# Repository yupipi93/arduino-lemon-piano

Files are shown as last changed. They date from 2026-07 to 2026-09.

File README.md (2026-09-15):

<div align="center">

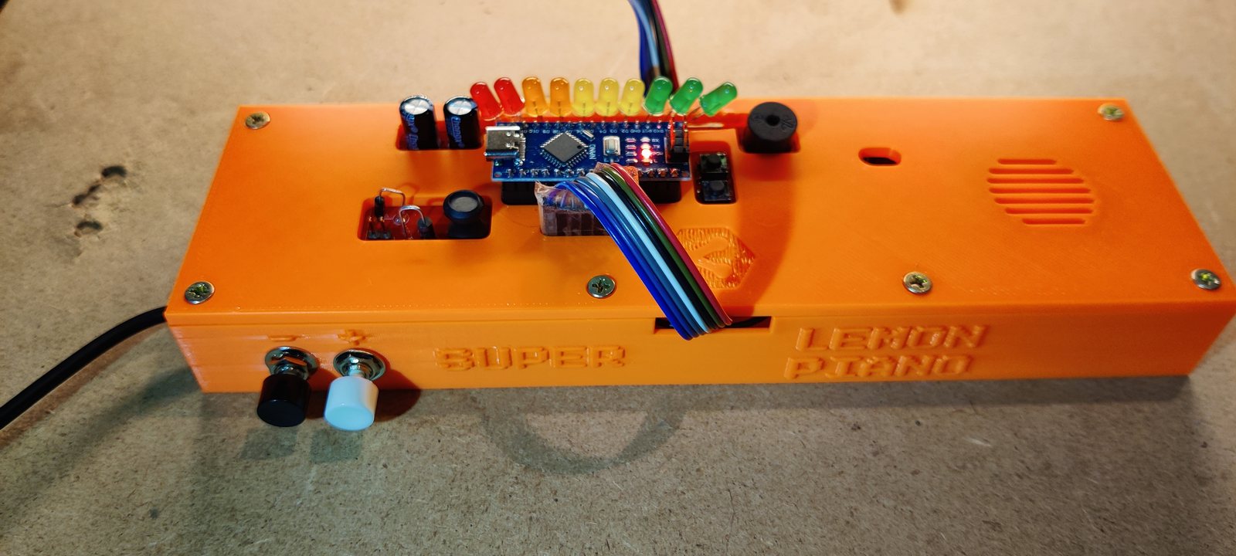
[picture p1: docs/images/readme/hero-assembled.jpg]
The assembled Super Lemon Piano: an orange 3D-printed case with a ten-LED bar, an Arduino Nano, the power-entry filter and a ribbon cable heading out to seven lemons


# 🍋 Super Lemon Piano

**Seven lemons, an Arduino Nano and a secret Mario melody.**
A 2019 university project, rescued in 2026 and still growing — nine boards, a
fabricable PCB, a printed case, and a firmware that is tested on a fake board
before it ever touches fruit.








</div>

---

## What it is

Hold a ground clip in one hand and touch a lemon with the other: your body closes
the circuit, the pin drops **three or four ADC counts**, and a note sounds. Seven
lemons make a keyboard. Each of the **four levels** hides a ten-note Mario melody
— the game plays you the hook, you find the notes, and ten green LEDs count how
close you are. Get it and the whole theme plays as a celebration; miss and the bar
blanks and you start that level again. There is also a fifth mode with no game in
it at all, where the lemons are simply *do re mi fa sol la si*.

The repo is organised as **one directory per hardware revision, all of them
active**. Nothing is archived: a bare-buzzer bring-up rig, the 2019 banana-piano
original, the water-pump build that was handed in at university, and today's
filtered ten-LED board each keep their own firmware, wiring diagram, emulation and
docs — and each is expected to build.

| Read | For |
|---|---|
| [**USER-GUIDE.md**](docs/USER-GUIDE.md) · [en español](docs/GUIA-DE-USO.es.md) | Playing it. The printable sheet — no electronics in it |
| [**versions/**](versions/) | The nine boards, what changed between them, and why |
| [**pcb/**](pcb/) | The fabricable KiCad 9 board, its renders and its gerbers |
| [**docs/HARDWARE.md**](docs/HARDWARE.md) | Touch physics, the polarity flip, the shared parts |
| [**docs/MARIO-SOUNDS.md**](docs/MARIO-SOUNDS.md) | Every melody and effect, with its provenance |
| [**docs/cartilla/**](docs/cartilla/) | The one-page folded booklet an organiser carries to an event |
| [**CHANGELOG.md**](CHANGELOG.md) · [TODO.md](TODO.md) | What changed, and what is still open |

---

## The thing itself

<div align="center">
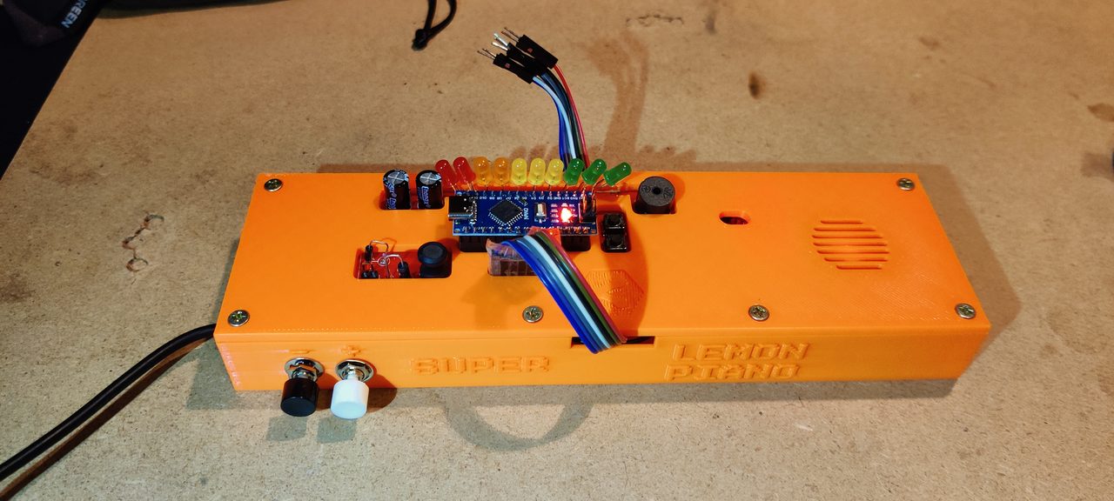
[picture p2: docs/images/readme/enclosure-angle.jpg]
The orange printed case from an angle, showing the SUPER LEMON PIANO lettering, the speaker grille and the two sensitivity buttons

<br/><em><b>SUPER LEMON PIANO</b> — printed case, ten-LED bar, passive buzzer behind the grille,<br/>two sensitivity buttons on the front, and a ribbon cable out to the fruit.</em>
</div>

<table>
<tr>
<td width="50%">
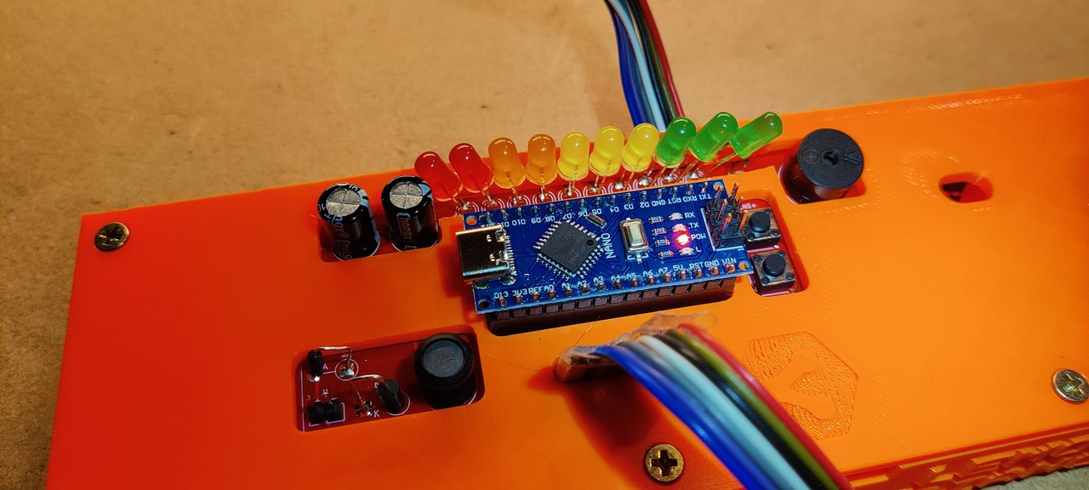
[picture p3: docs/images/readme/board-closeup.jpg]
Close-up of the Nano, the ten-LED bar and the two 470 µF filter capacitors

<br/><em>The ten LEDs run red → yellow → green, so how far you are is readable across a room. Left of the Nano: the 470 µF halves of the CLC pi filter.</em>
</td>
<td width="50%">
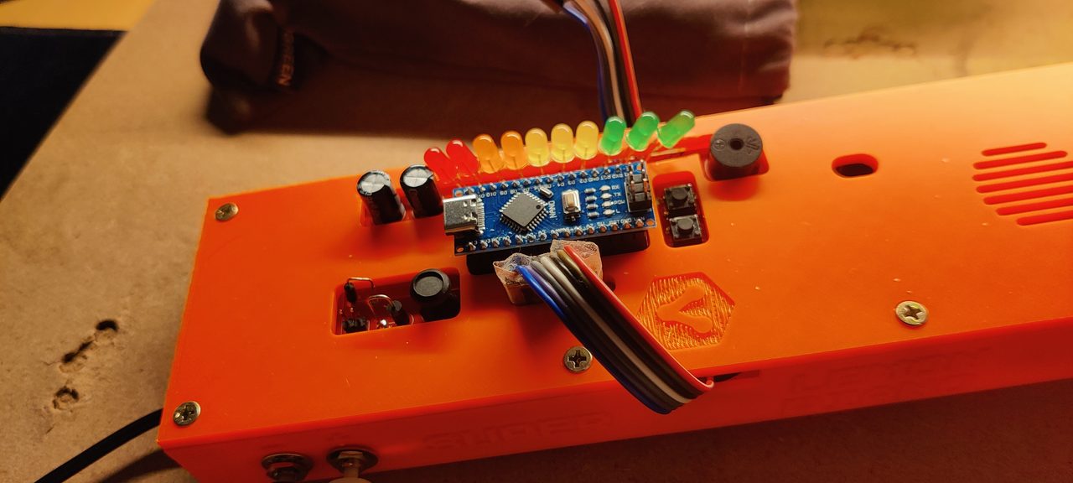
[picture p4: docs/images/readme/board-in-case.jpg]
The board seated in the printed case, with the Multitec logo embossed in the lid

<br/><em>Seated in the case, with the Multitec logo embossed in the print. The ribbon leaves through a slot so the lid closes on a working piano.</em>
</td>
</tr>
</table>

### The PCB

<div align="center">
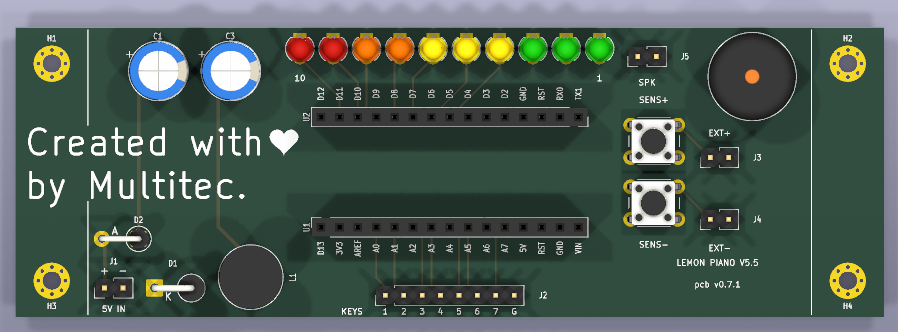
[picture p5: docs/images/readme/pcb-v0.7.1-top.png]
3D render of the v0.7.1 board, top: ten LEDs along the north edge, the socketed Nano, the two sensitivity buttons and the buzzer

<br/><em>v0.7.1, top — LEDs north, keys south, Nano socketed with the USB facing west.</em>
<br/><br/>
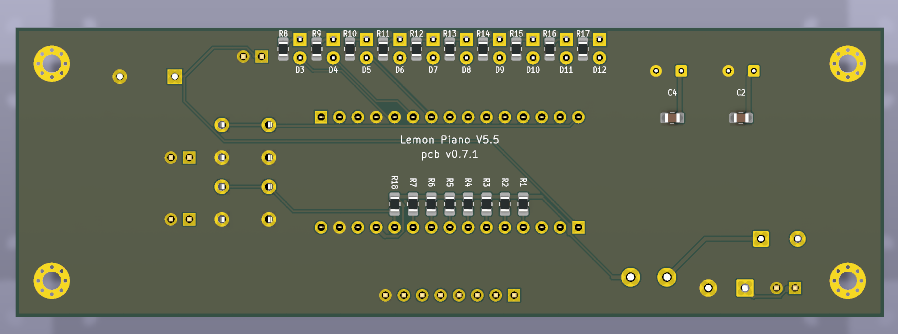
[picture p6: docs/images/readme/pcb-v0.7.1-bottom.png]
3D render of the v0.7.1 board, bottom: the ground pour and the 220 ohm resistors

<br/><em>Bottom — a full ground pour, and every 220 Ω pull-up on B.Cu.</em>
</div>

<div align="center">
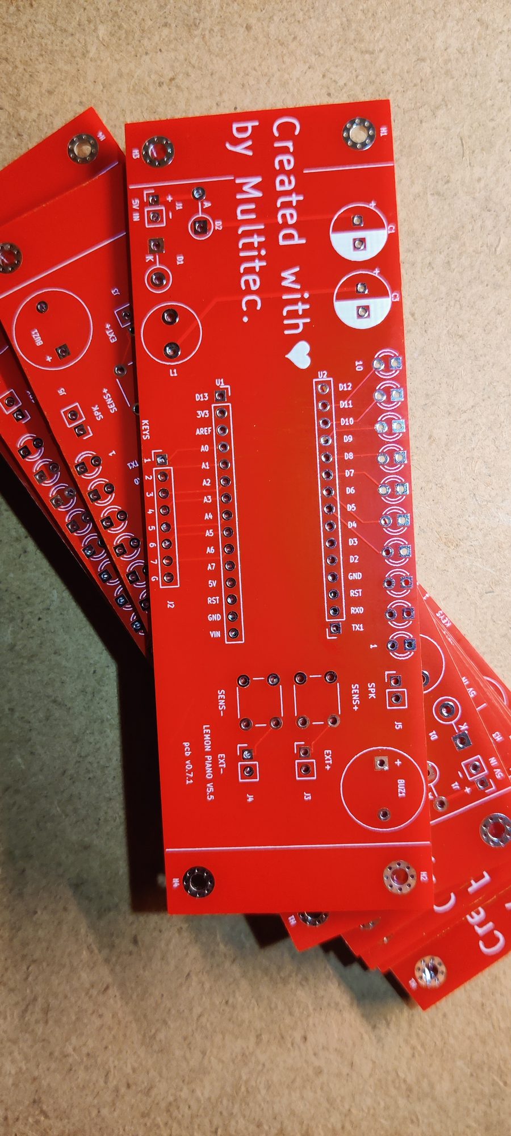
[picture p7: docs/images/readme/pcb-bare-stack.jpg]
A stack of bare red PCBs as they came back from the fab house, silkscreen reading Created with love by Multitec

<br/><em>Back from the fab house. <b>Created with ♥ by Multitec.</b></em>
</div>

---

## How it plays

1. **Power on.** The bar counts up while the firmware measures what *untouched*
   looks like on every lemon and derives the touch margin from the noise it finds.
   **Lights running = hands off the fruit.**
2. **It announces the level** with seven notes of that level's theme — and only
   notes your lemons can make (see *Three sizes of every song* below).
3. **Play.** Hold the GND clip, touch a lemon. The note sounds and holds for as
   long as you hold the fruit.
4. **Find the ten-note code.** Each correct note lights the next green LED. A
   wrong note blanks all ten and that level restarts. Nothing is punished until
   you have found the first note, so you can explore freely.
5. **Light all ten** and the level's **whole theme** plays as a celebration, then
   the flagpole fanfare, then the next level announces itself.
6. **Forgotten the tune?** **Tap the same lemon five times** and it plays again.

### The gestures

| Gesture | What it does |
|---|---|
| **tap +** / **tap −** | one step more / less sensitive — the bar shows where the knob sits |
| **hold + for 3 s** | switch between **free play** and the level you were on |
| **hold − for 3 s** | open the **mode wheel**: turn with + / −, accept with both buttons |
| **both buttons, 1 s**, while touching a lemon | **smart adjust** — learn the best margin from that real touch |
| **the same lemon ×5** | **play the level's tune again**. The note you just played counts as the first, so it is four more taps. It changes nothing: repeats never score |

### Free play

Hold **+** for three seconds and the game gets out of the way: the seven lemons
become `do re mi fa sol la si` (C5–B5), there is no code and no wrong note, and
**the same lemon may be played over and over** — which is exactly what the game
forbids, and exactly what an instrument is for.

The bar in free play **only ever moves**. Entering runs a sweep: two lights walk
in from the ends of the bar, meet in the middle, open back out until all ten are
lit, and go out. After that it is dark, and every note breaks a **wave** from that
lemon's own place on the bar — lemon 1 sends it left to right, lemon 7 right to
left, a lemon in the middle opens it both ways at once. Hold two lemons together
and both notes sound: one buzzer cannot hold two frequencies, so the voices swap
it every 10 ms, fast enough that the ear hears an interval instead of an
alternation.

### Three sizes of every song

Each theme exists at three lengths, because three different moments need three
different things:

| Size | Where | What it is |
|---|---|---|
| **Short** | the mode wheel | eight notes. Browsing four modes has to be fast |
| **Playable** | the level announcement, and the five-tap reminder | **seven notes, and only notes that level's lemons can make** |
| **Full** | the celebration when a level is cleared | the whole piece, 10–23 s |

The middle one is the clue, so it must not be full of notes the keyboard cannot
answer with — every theme reaches pitches that are on no lemon. The firmware
walks the theme, plays only what the level's row contains, and turns anything
else into silence of the same length so the rhythm of the hook survives. It lands
on each theme's actual hook, which is a pleasant accident of how Mario wrote them:

| Level | Theme | What it announces | The seven lemons, low → high |
|---|---|---|---|
| 1 | Overworld | `E7 E7 E7 C7 E7 G7 G6` — the riff, exactly | E6 G6 A6 B6 C7 E7 G7 |
| 2 | Underworld | `C4 C5 A3 A4 AS3 AS4 C4` | A3 AS3 C4 D4 A4 AS4 C5 |
| 3 | Starman | `C6 F5 F5 D5 F5 F5 D5` | C5 D5 E5 F5 G5 A5 C6 |
| 4 | Castle | `G3 D4 G3 D4 AS3 D4 AS3` — the pedal | G3 AS3 C4 D4 DS4 F4 G4 |

**Every lemon on every level is a note that level's own theme plays.** That is a
rule with a test behind it, not a convention — it was broken on levels 2, 3 and 4
until 2026-09-15, and level 4 answered a G-minor theme with a C major scale an
octave up.

<details>
<summary><b>The four secret codes (spoilers)</b></summary>

<br/>

Lemons numbered 1–7, left to right — lemon 1 is the one that sounds **lowest**.

| Level | Theme | Code |
|---|---|---|
| 1 | Super Mario Bros — Overworld | `6 · 5 · 6 · 7 · 2 · 5 · 2 · 1 · 3 · 4` |
| 2 | Super Mario Bros — Underworld | `3 · 6 · 1 · 4 · 2 · 5 · 3 · 6 · 1 · 4` |
| 3 | Super Mario Bros — Starman | `2 · 4 · 6 · 1 · 5 · 3 · 7 · 4 · 2 · 6` |
| 4 | Super Mario Bros — Castle | `5 · 1 · 3 · 7 · 2 · 6 · 4 · 1 · 5 · 3` |

Clear all four and the game-complete piece loops until you hold both buttons.

These numbers are **never typed by hand**. A level's code lives in the firmware as
note *frequencies*, and which lemon plays which note differs per level, so the
answer exists nowhere in the source. [`docs/cartilla/seqs.py`](docs/cartilla/seqs.py)
resolves one table against the other, cross-checks level 1 against a sequence the
host test declares independently, and exits non-zero rather than guess.

</details>

---

## The modes, as a machine

```mermaid
stateDiagram-v2
    direction LR
    state "FREE PLAY<br/>do re mi fa sol la si" as FreePlay
    state "MODE WHEEL<br/>four levels, previewed" as Wheel

    [*] --> Calibrate
    Calibrate --> Game : margin from measured noise

    state "GAME" as Game {
        [*] --> Level1
        Level1 --> Level2 : all ten LEDs
        Level2 --> Level3 : all ten LEDs
        Level3 --> Level4 : all ten LEDs
        Level4 --> Ending : all four cleared
        Ending --> Level1 : both buttons 1 s
    }

    Game --> FreePlay : hold + for 3 s
    FreePlay --> Game : hold + for 3 s
    Game --> Wheel : hold − for 3 s
    Wheel --> Game : both buttons = accept
    Wheel --> Game : long press = cancel
```

Free play is **chosen, never earned**: winning cycles 1 → 2 → 3 → 4 → 1 and never
lands on it.

---

## Hardware

<div align="center">
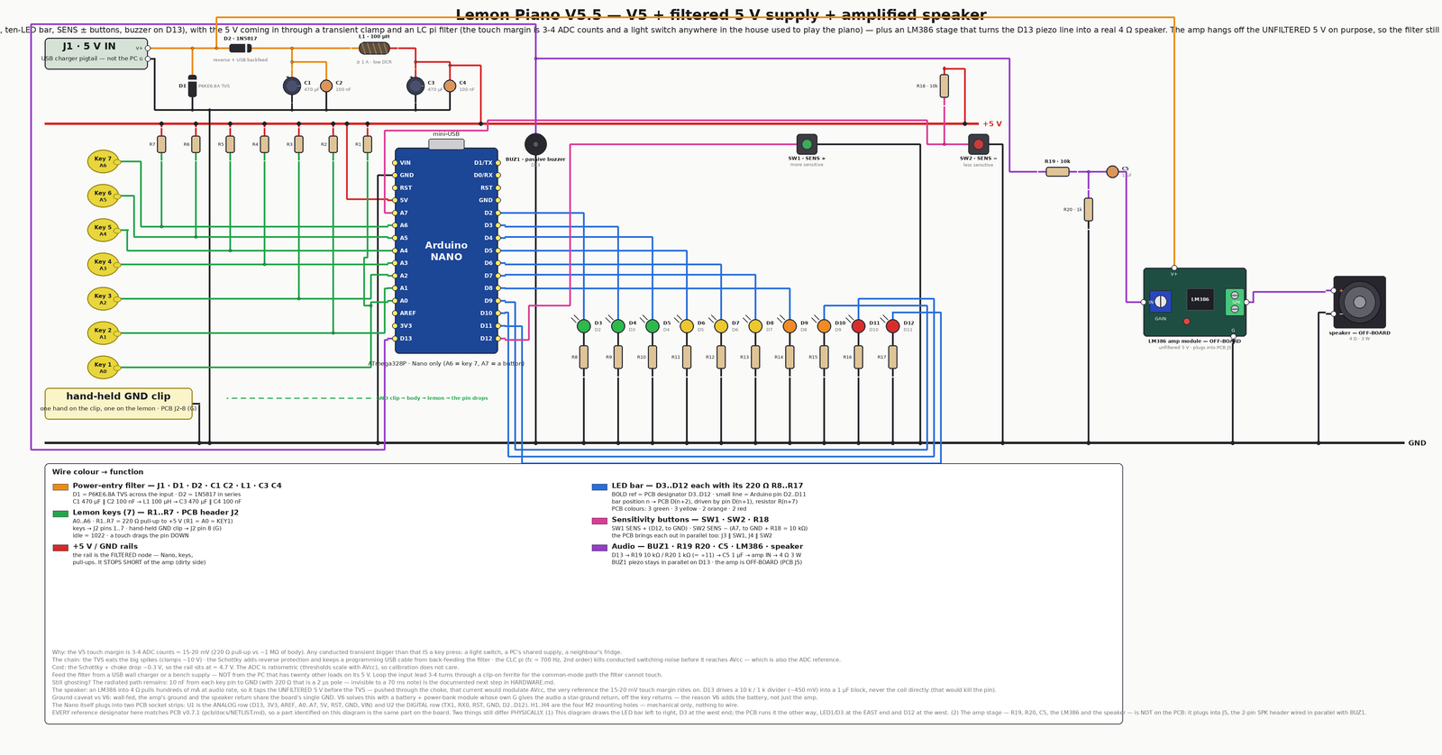
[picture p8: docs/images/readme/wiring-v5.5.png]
Generated wiring diagram of the V5.5 board: Nano, seven lemon keys with 220 ohm pull-ups, ten LEDs, two buttons, buzzer and the power-entry filter

<br/><em>Every wiring diagram in this repo is <b>generated</b>, never hand-placed — see below.</em>
</div>

### Pin map (V5.5)

| Pin | What | Notes |
|---|---|---|
| `A0`–`A6` | lemon keys 1–7 | 220 Ω pull-up each; the player holds the **GND** clip |
| `D2`–`D11` | the ten-LED bar | LED *n* on pin *n+1* — nothing to look up |
| `D12` | **SENS +** button | to GND, internal pull-up |
| `A7` | **SENS −** button | analog-in only, so an external 10 kΩ pull-up; read as `< 512` |
| `D13` | passive buzzer | the Nano's own LED blinks with the audio, for free |

Needs a **Nano or Mini**: A6 is a key and A7 is a button, and the classic Uno
exposes neither.

### The board

| | |
|---|---|
| **Outline** | 120 × 40 mm, 2-layer FR4, 4 × M2 mounting |
| **MCU** | Arduino Nano, socketed, centred, mini-USB facing west |
| **Display** | 10 × Ø3 mm LEDs, north edge — 3 green, 3 yellow, 2 orange, 2 red |
| **Keys** | 1×8 header on the south edge, silk reads `KEYS 1 2 3 4 5 6 7 G` |
| **Sound** | passive buzzer + an `SPK` aux header in parallel with it |
| **Power** | `5V IN` → P6KE6.8A TVS → 1N5817 → 470 µF‖100 nF → 100 µH → 470 µF‖100 nF |
| **Status** | v0.7.1 — DRC 0/0/0, ERC 0/0, placement 74/0, geometry gate 30/30 |
| **Fab** | [`pcb/releases/v0.7.1/`](pcb/releases/v0.7.1/) — gerbers, drill, BOM, positions |

<details>
<summary><b>Why there is a filter on a 5 V input at all</b></summary>

<br/>

A touch is **3–4 ADC counts, about 15–20 mV** — skin is roughly 1 MΩ against a
220 Ω pull-up, which is a very lopsided divider. The +5 V rail is simultaneously
the top of all seven pull-ups **and AVcc, the ADC's own reference**. A slow sag
cancels out, because the ADC is ratiometric and baseline and reading move
together. A **fast edge does not**: the pin node sits behind 220 Ω and wire
capacitance while the reference goes straight into AVcc, so the two move at
different speeds and the difference lands squarely inside a 15 mV margin.

Which is not theory. A light switch elsewhere in the house played phantom notes.
The filter (TVS + Schottky + CLC pi, fc ≈ 730 Hz) is V5.5's entire hardware
delta; the game and the firmware pinout are V5's, untouched.

Full derivation: [`versions/v5.5-power-filter/HARDWARE.md`](versions/v5.5-power-filter/HARDWARE.md).
Running it off a battery instead: [`docs/POWER-FROM-A-POWER-BANK.md`](docs/POWER-FROM-A-POWER-BANK.md).

</details>

---

## Quick start

```bash
# PlatformIO CLI, once
pipx install platformio                 # or: pip install --user platformio

cd versions/v5.5-power-filter/firmware  # ...or any other version's firmware/
pio run                                 # build  (default: nanoatmega328)
pio run -t upload                       # flash the Nano
pio device monitor                      # 9600 baud — the game logs what it is doing
```

No hardware is needed to build: `pio run` is the compile check every commit goes
through, and **every version in this repo still builds**, including the 2019
sketches.

```bash
bash versions/v5.5-power-filter/firmware/test/run.sh   # 281 checks, plain g++, exit 0
python3 tools/wiring_diagrams.py                       # re-render every wiring diagram
python3 docs/cartilla/seqs.py                          # re-derive the four codes
```

<details>
<summary><b>Upload fails, or something sounds wrong</b></summary>

<br/>

**"programmer is not responding"** — most 2019-era Nano clones carry the old
bootloader (57600 baud) and newer ones the new one (115200):

```bash
pio run -e nanoatmega328new -t upload
```

**The sound is suspect** — flash [**V0**](versions/v0-buzzer/), a board with
nothing on it but the buzzer, playing a scale forever on the same pin every
version uses. It removes the keyboard, the sensing and the game in one step:

```bash
cd versions/v0-buzzer/firmware && pio run -t upload && pio device monitor
```

**Touches register wrongly, or not at all** — flash
[**V2.5**](versions/v2.5-threshold-buttons/): V2's keyboard plus two buttons that
move the touch threshold live, with a serial readout of all seven channels
against it. Or build V5.5 with `-DDEBUG_TOUCH`, which prints every channel's dip
four times a second while a lemon is held.

</details>

---

## The nine boards

The numbers follow the **boards, not the calendar**: V4.5 is V4 minus the pump
plus two buttons, so it sits before V5 even though it was wired later.

| # | Version | Hardware delta | Firmware | Emulation |
|---|---|---|---|---|
| 0 | [**V0** — buzzer rig](versions/v0-buzzer/) | *bring-up (2026)*: one passive buzzer and nothing else | ✅ | ✅ |
| 1 | [**V1** — banana piano](versions/v1-banana-piano/) | *the 2019 origin*: 7 fruit keys, 220 Ω pull-ups, HC-SR04 | ✅ | — |
| 2 | [**V2** — keyboard test](versions/v2-keyboard-test/) | − HC-SR04: the keyboard and speaker alone | ✅ | — |
| 2.5 | [**V2.5** — live threshold](versions/v2.5-threshold-buttons/) | + 2 buttons that move the touch threshold **while it runs** | ✅ | ✅ |
| 3 | [**V3** — game prototype](versions/v3-game-prototype/) | + feedback LEDs, game-select button, one relay — the game is born | ✅ | — |
| 4 | [**V4** — water pump](versions/v4-water-pump/) | clip flips to +5 V, 2nd relay + **water pump**, RESTART | ✅ | ✅ |
| 5 | [**V4.5** — margin buttons](versions/v4.5-margin-buttons/) | − relays and pump · + MARGIN +/− buttons | ✅ | ✅ |
| 6 | [**V5** — LED bar](versions/v5-led-bar/) | keyboard back to pull-ups + GND clip · + **ten LEDs** | ✅ | ✅ |
| 7 | [**V5.5** — power filter](versions/v5.5-power-filter/) ⭐ | + **filtered 5 V input**. The board this repo is about | ✅ | ✅ + host tests |
| 8 | [**V6** — battery + amp](versions/v6-battery-amp/) 📐 | *proposal only*: LiPo + power-bank module, LM386 + speaker | — | — |

The rule for adding one, and the checklist: [`docs/VERSIONING.md`](docs/VERSIONING.md).

---

## How this repo keeps itself honest

**The firmware is tested on a fake board.** `test/piano_sim_test.cpp` compiles
`src/main.cpp` *verbatim* against a stand-in AVR runtime with virtual time, seven
analog touch channels with noise and **channel coupling**, two buttons and ten
LEDs — then plays the piano and asserts what came out. It models the ADC's
sample-and-hold settling on a 1 MΩ source, flaky finger contact, and one finger
shadowing its neighbours, because all three have caused real bugs. It records the
LED bar as a **film** rather than a snapshot, so animations are assertable, and it
counts buzzer pin edges, because themes are bit-banged and leave no other trace.

**281 checks, 0 failed.** It has caught, among others: a gesture that would have
fired on every note on a coupled rig, a chord that could never be released, and a
level whose lemons were in the wrong key.

**Every wiring diagram is generated.** [`tools/wiring_diagrams.py`](tools/wiring_diagrams.py)
is a declarative contract — components, positions, nets — consumed by the
**wirewright** auto-router and DRC engine. No wire crosses a component, overlaps
another net, or leaves a pin unconnected, because the renderer refuses.

**The PCB is generated and gated too.** Place, route, DRC, render and fab outputs
come from the sibling `eda-pcb-designer` toolkit, and a release only exists if
DRC, ERC, placement and a geometry gate all pass.

---

## Take it to an event

<table>
<tr>
<td width="42%" align="center">
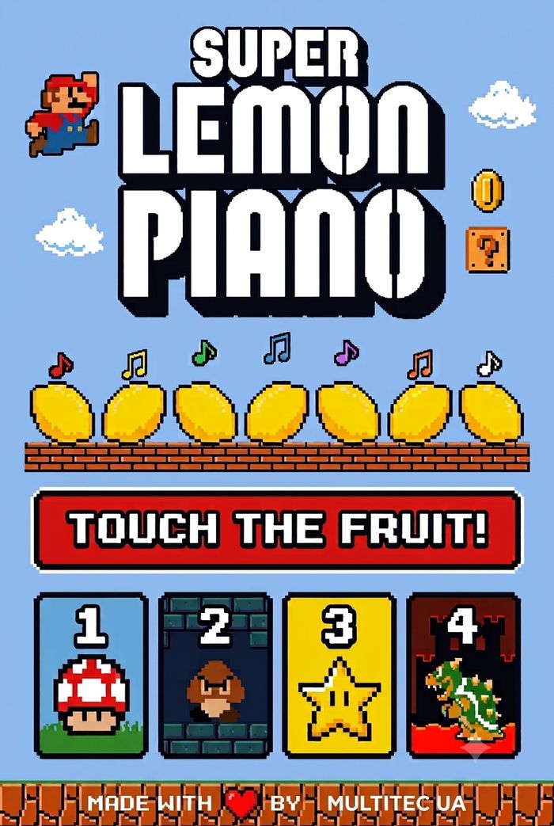
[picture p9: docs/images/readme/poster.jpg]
Event poster: SUPER LIMÓN PIANO in Mario lettering over a pile of lemons

<br/><em><a href="docs/poster/">The poster</a> — stored byte for byte,<br/>hash-pinned so a later re-encode is visible.</em>
</td>
<td width="58%">

**The booklet.** One A4 sheet, black and white, folded down the middle into an
A5: the cover, what the two buttons do, *si algo va mal*, how the game works, and
the four codes. Almost no prose — nearly every explanation is a drawing of the
**LED bar itself**, ten boxes filled or empty, because that is the only thing the
piano can say and the only thing a helper has to read.

It exists so someone who has never seen the lemon piano can switch it on, explain
it and rescue it with nobody technical in the room.

```bash
docs/cartilla/build.sh      # re-derives the codes from the firmware, then renders
```

→ [`docs/cartilla/`](docs/cartilla/)

</td>
</tr>
</table>

---

## Status

- **V5.5 is built, cased and playing.** Firmware 17 998 B (58.6 % flash),
  558 B RAM (27.2 %), flashed and verified.
- **Open, and honest about it:** the chord's gates and the free-play wave timing
  are tuned from the physics and from host tests, and still want a session with
  fingers on real fruit. The `-DDEBUG_TOUCH` build prints the numbers needed to
  settle both. See [TODO.md](TODO.md) items 21–23.
- **The Velxio browser emulation** covers V0, V2.5, V4, V4.5 and V5; V5.5's own
  spec is written but has never had a `--mode verify` pass, because the harness is
  not installed on the machine it was written on.
- **No LICENSE file yet.** Ask before reusing.

---

<div align="center">

**Author:** Yupipi93 (Sergio Conejero), 2019
**Rescued, reworked, documented and tested with Claude,** 2026
Built at [**Multitec**](https://multitecua.com) 🍋

</div>

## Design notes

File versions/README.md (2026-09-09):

# Versions — every board, all active

One directory per **hardware revision**. Nothing here is archived or frozen: each
version keeps its own firmware, emulation, wiring diagram and docs, and each is
expected to build and (where the browser emulator can host it) run.

The rule and the recipe for adding one: [../docs/VERSIONING.md](../docs/VERSIONING.md).

| # | Version | Board | Hardware delta vs previous | Firmware | Emulation | Diagram |
|---|---|---|---|---|---|---|
| 0 | [v0-buzzer](v0-buzzer/) | any Nano / Uno | *bring-up rig (2026)*: one passive buzzer on D8, nothing else | ✅ 5 envs | ✅ verify green | [wiring-v0](v0-buzzer/images/wiring-v0.png) |
| 1 | [v1-banana-piano](v1-banana-piano/) | Uno (2019) · Nano for key 7 | *the 2019 origin*: + 7 fruit keys + 220 Ω pull-ups, + HC-SR04 (buzzer already on D8) | ✅ builds | — [why](v1-banana-piano/emulation/README.md) | [wiring-v1](v1-banana-piano/images/wiring-v1.png) |
| 2 | [v2-keyboard-test](v2-keyboard-test/) | Uno · Nano for key 7 | − HC-SR04 (keyboard + speaker only) | ✅ builds | — [why](v2-keyboard-test/emulation/README.md) | [wiring-v2](v2-keyboard-test/images/wiring-v2.png) |
| 2.5 | [v2.5-threshold-buttons](v2.5-threshold-buttons/) | Uno · Nano for key 7 | + 2 buttons (D10/D11, to GND) that tune the touch threshold live; serial readout on | ✅ 4 envs | ✅ verify green | [wiring-v2.5](v2.5-threshold-buttons/images/wiring-v2.5.png) |
| 3 | [v3-game-prototype](v3-game-prototype/) | Uno · Nano for key 7 | + red LED D2, green LED D3, game button D4, 1 relay D5 | ✅ builds | — [why](v3-game-prototype/emulation/README.md) | [wiring-v3](v3-game-prototype/images/wiring-v3.png) |
| 4 | [v4-water-pump](v4-water-pump/) | **Nano** | clip flips to **+5 V** (sensing inverted) · + 2nd relay channel + water pump · + RESTART D7 · SPDT game select | ✅ 4 envs | ✅ verify green | [wiring-v4](v4-water-pump/images/wiring-v4.png) |
| 5 | [v4.5-margin-buttons](v4.5-margin-buttons/) | Nano | **− relay pair + water pump** (D5/D6 free) · + MARGIN + (D10) / MARGIN − (D11) buttons | ✅ 4 envs | ✅ verify green | [wiring-v4.5](v4.5-margin-buttons/images/wiring-v4.5.png) |
| 6 | [v5-led-bar](v5-led-bar/) | Nano only (A6+A7) | keyboard back to **220 Ω pull-ups + GND clip** · − red LED, − MARGIN buttons, − game-select, − restart · + **ten green LEDs** · + 2 sensitivity buttons (D7/A7) | ✅ 4 envs | ✅ 3 specs green | [wiring-v5](v5-led-bar/images/wiring-v5.png) |
| 7 | [v5.5-power-filter](v5.5-power-filter/) | Nano only (A6+A7) | + **power-entry filter** on the 5 V input (TVS + Schottky + CLC pi, fc ≈ 700 Hz) — board otherwise identical to V5. **Firmware-only since 2026-09-09: free play + the mode wheel** | ✅ 5 envs | V5's ([why](v5.5-power-filter/emulation/README.md)) + **host tests** (`firmware/test/run.sh`) | [wiring-v5.5](v5.5-power-filter/images/wiring-v5.5.png) |

**Newest board: [V5.5](v5.5-power-filter/).** Change the hardware and the next directory is
`v6-<what-changed>/`.

## Three things worth knowing

- **V0 and V2.5 are instruments, not history.** V1–V5 are the real lineage; V0
  (bare buzzer) and V2.5 (keyboard + live threshold) were built in 2026 to measure
  the thing that was misbehaving. Both are numbered where their *board* sits.
- **V0 is a diagnostic, not history.** V1–V5 are the real lineage; V0 was built in
  2026 to isolate the buzzer from everything else. It is numbered 0 because its
  board is a subset of every other one. Flash it whenever you doubt the sound.

- **The numbers follow the boards, not the calendar.** V1–V4 are 2019; V5 was
  built on 2026-07-14 and V4.5 on 2026-07-25/26 — V4.5 is "between" V4 and V5
  because its *board* is (V4 minus the pump, plus two buttons), even though it was
  wired last.
- **The 2019 boards have no emulation on purpose.** Hosting them in the browser
  AVR would mean editing 2019 sketches (buzzer onto a PWM pin, key 7 off A6);
  each version's `emulation/README.md` spells out exactly what it would take, and
  the decision is open in [../TODO.md](../TODO.md).

## Quick tour of one version

```
versions/v5-led-bar/
├── README.md      ← what this board is, its hardware delta, how to play/build
├── HARDWARE.md    ← pin map, BOM, wiring detail, ⚠️ deductions
├── firmware/      ← PlatformIO project (builds in place: cd firmware && pio run)
├── emulation/     ← Velxio spec + generated .vlx + how to verify it
└── images/        ← wiring-v5.png, rendered by the wirewright engine
```

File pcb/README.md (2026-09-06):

# Lemon Piano V5.5 Board

A fabricable 2-layer KiCad-9 PCB that replaces the
[V5.5](../versions/v5.5-power-filter) breadboard build of this repo — same circuit, same firmware pinout, nothing invented. Seven lemon
touch keys, a ten-LED progress bar, two sensitivity buttons, a passive
buzzer, and the V5.5 **power-entry filter** (TVS + Schottky + CLC pi) that
keeps mains transients from playing phantom notes on a 15–20 mV touch
margin.

| | |
|---|---|
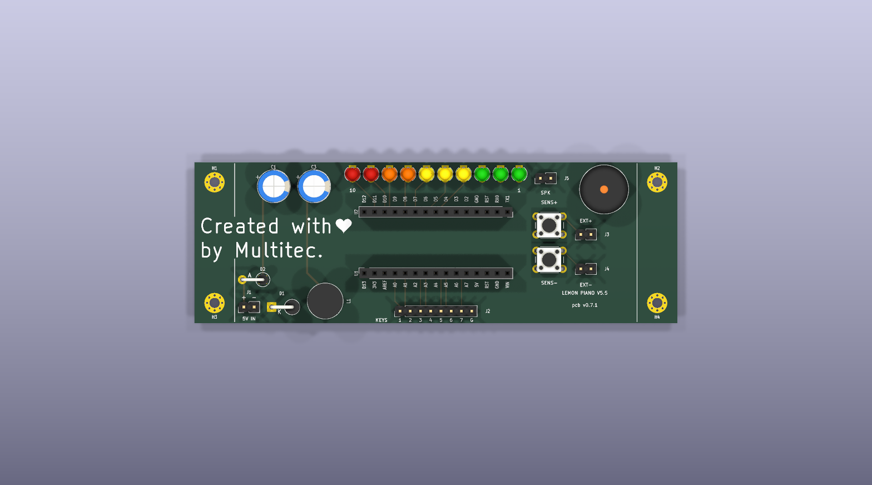
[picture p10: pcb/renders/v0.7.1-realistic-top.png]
realistic top
| Realistic (3D bodies) |  |
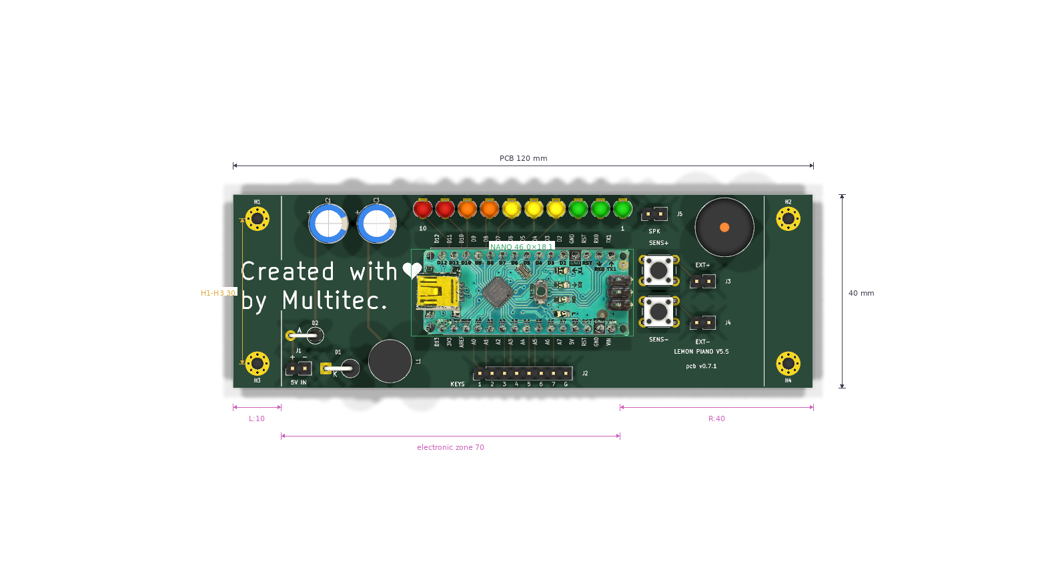
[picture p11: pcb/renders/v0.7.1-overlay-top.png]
overlay top
| Photo overlay (real Nano photo, dimensioned) |  |
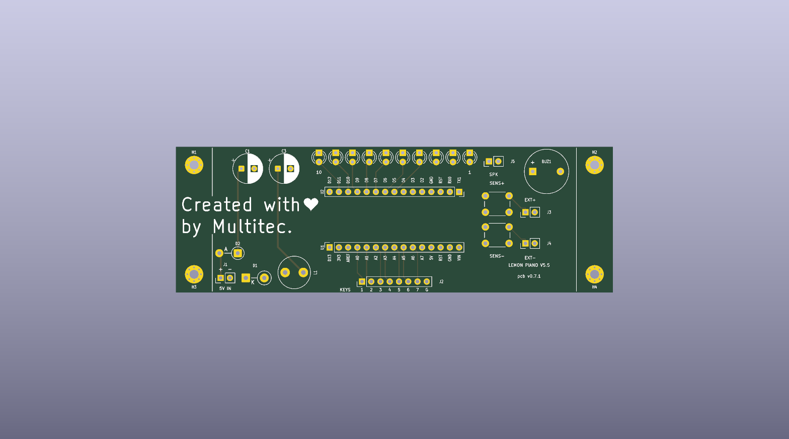
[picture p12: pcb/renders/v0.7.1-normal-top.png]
normal top
| Normal (bare copper/silk) |  |
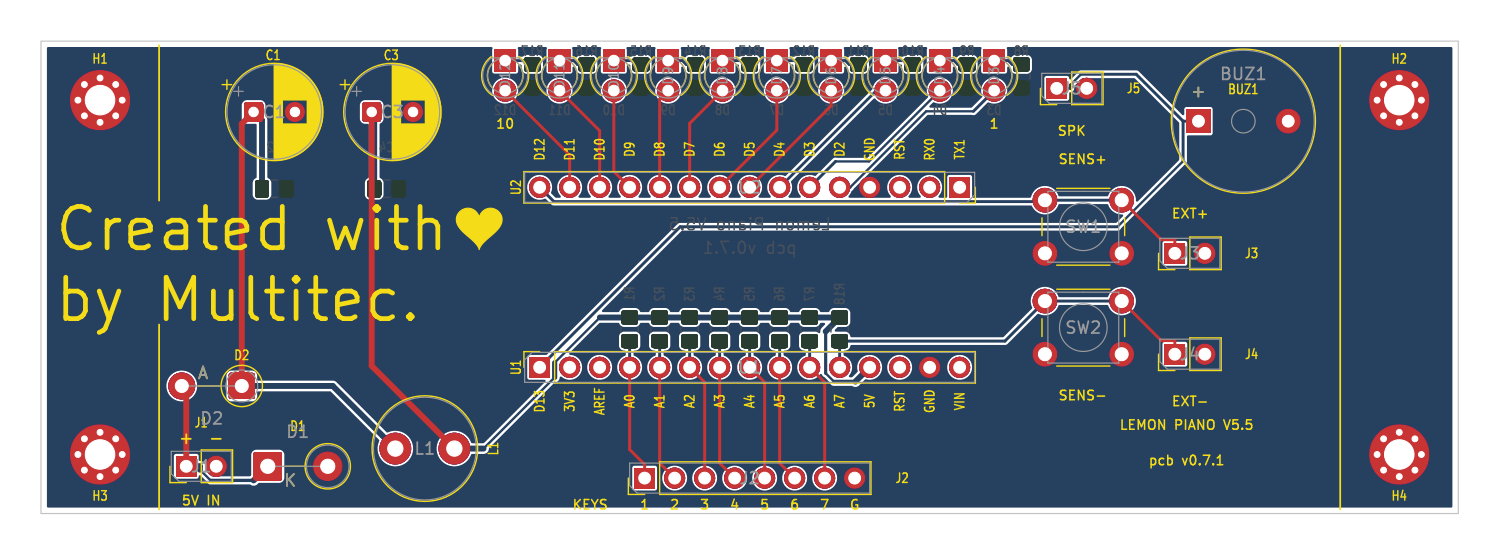
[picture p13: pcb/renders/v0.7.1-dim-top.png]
dim top
| DIM plot (front) |  |
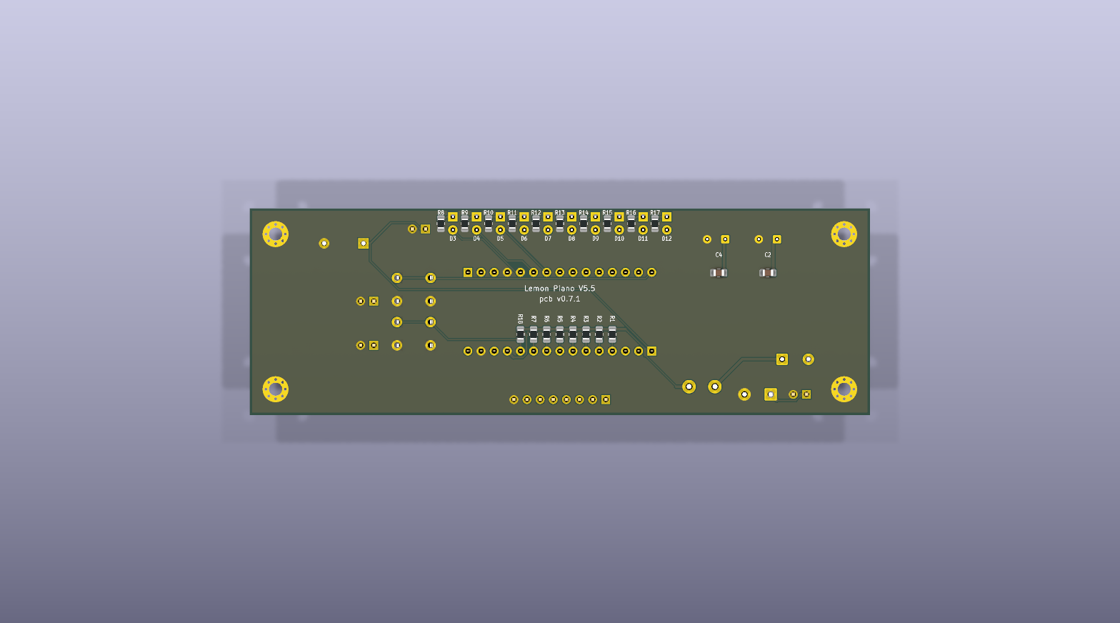
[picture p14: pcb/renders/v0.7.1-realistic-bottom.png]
realistic bottom
| Bottom (realistic) |  |

Per version the pipeline archives four styles per side under `renders/`
(`<ver>-{normal,dim,realistic,overlay}-{top,bottom}.png`), all produced
by the hosted pcb-designer API; the overlay composites the real Arduino
Nano photo (Wikimedia Commons, CC BY 2.0) that the pipeline uploads from
`overlays/component-images/` + `overlays/modules.yaml`. Every socket pin
carries its function on silk (MT1-style legends) and every component its
reference, both layers.

## At a glance

| Item | Value |
|---|---|
| Outline | **120 × 40 mm**, 2-layer FR4, MT1 coordinate frame (x 90–210, y 100–140, centre 150/120) |
| MCU | Arduino Nano (ATmega328P), **socketed, centred, mini-USB facing WEST** — 2×15-pin 2.54 mm rows (pin field x 132.22–167.78, rows y 112.38/127.62). USB-west puts the digital column on the north row and the analog column on the south row (LEDs north / keys south, ADR-035), and a **part-free cable corridor** (x < 130.4, y 113–127) lets the cable plug in with the module seated — for the enclosure. USB 5 V still stays behind the 1N5817 |
| Keys | 7 lemon lines (A0–A6, 220 Ω pull-ups on B.Cu) + GND clip → labelled 1×8 header **centred** on the **SOUTH** edge, pin 1 = KEY1 at the west so silk reads `KEYS 1 2 3 4 5 6 7 G` west→east (pin centre exactly x=150; the fan under A0..A6 does not cross, ADR-036) |
| Display | 10 × 3 mm LEDs (D2–D11): 3 green → 3 yellow → 2 orange → 2 red, **NORTH** edge, **centred on x=150**, **LED1 at the EAST** (the bar fills right→left with the USB on the left — it follows D2..D11, which descend west→east, ADR-036/021), 220 Ω each on B.Cu |
| Controls | SENS+ (D12) / SENS− (A7 + 10 k pull-up) buttons in the EAST block, the **pair centred on the y=120 mid-line**, each with a **parallel 2-pin header** (J3/J4) for an external panel button (ADR-026) |
| Sound | passive buzzer on D13, NE corner — ~60 mm from its pin (D13 is at the west end again; accepted in ADR-027). **`SPK`** (J5) is a 2-pin aux output wired in parallel with it (ADR-034) |
| Power | `5V IN` **2-pin header** → P6KE6.8A TVS → 1N5817 → 470 µF‖100 nF → 100 µH → 470 µF‖100 nF → +5 V rail (≈4.7 V, fc ≈ 730 Hz). Whole filter in the WEST block folded around the USB corridor: **C1 ‖ C3 adjacent** on the north row, D2 / J1 → D1 / L1 in the south strip (ADR-025/031/037) |
| GND | full B.Cu zone, solid connect on every GND pad, auto island-healing |
| Mounting | 4 × M2 (Ø2.5 drill / Ø5.0 pad+vias): two per short edge at x=95/205, y=105/135 — mirror-symmetric about x=150 and y=120 |
| Silk (v0.7.1) | **"Created with ♥ by Multitec."** maker's mark filling the top-left free rectangle (heart drawn as a filled silk polygon — the stroke font has no ♥ glyph); ADR-038 |
| Status (v0.7.1) | DRC **0/0/0** · ERC 0/0 · verify_placement 74/0 · verify_holes (+vision) · geometry_gate 30/30 ALL PASS |
| Release | [`releases/v0.7.1/lemon-piano-v0.7.1-fab.zip`](releases/v0.7.1/) — gerbers, drill, BOM, positions |

**Implementing a change?** Paste [docs/AGENT_PROMPT.md](docs/AGENT_PROMPT.md)
into a fresh agent session together with the change request — it encodes
the full workflow, gates and pitfalls learned across v0.0.1→v0.7.1.

Netlist ground truth: [docs/NETLIST.md](docs/NETLIST.md) ·
decisions: [docs/DECISIONS.md](docs/DECISIONS.md) ·
state + iteration log: [docs/DESIGN_STATE.md](docs/DESIGN_STATE.md) ·
render history: [renders/INDEX.md](renders/INDEX.md)

## How to regenerate

Everything is generated from [`lemon-piano.yaml`](lemon-piano.yaml) +
[`docs/NETLIST.md`](docs/NETLIST.md). The pcb-designer toolkit lives in the
sibling repo `../eda-pcb-designer` (its Docker image + hosted API); the
cloud service does every
pipeline operation that has an endpoint, the Docker image handles the two
generative steps (board/schematic instantiation) and the width/zone
post-pass:

```bash
# one full iteration: build → /place → /route → post → /drc → /render → gates
./pcb/tools/cloud_pipeline.sh v0.7.1

# release (adds cloud /fab, writes releases/<ver>/):
./pcb/tools/cloud_pipeline.sh v0.7.1 --fab

# render variants (any style, hosted API):
URL=https://pcb-designer.scv.multitecua.com
curl -F pcb=@pcb/kicad/lemon-piano.kicad_pcb "$URL/render?side=both&style=realistic" -o r.zip
curl -F pcb=@pcb/kicad/lemon-piano.kicad_pcb -F modules=@pcb/overlays/modules.yaml \
     -F images=@pcb/overlays/component-images/arduino-nano.png \
     "$URL/render?side=top&style=overlay&calibration=green_bbox" -o overlay.png

# individual gates:
python3 pcb/tools/verify_placement.py   # anti-mirror/pin-swap
python3 pcb/tools/verify_holes.py       # anchor holes vs GT
python3 pcb/tools/geometry_gate.py      # outline/symmetry/copper
```

All builders are idempotent — re-running produces byte-identical files
(LESSONS_LEARNED §7). The KiCad artefacts live in `kicad/`; every
iteration's DRC report and renders are archived under `validation/` and
`renders/` with their version tag.

## Look at the board in 3D

Every pipeline run writes a rotatable model to `pcb/3d/`, **committed to the
repo** so you can clone and look at the board with no KiCad toolchain at all:

| File | For |
|---|---|
| `lemon-piano-<ver>.glb` | looking at it: browsers, `f3d`, Windows/macOS 3D viewers |
| `lemon-piano-<ver>.step` | CAD — FreeCAD / Fusion, enclosure fit checks |

**In VS Code — one click.** This repo ships a
[`.vscode/extensions.json`](../.vscode/extensions.json) recommending
[`thingraph.cad-viewer`](https://marketplace.visualstudio.com/items?itemName=thingraph.cad-viewer),
so VS Code offers to install it the first time you open the project
(Extensions view → *Recommended*). Or explicitly:

```bash
code --install-extension thingraph.cad-viewer
```

Then **double-click `pcb/3d/lemon-piano-v0.7.1.glb`** — or the `.step` — and it
opens in a tab you can drag to rotate. It is the only extension that handles
both formats the pipeline emits, and it bundles `occt-import-js.wasm`
(OpenCascade), so STEP is a real geometry kernel. Free, read-only, ~24 MB.

> Don't reach for **glTF Tools** (`cesium.gltf-vscode`) instead just because it
> has 100× the installs: it validates and converts glTF/GLB but registers no
> viewer for `.glb`, so you'd have to import to `.gltf` first to see anything.

**Web, nothing to install** — open <https://3dviewer.net> and drag the `.glb`
in. Drag rotates, scroll zooms. It renders in your browser, so the file is not
uploaded to a server.

**Local, lightweight** — [f3d](https://f3d.app):

```bash
sudo apt install f3d
f3d pcb/3d/lemon-piano-v0.7.1.glb
```

Note these are binaries in git (~16 MB per version, and git history keeps
every past one forever — deleting them later does not shrink the repo). That
is a deliberate trade: the files are the whole point of having them, and a
handful of releases is well inside GitHub's limits. If it ever gets heavy, the
standard fix is Git LFS, not deletion. Only `pcb/3d/models/` stays untracked —
that is the fetched cache of verbatim third-party KiCad body files, which the
script re-downloads in seconds.

They will **not** preview on github.com: GitHub renders only `.stl` inline and
only up to 10 MB, and this board's STL is 34 MB. Download the `.glb` and open
it with one of the viewers above.

Generated by the cloud `/export3d` endpoint during
`cloud_pipeline.sh`, because the service image ships the `kicad-packages3d`
body library that the slim local Docker image deliberately omits. To make them
without the pipeline (fetches just the ~15 bodies this board needs, ~1.4 MB,
cached in `pcb/3d/models/`):

```bash
./pcb/tools/export_3d.sh
```

Note the two orange LEDs (D9/D10) show **red** in locally generated files —
no orange body exists in the upstream library, so the exporter falls back to
the base one and says so. The cloud-generated files have the real orange.

**KiCad's own viewer** is the richest option (layer toggles, cross-sections,
raytracing) but needs KiCad 9 installed. Ubuntu's repos only carry KiCad 7,
which cannot open this v9 board — use the PPA, and stay on the 9.x series so
the file format keeps matching the pipeline:

```bash
sudo add-apt-repository ppa:kicad/kicad-9.0-releases
sudo apt update && sudo apt install --install-recommends kicad kicad-packages3d
```

Then open `pcb/kicad/lemon-piano.kicad_pcb` and press **Alt+3**.

## Assembly notes

- Small passives are 0805 HandSolder; R1–R7/R18 and R8–R17 + C2/C4 mount
  on the **bottom** (refs on F.Fab, values in the BOM/pos files).
- Feed `5V IN` (J1, `+` west / `−` east) from a USB wall charger or bench
  supply — never the PC that flashes the Nano (see the V5.5 powering
  rules); loop the input lead 3–4 turns through a clip-on ferrite for the
  common-mode path. J1 is a bare header, so strain-relieve the input lead
  (zip-tie through a mounting hole) if the piano gets carried around.
- The GND terminal position (`G`, **east** end of the keys header, next to
  key 7) is the player's hand-held clip line.
- `EXT+` (J3) and `EXT−` (J4) are wired in parallel with the SENS+/SENS−
  buttons. Leave them empty for on-board-only use, or wire a panel button
  across each pair — no jumper to move, and both buttons keep working.
- **`SPK` (J5) is the aux sound output**, in parallel with the buzzer: pin 1
  is the raw D13 drive, pin 2 is GND. The on-board buzzer keeps sounding
  either way. **Mind the load** — D13 drives a *passive piezo* directly, so
  J5 suits another piezo element or an **amplified** speaker module
  (PAM8403 / LM386 board / powered PC speakers, all high-impedance inputs).
  A bare 4–8 Ω speaker would draw ~600 mA against the ATmega328P's 40 mA
  absolute maximum per pin and **would damage D13** — drive one only through
  an amplifier (ADR-034).
- **Flashing with the Nano seated.** The mini-USB faces WEST into a part-free
  corridor (x < 130.4, y 113–127 — ADR-035), so the cable plugs in past the
  C1/C3 row above and the D2/L1 parts below and leaves the board on the left,
  nowhere near the SENS buttons. Plan the enclosure's cut-out on that side.
  Tracks do run through the corridor (that is fine); never place a part there.
- **The VU meter fills right→left** when the USB is on your left: LED 1
  (green) is at the east end, LED 10 (red) at the west (ADR-036 — the bar
  follows the D2..D11 pins so no traces cross). Flip the board's orientation
  in the enclosure if you want green on the left, or ask for the reversed
  bar (a YAML change + re-route).

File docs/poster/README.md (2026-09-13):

# Poster — the sign that goes behind the piano

`super-limon-piano-cartel.png` is the poster Sergio put behind the lemon piano so
that people at the event walk over and play it. **He made it with Gemini on
2026-09-13** and asked for it to be kept here with no loss of quality.

It is stored **byte for byte as it came**, never re-encoded:

```
sha256  b8db4412b7b9a77b31b51f8a2a371763dbf7a310eab1b599980af863dad18f26
bytes   1 010 859
```

Anything that opens and re-saves this file — an editor, a "compress PNG" tool, a
chat app — will produce different bytes. If that hash stops matching, the file
was touched and the original is gone.

## What is on it

Pixel-art Super Mario Bros. styling: the **SUPER LEMON PIANO** wordmark, Mario,
seven lemons on a brick ledge with a note over each one, **TOUCH THE FRUIT!**,
and the four levels as numbered cards — 1 mushroom, 2 Goomba, 3 star, 4 Bowser,
which is the order the firmware plays them in (Overworld, Underworld, Starman,
Castle). Footer: `MADE WITH ❤ BY MULTITEC UA`.

## Printing it — the honest numbers

```
848 x 1264 px, 8-bit RGB, no alpha
```

That resolution is fixed, and there is no clean way to enlarge it. It is pixel
art in *style* only — **102 156 distinct colours**, with soft, anti-aliased
edges — so a nearest-neighbour upscale (which is lossless on real pixel art)
would only magnify the softness. What comes out of the printer depends entirely
on how big it is printed:

| printed at | effective | how it looks |
|---|---|---|
| 72 × 107 mm | 300 dpi | crisp at arm's length |
| 108 × 161 mm | 200 dpi | crisp |
| 144 × 214 mm | 150 dpi | fine for a poster |
| **210 × 297 mm (full A4)** | **≈ 102 dpi** | **soft up close, fine from 1 m away** |

100 dpi is normal for large-format printing — nobody reads a poster with their
nose against it. Full A4 is a reasonable choice for this one.

**One thing to expect:** the image is **1 : 1.49** and A4 is **1 : 1.41**, so it
is slightly taller than the page. "Fit to page" leaves about **10 mm of white
down each side**; "fill page" crops about **16 mm off the top and bottom**, which
would eat into the wordmark. The white margins are the safer choice.

## The other poster

There is a second, unrelated poster: a vector-quality A4 built here from HTML and
rendered at a true 2480 × 3508 px (300 dpi), with the same four levels but a
Spanish `¡TOCA LA FRUTA!` and real photographed lemons. Sergio went with the
Gemini one instead. It lives outside git at `~/Pictures/piano-limones/` on
quantumpc — say the word and it can be brought in here too.

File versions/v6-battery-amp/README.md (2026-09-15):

# V6 — battery power + amplified speaker

> **STATUS: DIAGRAM-ONLY PROPOSAL. Not a complete version directory, not built,
> not measured.** This folder holds the wiring contract's render and nothing
> else. It deliberately does **not** yet have `firmware/`, `emulation/` or
> `HARDWARE.md` — see [What is missing](#what-is-missing).
> The newest *real* board is still [V5.5](../v5.5-power-filter/).

<div align="center">
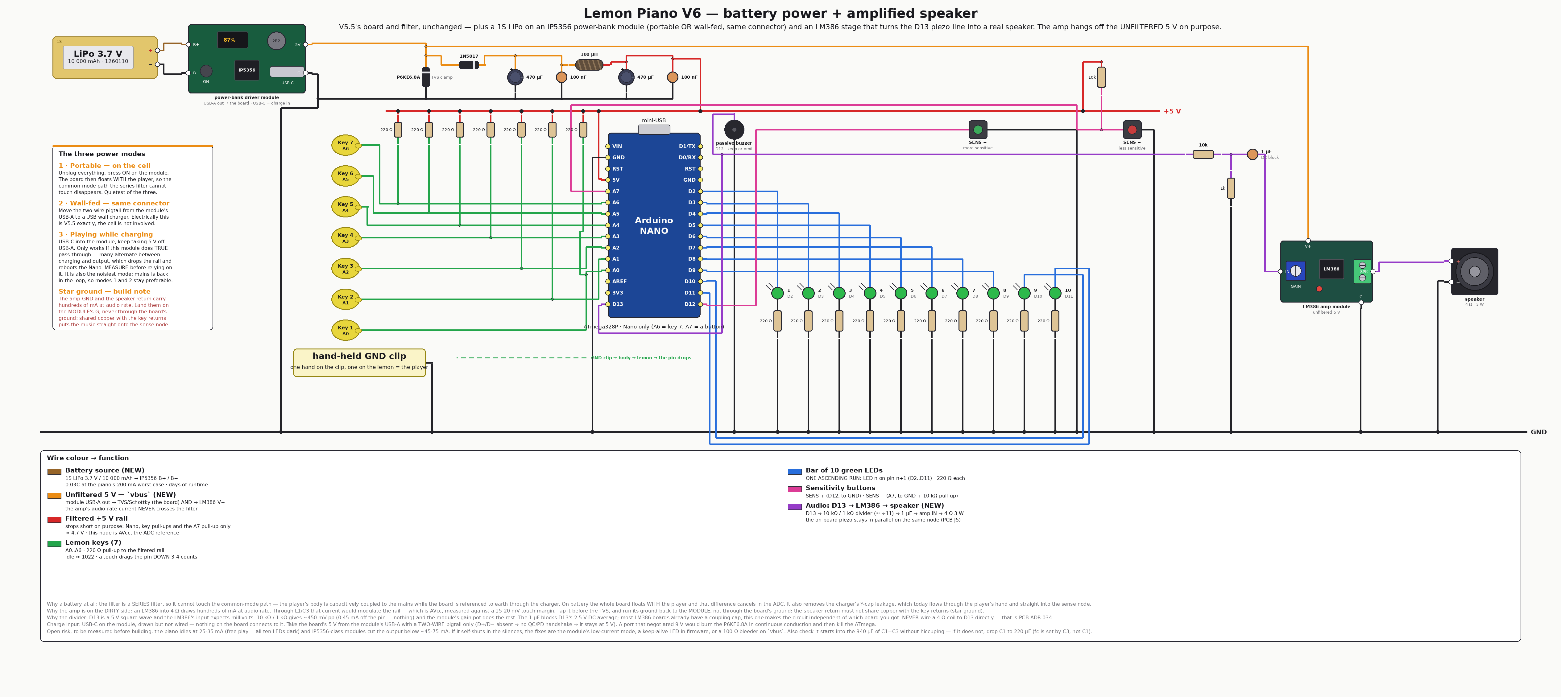
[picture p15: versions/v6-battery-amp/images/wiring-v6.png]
V6 wiring — LiPo + IP5356 power-bank module, V5.5's filter, and an LM386 speaker stage

</div>

## The hardware delta vs V5.5

Two additions; the V5.5 board, filter and pinout are untouched.

| Added | Part | Where it lands |
|---|---|---|
| Power source | 1S LiPo 3.7 V / 10 000 mAh (`1260110`) + IP5356 power-bank driver module | the module's USB-A output replaces the wall charger on the same 2-pin `5V IN` header (PCB J1) |
| Audio stage | LM386 mono amp module + 4 Ω 3 W speaker, behind a 10 kΩ / 1 kΩ divider and a 1 µF coupling cap | in parallel with the buzzer on `/BUZZER` (PCB J5) |

Nothing on the PCB changes: [ADR-025](../../pcb/docs/DECISIONS.md) already made
`5V IN` a 2-pin header sized for "a chopped USB-A pigtail", and
[ADR-034](../../pcb/docs/DECISIONS.md) already put `SPK` (J5) in parallel with
the buzzer. **Swapping which port the pigtail plugs into is the whole mode
switch** — power bank for portable, wall charger for mains.

## The two design decisions worth reading

**1. The amplifier hangs off the UNFILTERED 5 V (`vbus`), not the rail.**
An LM386 into 4 Ω pulls hundreds of mA at audio rate. The V5.5 CLC pi has
fc ≈ 730 Hz, so at 1 kHz it attenuates by only ~5 dB — audio-band current drawn
*through* the filter would land almost unattenuated on the filtered rail, which
**is** AVcc, the reference the 3-4-count (15-20 mV) touch margin is measured
against. So the amp taps the module's output *before* the TVS, sharing no series
element with the keyboard. This is why the `+5 V` rail in the diagram stops
short of the audio block instead of spanning the canvas: it is not there.

Corollary for the build: the amp's ground and the speaker return go back to the
**module's** G, never through the board's ground. Shared copper with the key
returns puts the music straight onto the sense node.

**2. D13 drives a divider, not the coil.** A bare 4-8 Ω speaker on D13 would
destroy the pin (ADR-034). 10 kΩ / 1 kΩ turns the 5 V square wave into ~450 mV
(0.45 mA off the pin), the 1 µF blocks its 2.5 V DC average, and the module's
gain pot does the rest. The on-board piezo stays wired in parallel on the same
node, exactly as J5 defines it — keep it or omit it.

## Why a battery is more than portability

The V5.5 filter is a **series** filter, so by construction it cannot touch the
common-mode path: the player's body is capacitively coupled to the mains while
the board is referenced to earth through the charger, and that difference falls
across the body → lemon → pin loop. On battery the whole board floats *with* the
player and the difference cancels in the ADC. It also removes the charger's
Y-cap leakage (0.1-0.35 mA at 50 Hz) which today flows through the player's hand
and into the sense node. **Expect battery mode to be quieter than mains, not
merely as quiet.**

## Open risks — measure before building

| Risk | Why | If it bites |
|---|---|---|
| **Low-load auto-shutdown** | the piano idles at 25-35 mA (free play = all ten LEDs dark); IP5356-class modules cut the output below ~45-75 mA | module's low-current mode · a keep-alive LED in firmware · 100 Ω bleeder on `vbus` — worked through, with the measurement protocol, in [docs/POWER-FROM-A-POWER-BANK.md](../../docs/POWER-FROM-A-POWER-BANK.md) |
| **QC/PD overvoltage** | a port that negotiated 9 V would put the P6KE6.8A into continuous conduction (it is a transient part, 600 W for 1 ms) — it burns, then the ATmega does | USB-A only, two-wire pigtail only (no D+/D− → no handshake) |
| **Inrush into 940 µF** | C1 + C3 look like a short to a boost whose short-circuit protection reacts in < 50 µs | drop C1 to 220 µF — `fc` is set by C3, not C1 |
| **No battery telemetry** | A0-A7 and D2-D13 are *all* used; there is no free pin | the module's own 2-digit display is the gauge |
| **Pouch vs THT leads** | the solder side is a field of cut leads; a LiPo pouch pressed against it is a puncture risk | rigid spacer or a separate compartment (the 4 × M2 holes are there) |

## Regenerating the diagram

The contract is `build_v6()` in
[`tools/wiring_diagrams.py`](../../tools/wiring_diagrams.py), routed and
DRC-validated by the [wirewright](https://github.com/yupipi93/eda-wirewright)
engine — never hand-drawn:

```bash
python3 tools/wiring_diagrams.py v6     # → 66 nets, DRC 0 violations
```

It uses four component factories added to the engine for this board:
`battery`, `power_bank_module`, `amp_module`, `speaker` (plus `deco.panel`).

## What is missing

To become a real version per [docs/VERSIONING.md](../../docs/VERSIONING.md) this
directory still needs:

- [ ] `firmware/` — a copy of V5.5's, plus whatever the low-load fix turns out
      to need (a keep-alive LED is a firmware change, and it costs one LED of
      the progress bar's semantics — that is a design call, not a mechanical one)
- [ ] `emulation/` — or a README saying why this board has no emulation
- [ ] `HARDWARE.md` — pin map + full BOM + the bench-validation recipe
- [ ] a row in [`versions/README.md`](../README.md) and the root README table
- [ ] **measurements**: the module's cut-off current, its inrush behaviour, and
      the 20-light-switch-flip noise comparison (mains vs battery vs charging)
      from [V5.5's bench recipe](../v5.5-power-filter/HARDWARE.md)

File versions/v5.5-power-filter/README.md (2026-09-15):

# V5.5 — filtered 5 V supply + amplified speaker (2026) — newest board

The V5 board plays exactly as before — this version exists because of how it was
**powered**. Fed raw USB from a PC or a wall wart, flipping a light switch
anywhere in the house made the piano play by itself, and on a socket shared with
many other devices it went haywire. That is not a software bug: the V5 keyboard's
touch margin is **3–4 ADC counts ≈ 15–20 mV** ([why](../v5-led-bar/HARDWARE.md)),
so any conducted transient bigger than that *is indistinguishable from a key
press*. V5.5 puts a **transient clamp + LC pi filter** between the 5 V source and
the board, so what reaches the rail — which is also the ADC's reference — is
clean.

**Hardware delta vs [V5](../v5-led-bar/):**

- **on** the board: a **power-entry filter** feeding the +5 V rail —
  **P6KE6.8A** TVS across the input, **1N5817** Schottky in series, then a
  **CLC pi filter**: 470 µF ‖ 100 nF → **100 µH** power choke → 470 µF ‖ 100 nF
  (fc ≈ 700 Hz, 2nd order);
- also on the board: an **amplified speaker** on the D13 sound line — a
  10 kΩ / 1 kΩ divider (≈ ÷11) → 1 µF DC block → **LM386** module → **4 Ω 3 W**
  speaker, with the on-board piezo left in parallel on D13. The amp is fed from
  the **unfiltered** 5 V (tapped before the TVS): its audio-rate current must not
  cross the filter, which is also AVcc, the ADC reference the 3–4-count touch
  margin rides on. That is why the `+5 V` rail in the diagram stops short of the
  amp block;
- the keyboard, LED bar and SENS ± buttons are byte-for-byte V5. **The firmware
  was too, until 2026-09-09**, when V5.5 gained FREE PLAY and the MODE WHEEL
  (below). V5 itself is unchanged and still builds — the two have simply
  diverged, which is what separate version directories are for;
- powering rule that comes with it: feed the filter from a **USB wall charger or
  bench supply**, not from a PC loaded with other devices, and don't power the
  board over its mini-USB in normal play (that connector bypasses the filter —
  it stays for flashing only; the Schottky keeps it from back-feeding the filter).

<div align="center">
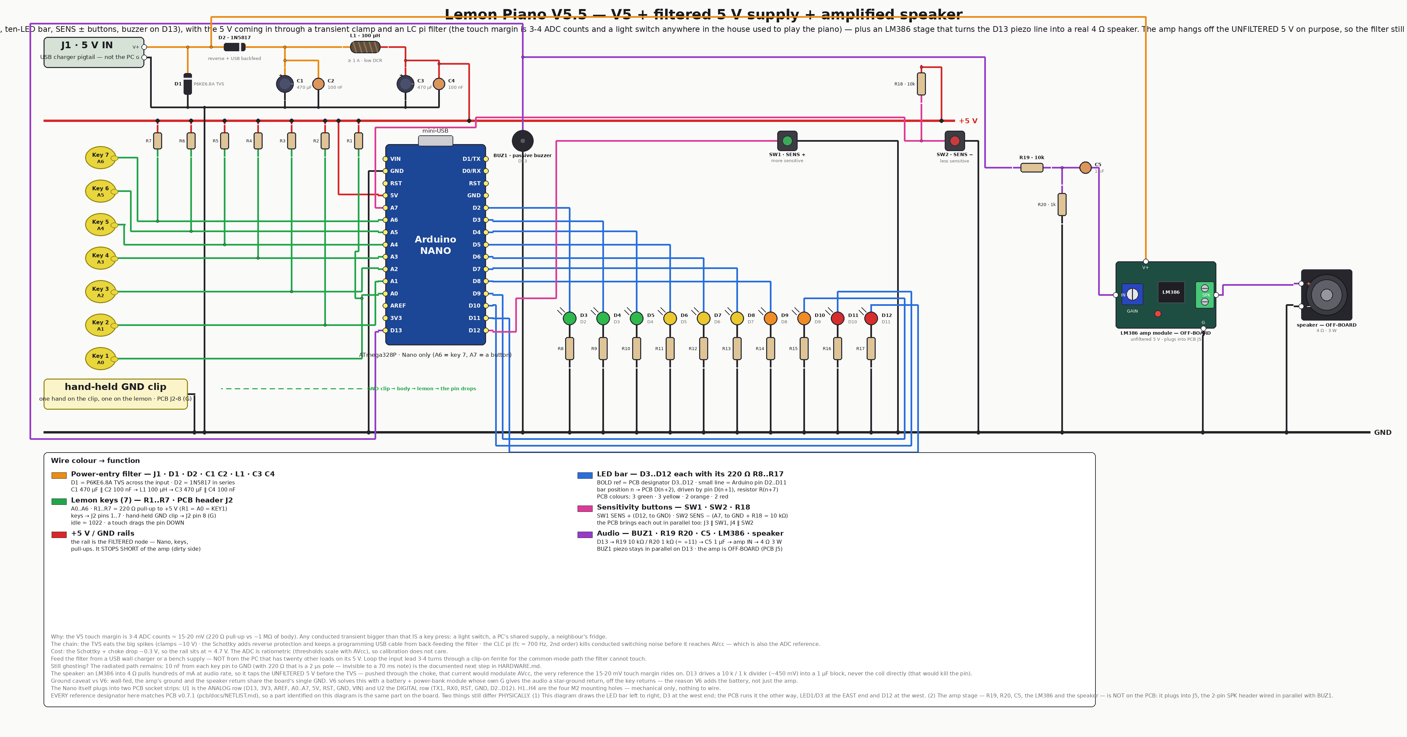
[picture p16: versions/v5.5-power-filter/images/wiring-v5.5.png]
V5.5 wiring diagram

</div>

## Why a light switch played the piano

Three coupling paths deliver a mains transient to the keyboard, in order of
strength when powered from a shared/noisy source:

1. **Conducted** — the spike rides the 5 V supply straight onto the rail. The
   rail tops the seven 220 Ω pull-ups *and* is AVcc, the ADC reference. The DC
   levels are ratiometric (a slow sag cancels out of the comparison), but a fast
   edge is not: the pin node and the reference don't move together, and a
   >20 mV difference for a few milliseconds is a phantom note. **This is the
   path V5.5 kills.**
2. **Common-mode** — house wiring ↔ supply ↔ board ground bounce. A series
   filter can't touch this one alone; the note on the diagram says it: loop the
   input lead **3–4 turns through a clip-on ferrite**.
3. **Radiated** — into the lemon wires and the player's body itself. Much
   weaker, but if ghosting persists, [HARDWARE.md](HARDWARE.md#still-ghosting)
   documents the next step (10 nF per key pin).

## How it plays

The game is [V5's](../v5-led-bar/README.md#how-it-plays), unchanged —
auto-calibration on boot with the bar as progress meter, noodling until the
first scored note, ten LEDs to a win, auto-advance through the four levels,
ending loop after level 4, SENS ± buttons and the smart-adjust gesture. The
filter is invisible to it; what changes is that calibration's measured noise
stays honest on a noisy mains, so the auto-margin stays tight instead of
widening to swallow the hum.

**Playing it, rather than reading about it: [the printed instruction sheet](../../docs/USER-GUIDE.md)**
([en español](../../docs/GUIA-DE-USO.es.md)).

### FREE PLAY, and the MODE WHEEL (2026-09-09, reshaped 2026-09-13)

Two additions, on the two buttons that were already there. No hardware changed.

> **What changed on 2026-09-13, after the first real session on the v0.7.1
> board.** Free play came off the wheel and onto its own button; neither button
> ramps the sensitivity any more; the LED bar counts sensitivity instead of
> margin; a lemon held down sounds once instead of machine-gunning; and the
> locked-key rattle is gone — a repeated lemon sounds its note and is marked by
> a backwards LED sweep instead. Each is Sergio's own report from playing it,
> and each has a named test.

### A repeated lemon, in the GAME (2026-09-13)

Pressing the same lemon twice in a row is **not a mistake**. It is just not a
move: the game is already waiting for a *different* lemon. Until 2026-09-13 the
piano said that by going silent and then playing `sfxKeyStuck`, a low rattle —
and a rattle reads as "you got it wrong". Sergio asked for both halves to go.

Now the repeat **sounds its note at full voice** (a piano before it is a game),
scores nothing, costs nothing, and is marked in **light**.

**That light changed on 2026-09-15.** From 09-13 until then it was one LED
running right to left — a flick of motion. Motion is now what free play's wave
uses, on the same ten LEDs, and two moving cues on one bar is one too many. So
Sergio asked for this one to stand still: *"se encienden todos los LEDs a la vez
y cuando la suelta se apagan"*. **The whole bar lights, for exactly as long as
the lemon is held, and goes back to the score when you let go.** Which is a
better shape anyway:

- ten lit LEDs is the one thing this bar does that is **not a count** — a score
  of ten is a win, and a win never leaves you still holding the lemon;
- it lasts **as long as the finger does**, so it reads as "this is about what
  you are doing right now", not as an event that happened;
- it **ends on the identical bar it started from**, which is the actual message.
  A wrong note, by contrast, blanks the bar and *leaves* it blank.

The animation is pinned by a test, not just its end state: the fake board records
a frame per change to the bar (`ledFrames`), so `piano_sim_test` asserts the
shape of the motion in between — a cue that starts and ends on the same picture
is invisible to anything that only reads the final pin states.

**FREE PLAY** is the piano with the game taken out. The seven lemons become
**do re mi fa sol la si** — C5 D5 E5 F5 G5 A5 B5, one octave of plain white
keys — and that is all they are: no secret code, no wrong note, no penalty, and
crucially **the same lemon may be played over and over**. That last point is the
whole feature. The game does not SCORE a repeated key, and that rule is exactly
backwards for an instrument, so free play does not have it at all — here a
repeat is simply another note, with no bar animation and nothing to ignore.

**Over and over means one note per touch, not one per flicker** (2026-09-13).
Resting a finger on a lemon is a single note that lasts as long as the finger
does. The contact underneath is not a switch — through the 1 MΩ pull-ups it
breaks for a few milliseconds at a time without the finger moving — so a release
is only believed after `RELEASE_CONFIRM_MS` (90 ms) of silence. Let go properly
and touch again and it sounds again; four deliberate taps are still four notes.

**Every note breaks a wave** (2026-09-15). Touching a lemon sends a wavefront
out from that lemon's own place on the bar: key 1 runs 1 → 7, key 7 runs 7 → 1,
and key 4 opens in **both directions at once** — *"como un efecto ola hacia
ambos lados"*. One shape, seven readings of it: the end keys only have one side
to travel down, which is why they read as a run across the whole bar, and no key
is special-cased. It is the motion that used to mark a repeated lemon in the
game, moved to where an instrument can use it.

**And the wave is the whole display.** For an hour it was followed by a pitch
meter — key 1 holding one LED lit, key 7 holding all ten — and the two read as
one confused thing: a wave that runs, then a block of light that stays.
*"Están solapados."* The static half is gone, so in free play the bar **only
ever moves**: dark, a wave, dark again. It also means the chord's two lone LEDs
are the one standing shape left in the mode, which is exactly the shape worth
keeping still (2026-09-15). It used to show its two ends lit, as a badge for the mode
— but that badge never went away: it sat inside every pitch reading, looking
like part of it. Now every LED that is lit was lit by a finger, and the mode
announces itself **once, as an animation**: on the way in, two lights walk in
from the ends of the bar, meet in the middle, open back out until all ten are
lit, and then empty to nothing — after which do-re-mi-fa-sol-la-si plays and the
bar is left dark for the player.

**TWO LEMONS AT ONCE SOUND AS TWO NOTES** (2026-09-15) — free play only. Hold a
second lemon with the first and both notes sound. There is one buzzer and
`tone()` makes exactly one square wave, so the two voices take turns every
`CHORD_SWAP_MS` (10 ms): fast enough that the ear stops hearing an alternation
and starts hearing an interval — the same arpeggio trick every mono sound chip
has used for chords since 1983. The **bar shows two lone LEDs**, one at each
note's place, which is a shape one finger cannot draw. Let either lemon go and
what is left is simply the note that is left.

The hard part is not the sound, it is **deciding that there really are two
fingers**: the channels are coupled, so one finger already drags its neighbours
part of the way down, and a single note that warbles like two would ruin every
note anyone plays. So the second lemon has to pass three gates — it must be a
touch at all, its dip must be at least 70 % of the one the first finger is
making, and it must be the *only* key that does both (three lemons' worth of
signal is a hand laid across the fruit, not a chord) — and then hold still for
24 ms.

**Gate 1 was stricter for half a day and that was wrong.** It asked the second
finger to dip *deeper* than a lone touch has to, and Sergio played it and
reported the chord barely came — *"puede ser que sea una limitación de
hardware"*. It is a fact about the return path rather than a limitation: every
lemon's current goes home through **one shared element**, the player's body and
the GND clip in their other hand. Two fingers are pulling that same node up
together, so each of them sits **shallower** than a single touch would. Asking
the second one to dip deeper was asking for the one thing two fingers cannot do.
The ratio gate is untouched by any of that — both dips shrink together, so their
ratio does not move — which is exactly why it is the gate that does the work.
The free-play log prints both dips every time a chord opens, so the real ratio
on real fruit can be read off a serial monitor rather than guessed at twice.
The game is deliberately untouched: it recognises a guess by comparing one
frequency against the secret sequence, so a chord there is not a richer guess,
it is an unanswerable question.

Free play is **not a level**. Winning never advances into it.

**The way in and out is to hold + for 3 s** (2026-09-13). It is a switch, not a
menu entry: the first hold swaps the game for the instrument, the next one puts
the game back — **restarting the level it interrupted**, which for anyone who
never touched the wheel is level 1. The arming meter and the rising chirp are
the same as −'s, so the two holds feel like one gesture with two destinations.

**The MODE WHEEL** is how you choose — the game-select switch that V5 removed,
brought back as a gesture:

| | |
|---|---|
| **Open** | hold **−** for 3 s (from free play it opens on the level free play interrupted). From 1 s the bar becomes a charge meter and a chirp climbs with it, so the gesture is never a mystery; let go early and a bump says "cancelled" |
| **Turn** | tap **+** / **−**. Four items — level 1, 2, 3, 4 — and it **wraps** both ways. Free play is **not** on it: it is a hold on **+** |
| **Preview** | each stop plays the opening of its own theme and shows itself on the bar: **level n = n LEDs, blinking**. Blinking is a question, steady is a score |
| **Accept** | **both buttons at once**, in any order, any overlap |
| **Leave** | hold either button 3 s, or wait 20 s. Nothing changes — the game keeps its level and its progress bar |

A preview is cut off the instant the wheel turns again, so browsing runs at the
speed of the hand, not of the tunes.

### "Play me that tune again" — ONE lemon, five times (2026-09-15)

The theme **is** the clue: the ten-note code is hidden in the tune the level
opens with, so a player who half-remembers it had to reset the board or win the
level to hear it again.

**This gesture moved once, and why is the interesting part.** It shipped as
*hold the two END lemons together for two seconds* — a good gesture built on the
one thing this keyboard cannot do. Sergio, after playing it: *"creo que es
físicamente imposible detectar correctamente la pulsación de varias teclas a la
vez. Por lo cual vamos a cambiar el paradigma."* He is right, and the reason is
the same shared return path that makes the chord hard: two fingers are in each
other's way, so each dips shallower than one.

So it is built out of the one input this piano has read perfectly since 2019:
**one lemon, pressed and released.** Press the same lemon **five times in a row**
and the level plays its theme again. **The note you just played is press one** —
so in practice it is four more taps on the lemon under your finger.

- **Nothing simultaneous, nothing to disambiguate.** No thresholds beyond the
  ones that already work.
- **It changes nothing about the game.** Presses two to five are repeats, which
  already score nothing and cost nothing; the first is an ordinary press,
  because the player chose to touch a lemon. Afterwards the progress bar comes
  back exactly as it was — *"el juego continúa por donde estaba"*.
- **There is an obvious free move**: drum the lemon the game has *just
  accepted*. Then every one of the five is a repeat and the hint costs nothing
  at all.
- **The keys are dead while it plays**, because `playLevelIntro()` is blocking,
  and the lemon still under the finger has to be let go before it counts as
  anything again.
- **A pause resets it.** More than `THEME_REPEAT_GAP_MS` (1.5 s) between two
  presses and the count starts over, so drumming is a decision rather than an
  accident, and a lemon poked twice a minute apart never adds up to a request.

**Game only, and that is not an omission.** Free play exists precisely so the
same lemon can be played over and over — it is the mode's whole point and the
one rule the game has that an instrument must not — so counting repeats there
would take the mode away to give it a hint it has no use for.

**And the widest chord is back.** With the gesture off the two end lemons,
lemon 1 + lemon 7 is once again available as a chord in free play.

### The overlaps, and why they do not collide

Four gestures now share two buttons, which is where this sort of thing normally
goes wrong. The four collisions and their resolutions are documented at the top
of [`firmware/include/ui_gestures.h`](firmware/include/ui_gestures.h) and each
one is a named test case. The whole map, at the keyboard:

| gesture | while playing | in the wheel |
|---|---|---|
| **tap +** | one step **more** sensitive — one LED **on** | next level, wraps |
| **tap −** | one step **less** sensitive — one LED **off** | previous level, wraps |
| **hold + 3 s** | **free play ⇄ the level** | (3 s leaves the wheel) |
| **hold − 3 s** | **the level wheel** | (3 s leaves the wheel) |
| **both, 1 s** | smart adjust: learn the margin from a real touch | accept, at any overlap |

…and one gesture that is not on the buttons at all: **the same lemon five times
in a row replays the level's theme** (game only). It shares nothing with the
list above — different limb of the instrument entirely — which is exactly why it
was moved onto the keyboard after the two-lemon version proved undetectable.

The two worth knowing:

- **A tap is a step. A hold is a mode.** Holding a button no longer ramps the
  knob — it used to fire a step every 120 ms, which meant every mode change also
  re-tuned the keyboard by thirty counts. The nudge still fires on press, because
  a knob that waits for the release feels broken, so the gesture that fires
  **puts that one step back**: reaching for a mode must not leave the keyboard
  somewhere else.
- **Both buttons for 1 s is smart adjust; one button alone for 3 s is a mode.**
  They live in different states and cannot be reached from each other by
  accident: press the other button while one is charging and the charge cancels
  and hands over to smart adjust, out loud.

**The bar counts sensitivity, not margin.** More LEDs lit = more sensitive = a
smaller margin, so **+ adds light and − takes it away**. It was the other way
round until 2026-09-13, and it read as a lie: a button labelled "more" that puts
lights out is a button that says "less" from across the room.

## Build, test & flash

```bash
cd firmware
pio run -e nanoatmega328        # old-bootloader Nano clones
pio run -e nanoatmega328new     # 2018+ bootloader
pio run -e nanoatmega328-debug  # + raw ADC logging per accepted press
pio run -e emulation            # Velxio build
pio run -e emulation-freeplay   # Velxio build that boots into free play
test/run.sh                     # the host tests — run these before committing
```

`test/run.sh` is the deterministic check for everything above, and it needs
neither hardware nor the emulator: plain `g++`, two binaries, exit 0.
`ui_gestures_test` drives the button state machine through every overlapping
timeline; `piano_sim_test` compiles **the real `src/main.cpp`** against a fake
board (`test/arduino/Arduino.h`) and plays the piano — note mapping, free-play
repeats, the wheel, winning, cancelling. It is the only regression test that
reaches the wheel at all: the browser emulation has no pins left for the two
buttons.

Flash over the mini-USB as always. While *playing*, though, don't leave the PC
attached: its ground noise re-enters through the USB common ground and sidesteps
the whole filter.

## Verification status

| Check | Status |
|---|---|
| Diagram renders, 0 DRC violations | ✅ `python3 tools/wiring_diagrams.py v5.5` — 64 nets, 0 hard violations (2026-09-06) |
| Firmware builds (all five envs) | ✅ `pio run` per env, 2026-09-15 — 562 B RAM (27.4 %), 17 806 B flash (58.0 %) |
| Host tests: gestures + whole firmware | ✅ `firmware/test/run.sh`, 2026-09-15 — **107 + 162 checks, 0 failed**. Mutation-checked: breaking the free-play scale, dropping the margin restore, or moving the arming line each turns it red |
| Flashed to the board | ✅ 2026-09-15, `/dev/ttyUSB0` env `nanoatmega328` — 17 806 bytes written **and verified** by avrdude; boots, calibrates seven baselines, announces `Level 1` |
| Every level's lemons are in its own key | ✅ `test_every_level_plays_in_its_own_key` — every one of the 28 key notes must be a note that level's own theme plays, and the four codes must still resolve to the numbers the booklet prints |
| Emulation, the game | ✅ V5's circuit and specs, verified there ([emulation/README.md](emulation/README.md)); the filter itself is analog supply hardware and **not emulatable** |
| Emulation, free play (`emulation/piano-mode.yaml`) | ⬜ **written, not yet run** — the Velxio harness is not installed on the machine this was written on. Compile-checked (`pio run -e emulation-freeplay`) and the spec parses, but no `--mode verify` has passed on it |
| The mode wheel in the browser | ⛔ **impossible on purpose** — ten LEDs + buzzer + key 7 use every digital line, so the two buttons have no pins. Covered by the host tests instead |
| Free play / the wheel on real hardware | 🔄 **in progress** — played on 2026-09-15 and four rounds of his reports acted on (the idle badge, the repeat cue, the wave, the level tunings, and the theme-reminder gesture moving off two simultaneous lemons). Still open: whether the chord comes reliably now that gate 1 is fixed, and whether 14 ms/frame makes the wave feel syrupy |
| Filter measured on the real board | ⬜ pending — build it and re-run the [V5 bench sampler](../v5-led-bar/HARDWARE.md#why-the-keyboard-is-pulled-up-again-measured-2026-07-27--28) during a switch-flipping session |

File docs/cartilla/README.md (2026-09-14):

# The organiser's booklet

One A4 sheet, black and white, printed on both sides and **folded down the
middle into an A5**. It exists so that someone who has never seen the lemon
piano can switch it on, explain it, and rescue it — without Sergio in the room.

```
./build.sh            # -> cartilla.pdf
./build.sh --print    # ...and send it to the laser
```

## The four panels

| | |
|---|---|
| **Front** (right half of side 1) | the title, the seven lemons, *Guía del organizador* |
| **Back** (left half of side 1) | what the two buttons do · **si algo va mal** |
| **Inside left** | how the game works · the two questions everyone asks about the finger · what the sounds mean |
| **Inside right** | **the four codes**, and how to tell which lemon is number 1 |

Almost no prose. Everything that can be a picture is one, and the picture is the
**LED bar itself** — ten boxes, filled or empty — because that is the only thing
the piano can say and the only thing a helper has to read.

## The codes are derived, never typed

`seqs.py` is the point of this directory. A level's code lives in the firmware as
note **frequencies**, and which lemon plays a given note is different on every
level — each one has its own seven-note keyboard row. So the answer a player
needs ("touch 6, then 5, then 6…") exists nowhere in the source: it has to be
resolved, one table against the other.

Typing the result into the template by hand would be a second source of truth
that nothing checks, and it would go stale the first time a melody changed.
Instead `seqs.py` reads both tables out of `main.cpp`, resolves them, and
**cross-checks level 1 against the sequence hard-coded in the host test**, which
was written independently. It exits non-zero rather than guess: a level whose
code asks for a note that is not on its own keyboard is unplayable, and that is
a failure, not a warning.

**So: change a melody in `main.cpp`, re-run `./build.sh`, and the booklet is
right again.** The committed `cartilla.pdf` is a convenience for reprinting —
if the firmware's melodies have moved since, rebuild before printing.

## Printing it

The content is **A4 landscape**, so the side that reads like a book is the one
flipped about the paper's **short** edge:

```bash
lp -d laser -n 1 -o media=A4 -o ColorModel=Gray -o sides=two-sided-short-edge cartilla.pdf
```

Long-edge duplex puts the inside spread upside down relative to the cover. If a
copy comes out that way, that is the setting to change, not the file.

## Two notes on the type

- **Press Start 2P has no accented capitals** — it draws `Í` as `í`. So the
  pixel face is used only where Spanish needs no accent (the cover title,
  `NIVEL n`, the code digits) and everything else is DejaVu in caps. The first
  draft ignored this and printed `CóMO SE JUEGA`.
- Everything is **pure black on white**, no greys except the fold line. A laser
  printer renders a 50 % grey as a dot screen, which at 8 pt turns body text to
  mush.

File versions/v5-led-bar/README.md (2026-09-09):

# V5 — ten-LED progress bar (2026)

> **The newest board is [V5.5](../v5.5-power-filter/)**, which is this board plus
> a filtered 5 V supply. Its firmware started as a byte-for-byte copy of this one
> and **diverged on 2026-09-09**, when it gained FREE PLAY and the MODE WHEEL.
> This version is unchanged and still builds: it is the four-level game exactly
> as it stood on 2026-07-29. Want the piano mode? Flash V5.5 — the game hardware
> is identical, so it runs on this board too.

No relays, no pump, no red LED, no fail counter: a row of **ten green LEDs** is
the entire feedback surface. Each correct note lights the next LED, a wrong note
blanks all ten, and lighting the tenth wins — the theme plays with the bar
flashing to the beat, then the game **auto-advances** to the other tune.

> **Rebuilt on 2026-07-28.** This board replaces the original V5 board *in place*,
> at the owner's request, rather than becoming a new version. The previous V5
> (floating +5 V-clip keyboard, A7 game-select switch, D7 restart button) is
> recoverable from git history and described in [../../CHANGELOG.md](../../CHANGELOG.md).

**Hardware delta vs [V4.5](../v4.5-margin-buttons/):**

- **the keyboard returns to the 2019 arrangement**: each key is pulled **up** to
  +5 V through 220 Ω and the player holds a **GND** clip, so a touch drags the
  reading **down**. This is what made the keyboard readable at all — the
  measurements are in [HARDWARE.md](HARDWARE.md);
- **off** the board: the red LED, the two MARGIN buttons, the **game-select
  switch** and the **restart button** (relays and pump left with V4.5);
- **on** the board: **ten green LEDs in one ascending run, D2 → D11** (LED n on
  pin n+1, so the bar wires left to right with nothing to look up) and **two
  sensitivity buttons** — **SENS + on D12**, **SENS − on A7**. The buzzer moves to
  **D13**;
- board: **Arduino Nano only** — A6 is key 7 and A7 is a button, and a classic Uno
  exposes neither.

<div align="center">
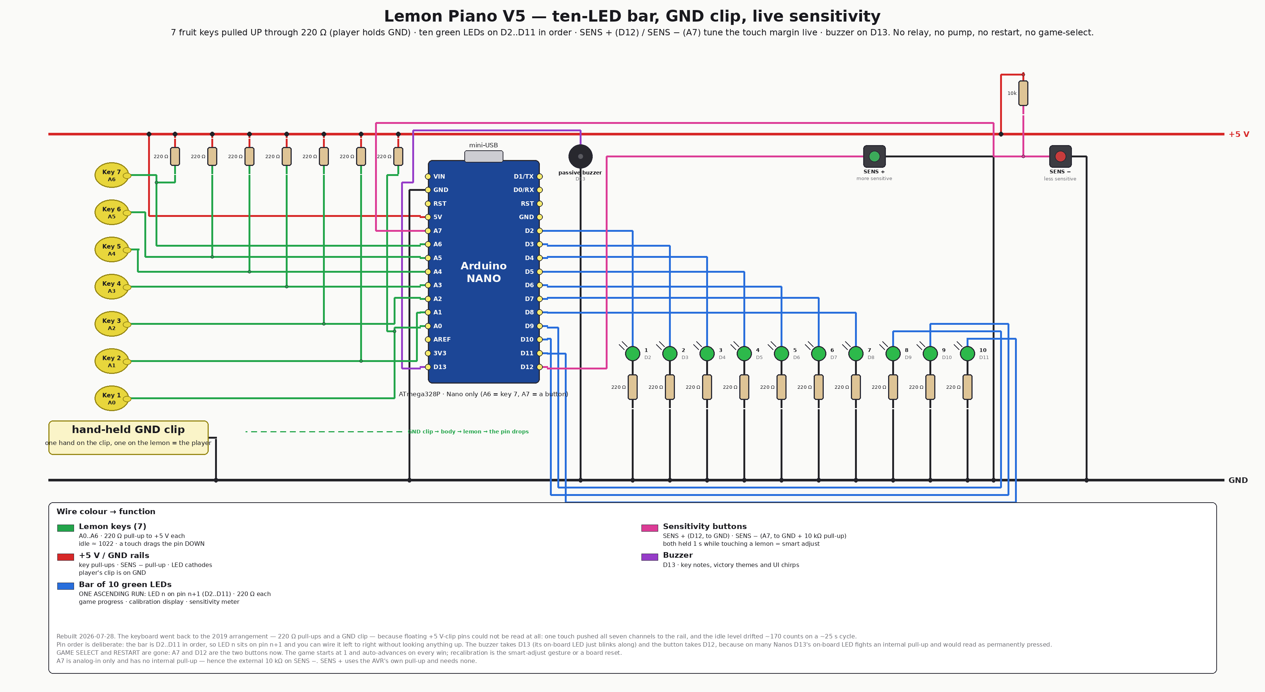
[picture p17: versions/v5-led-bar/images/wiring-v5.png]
V5 wiring diagram

</div>

## How it plays

1. **Power on → auto-calibration.** It measures every key's resting level *and*
   its idle noise, **counting up all ten LEDs progressively** as it goes
   (**LEDs filling = hands off the fruit**) — one coin per key measured, seven
   keys spread proportionally across all ten so the bar always finishes full
   regardless of there being only seven keys — then derives the touch margin
   from the measured noise, chirps when done, and shows the chosen sensitivity
   on the bar. The game starts at **game 1** and auto-advances on each win, so
   all four themes are reachable with no switch. Then it **announces the
   level**: the opening notes of that level's own theme play once, so you know
   which of the four you landed on before touching a lemon.
2. **Touch lemons.** Hold the **GND** clip in one hand and touch a lemon with the
   other — your body drags that pin down and the note plays on the buzzer.
3. **Play freely.** While the bar is empty, every key just sounds its note —
   no wrong tone, no penalty. It is a piano; noodle as long as you like.
   **Hold a lemon and its note keeps sounding** for as long as you touch it (a
   quick tap still gets a full 70 ms note), and **pressing the same lemon again
   never counts twice** — only the first press of a key reaches the game, until
   you play a different one. Flaky fruit contact can no longer machine-gun
   guesses. It stays silent for the first 500 ms after you let go (a quick
   accidental double-tap gets no cue), but press the SAME locked key again
   after that and it plays a low **"stuck key" rattle** — a clear "try another
   one" instead of nothing at all.
4. **The puzzle starts when you hit the code's first note** (LED 1 lights). From
   there each correct note lights the next green LED (the bar climbs 1 → 10),
   and a wrong note **blanks all ten** and drops you back to free play. The low
   "wrong" tone plays **after** the note you pressed has finished — you always
   hear which key was wrong, then the buzz.
5. **Victory + auto-advance.** Light all ten → that level's own theme plays in
   full first, **the bar counting back up from empty to all ten** across the
   whole theme (a progressive fill, not a flash — the same "count up" feel as
   calibration), then the **flagpole fanfare**, then the **next level's own
   intro announces it**, before the game moves to the **next level**
   (1 → 2 → 3 → 4 → 1 …). Clearing level 4 plays the **game-complete piece on
   a loop**, after the flagpole fanfare — it keeps celebrating until you hold
   both sensitivity buttons for 1 s, which resets straight back to level 1
   **without recalibrating** (also announced).
6. **Tune sensitivity while you play**: **D12** = more sensitive, **A7** = less
   sensitive, 1-count steps (5 above margin 20), auto-repeat while held. The bar
   shows the level for a moment after each press, and the tick's pitch tracks the
   setting — so you can see *and* hear where it is.
7. **Smart adjust**: hold **both buttons for 1 s while touching a lemon**. It
   works out which lemon your finger is on, measures how far the other channels
   wander meanwhile, and sets the margin midway between the two — the cleanest
   separation your fruit can currently give. The bar fills as it samples; a rising
   triad means it learned, a falling pair means the touch could not be told from
   noise and **nothing changed**.
8. **No restart button.** Recalibrate with the smart-adjust gesture or a reset.
   The SAME both-buttons-1s gesture means something different while the
   game-complete piece is looping: it stops the music and resets to level 1
   without recalibrating (see step 5) rather than learning a new margin.

Every state has its own sound, all of them **above** the game notes (3.3–4.7 kHz,
where a piezo is loudest) so a chirp is never mistaken for a note: calibration
start/finish, button ticks, end-stop, smart-adjust progress/success/failure, and a
warble if a key gets stuck reading touched and is re-baselined.

### Four levels, four themes (spoilers)

Each level has its own seven key notes, its own 10-note code, and its own theme —
played in full (opening announce + win jingle draw from the SAME table) rather
than a short excerpt. Clear level 4 and the **game-complete fanfare** plays
before it wraps back to level 1.

| Level | Theme | Code |
|---|---|---|
| 1 | Overworld / Main Theme | `6, 5, 6, 7, 2, 5, 2, 1, 3, 4` |
| 2 | Underworld | `3, 6, 1, 4, 2, 5, 3, 6, 1, 4` |
| 3 | Starman *(moved here from level 4)* | `2, 4, 6, 1, 5, 3, 7, 4, 2, 6` |
| 4 | Castle *(was Underwater, then moved here from level 3 — makes more sense as the finale)* | `5, 1, 3, 7, 2, 6, 4, 1, 5, 3` |

| Key | 1 | 2 | 3 | 4 | 5 | 6 | 7 |
|---|---|---|---|---|---|---|---|
| Level 1 | E6 | G6 | A6 | B6 | C7 | E7 | G7 |
| Level 2 | A3 | A#3 | C4 | A4 | A#4 | C5 | D5 |
| Level 3 | C5 | C#5 | D5 | E5 | F5 | G5 | A5 |
| Level 4 | C5 | D5 | E5 | F5 | G5 | A5 | C6 |

A level's seven notes are always distinct (the game recognises a guess by
frequency), and no code repeats a note back-to-back (a repeated press of the same
key is filtered as flaky contact). Each level's key notes and code have stayed
put through both theme changes — only which theme plays for which level moved.

### The sounds are Mario's

Every non-key sound is a Super Mario Bros effect — see
[../../docs/MARIO-SOUNDS.md](../../docs/MARIO-SOUNDS.md) for the note data and
where each one came from:

| Moment | Sound |
|---|---|
| Calibration starts | fireball whoosh |
| Each key measured | **a coin** (seven coins = seven keys) |
| Calibration finished | **mushroom power-up** |
| Sensitivity button | coin grace-note tick, pitch tracks the margin |
| Knob at its end stop | bump (head on a block) |
| Smart adjust listening | a coin per sampling burst |
| Smart adjust learned | **1-up** |
| Smart adjust failed | **death rattle** |
| Wrong note | **short death rattle** (2 notes) |
| Locked key, pressed again after 500 ms | **"stuck key" rattle** (low, distinct from Bump) |
| A level (re)starts | opening notes of **that level's own theme** |
| Level complete | that level's theme (full), then the **flagpole fanfare** |
| All four levels clear | fanfare, then the **game-complete piece, looping** until reset |

Touch sensing is the V2.5 front end: `threshold = baseline − margin`, with the
baseline measured at boot and tracked while each key is untouched, and the margin
auto-derived as `max(4, 2 × worst measured noise)`. On this rig that lands on
**margin 4 → threshold 1018**, which is the working point measured by hand.

## Firmware

```bash
cd firmware
pio run                          # nanoatmega328 (default, old bootloader)
pio run -e nanoatmega328new      # Nano with the new bootloader
pio run -e emulation             # compile-check the VELXIO_EMULATION shim
pio run -t upload
pio device monitor               # 9600 baud — logs Game/OK n/10/WIN
```

There is no `uno` env: V5 needs A6 (key 7) + A7 (SENS −).

### Pin map at a glance

```
A0..A6   keys 1..7      220 Ω pull-up each; player holds the GND clip
D2..D11  LEDs 1..10     LED n on pin n+1 — one run, in order
D12      SENS +         button to GND (internal pull-up)
D13      buzzer         on-board LED blinks along with the audio
A7       SENS −         button to GND + external 10 kΩ pull-up
```

## Emulation — ✅ verify green

```bash
PIPE=../../../velxio-multi-board-emulator/harness/.venv/bin/velxio-pipeline
$PIPE stack up                    # then import emulation/lemon-piano.vlx at http://localhost:3080/editor
$PIPE run --mode verify --spec emulation/lemon-piano.yaml --out emulation/runs
```

Clickable lemons (or press `1`–`7` on your keyboard), audible buzzer, the ten-LED
bar — **coloured like a VU meter in the browser** (LEDs 1-3 green, 4-6 yellow,
7-8 orange, 9-10 red, 2026-07-29) so the progressive fill reads at a glance;
the real board's ten LEDs are all green (see the BOM), this is an emulation-only
touch. Because ten LEDs use every free browser pin there is **no game-select
switch and no restart button**: it starts at game 1 and auto-advances on each win.
There are **four** headless specs, all green (2026-07-27, +1 on 2026-07-29,
re-timed three times the same day — for the level-intro feature below, for
Underwater→Castle at level 3, then again when Castle moved to level 4 and was
redesigned for recognisability):

| Spec | What it proves |
|---|---|
| `emulation/lemon-piano.yaml` | free play → first note → a miss (`WRONG`) → the full code (with the first note pressed twice, to show the repeat filter doesn't eat real guesses) → `WIN` → auto-advance to `Level 2`, plus the victory light show |
| `emulation/free-play.yaml` | five keys that are *not* the code's first note: the buzzer sings, but `WRONG` and `OK` never appear and LED 1 never lights |
| `emulation/hold-and-repeat.yaml` | one key held 600 ms then tapped three more times: the note sustains with the touch, and four touches produce exactly one `OK 1/10` — no `OK 2/10`, no `WRONG` |
| `emulation/all-levels-win.yaml` | a scripted "virtual button" that plays all **four** levels' secret codes back to back — the only test that exercises levels 3 and 4. Asserts `WIN` -> `Level 2` -> `WIN` -> `Level 3` -> `WIN` -> `Level 4` -> `WIN` -> `ALL LEVELS CLEAR` -> wraps to `Level 1`, zero `WRONG`s |

Every input in every spec above is timed around a blocking call: since
2026-07-29 each level opens with its own **intro announce** (`playLevelIntro()`
— the level's own theme, first few notes, played once) in addition to the
existing victory theme + fanfare, so a key pressed too early is simply never
polled, not queued. See the comments above each spec's `inputs:` for the
measured timings this depends on.

There's also a **live, on-demand** version for manual testing —
`emulation/autoplayer.yaml`: a second Arduino (Uno) sharing the canvas. Type a
level number (1-4) into *that board's own Serial Monitor tab* to arm it (its
4 LEDs show which), then `p`, and it fires that level's code onto the lemons'
own key nodes — as many times as you like, matching whichever level piano is
actually on. Your own lemon clicks still work at the same time, in the same
session — verified live (autoplay a win, then click a lemon by hand right
after: both register correctly, 9/9 repeated runs). (An earlier pass tried
physical PLAY/LEVEL SELECT buttons instead of serial commands; verified live
with a headless-Playwright probe that this Velxio version binds every
pushbutton's click handler to a single global simulator rather than one per
board, so a button on the second board can't reliably drive its own pins —
serial I/O doesn't have that limitation, hence typing instead of clicking.
A later pass fixed manual clicks going dead once the finger wiring correctly
reached piano's pins — a bare wire was a hard short that always beat a real
click, fixed with a 220Ω series resistor on each finger wire. Details in
`emulation/README.md`.) Multi-board specs only run in `--mode interactive` in
this harness (no headless verify/document for them), so open it in the
browser:

```bash
$PIPE run --mode interactive --spec emulation/autoplayer.yaml --out emulation/runs --open
```

Details, pin map and the two boards' full sketches:
[emulation/README.md](emulation/README.md#files).

```bash
$PIPE run --mode verify --spec emulation/free-play.yaml --out emulation/runs
$PIPE run --mode verify --spec emulation/hold-and-repeat.yaml --out emulation/runs
$PIPE run --mode verify --spec emulation/all-levels-win.yaml --out emulation/runs
```

> **A code can never repeat a note back-to-back** now that same-key repeats are
> filtered. Neither of the two codes does (`6,5,6,7,2,5,2,1,3,4` and
> `3,6,1,4,2,5,3,6,1,4`) — check it if you ever add a third.

Full details, key mapping and the pin-map diff:
[emulation/README.md](emulation/README.md).

## Files

| Path | What |
|---|---|
| [firmware/src/main.cpp](firmware/src/main.cpp) | the V5 game (10-LED bar, auto-advance) + Velxio shim |
| [firmware/include/notes.h](firmware/include/notes.h) | note frequency table |
| [emulation/lemon-piano.yaml](emulation/lemon-piano.yaml) | circuit spec (source of truth) |
| [emulation/lemon-piano.vlx](emulation/lemon-piano.vlx) | generated project — import into Velxio and Run |
| [HARDWARE.md](HARDWARE.md) | pin map, BOM, wiring detail |
| [images/wiring-v5.png](images/wiring-v5.png) | wirewright-rendered wiring |

**Next revision:** none yet — this is the newest board. Modify the hardware and
you start V6: the recipe is in
[../../docs/VERSIONING.md](../../docs/VERSIONING.md).

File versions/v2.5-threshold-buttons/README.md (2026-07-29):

# V2.5 — keyboard test with a live touch threshold (2026)

[V2](../v2-keyboard-test/) is the 2019 keyboard test rig, and its touch detection
hangs on one hardcoded number: the famous `<= 1019`. Finding a working value meant
edit → compile → reflash, over and over, for a number that depends on the fruit,
the power supply, the mains outlet and where your feet are.

V2.5 makes that number **a variable you can dial while you play**, and turns on the
serial monitor V2 never had.

**Hardware delta vs [V2](../v2-keyboard-test/):** two buttons, nothing else —
**THRESHOLD + on D10** and **THRESHOLD − on D11**. Both wired **straight to GND**
using the AVR's internal pull-ups, so they need **no external resistors** (a
deliberate difference from V3/V4/V4.5, whose active-HIGH buttons each need a
10 kΩ pulldown — this is a bench instrument, so fewer parts wins).

<div align="center">
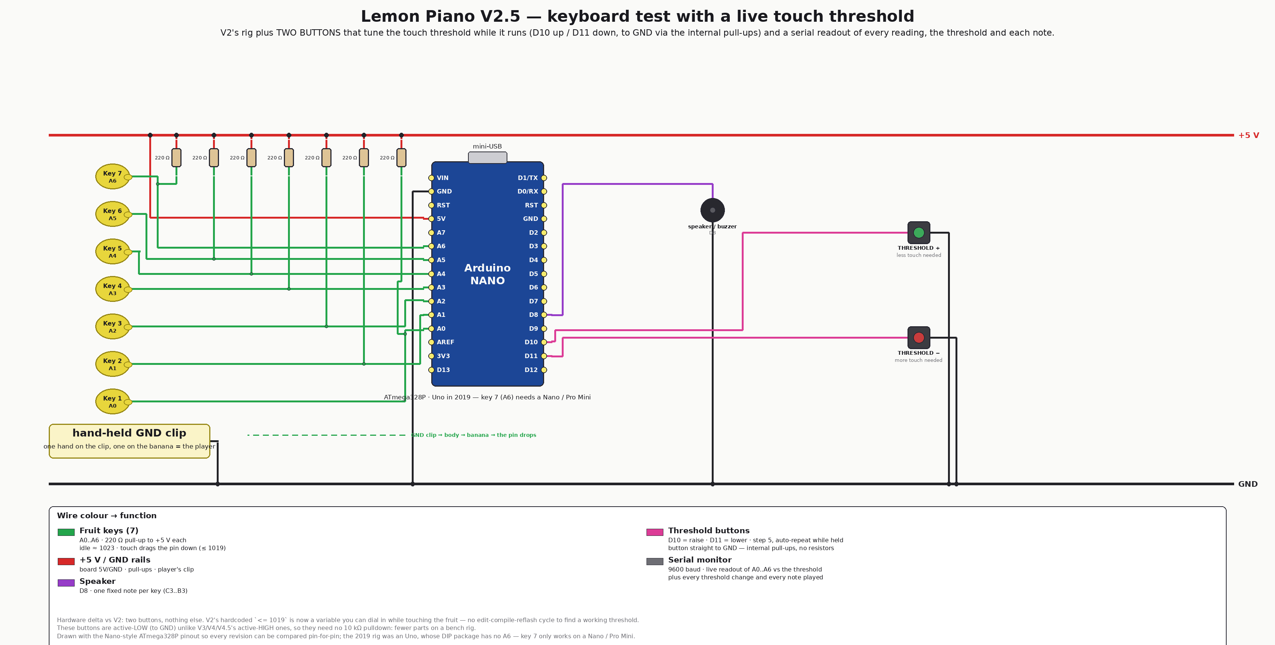
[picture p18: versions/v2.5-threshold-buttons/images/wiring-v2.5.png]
V2.5 wiring diagram

</div>

## What it does

- **The threshold is live.** Each press steps it by 5, and holding a button
  **auto-repeats** (400 ms to start, then every 120 ms) so you can sweep the whole
  0–1023 range without 200 presses. Limits are clamped and reported.
- **The serial monitor is the instrument** (9600 baud). Twice a second it prints
  every channel's 4-sample average next to the threshold, with a `*` marking each
  channel currently counted as touched:

```
Lemon Piano V2.5 - keyboard test, live threshold
buzzer pin: D8
threshold + : D10   threshold - : D11
touch detected when the average is BELOW the threshold (2019 wiring)
threshold=1019
---- A0   A1   A2   A3   A4   A5   A6  | thr  (live readout)
      1023  1023  1023  1023  1023  1023  1023 | 1019
KEY 1 C3  reading=0  threshold=1019
>>> threshold=1014  (-5)
```

- **One note per fresh touch.** V2 re-fired every loop while a key was held, which
  machine-guns the buzzer and makes the readout unreadable; here each touch is
  edge-triggered. Notes are V2's: C3 D3 E3 F3 G3 A3 B3, 150 ms.

### How to use it to find a threshold

Watch the live readout while you touch one lemon, and dial the buttons until only
that channel is starred. If no value marks exactly one channel, the problem is the
front-end, not the number — see
[../v5-led-bar/HARDWARE.md](../v5-led-bar/HARDWARE.md#️-the-pull-downs-are-not-optional-measured-2026-07-27)
for the measurements that show why, and fit the pull-downs.

> ⚠️ **Polarity.** This keeps V2's 2019 sensing: pins pulled **up** to 5 V through
> 220 Ω, player holding a **GND** clip, so a touch drags the reading **down** and
> "touched" means `average <= threshold`. If your board is wired the 2026 way
> (clip on +5 V, 220 Ω in series, pins floating low and **rising** on touch), that
> comparison is backwards and *no* threshold works — flip `TOUCH_WHEN_BELOW` to
> `false` at the top of [firmware/src/main.cpp](firmware/src/main.cpp) and the same
> buttons tune the 2026 wiring instead.

## Firmware

```bash
cd firmware
pio run -t upload                        # Nano, old bootloader (57600) — default
pio run -e nanoatmega328new -t upload    # if that times out
pio run -e uno -t upload                 # Uno works, but has no A6 (key 7 dead)
pio device monitor                       # 9600 baud — this build is all about it
```

5 188 B flash, 306 B RAM. All four envs build green.

## Emulation — ✅ verify green

```bash
PIPE=../../../velxio-multi-board-emulator/harness/.venv/bin/velxio-pipeline
$PIPE stack up      # then import emulation/keyboard-test.vlx at http://localhost:3080/editor
$PIPE run --mode verify --spec emulation/keyboard-test.yaml --out emulation/runs
```

Seven clickable keys plus **both threshold buttons**, so the whole point of the
version is playable in the browser. `verify` plays keys 1, 2 and 7, taps the
threshold down twice and up once, then plays key 3 — asserting the notes, the
buzzer edges and `>>> threshold=1014` / `1009` / back to `1014`. Last run:
**pass** (2026-07-27).

Two things move in the browser build (`-DVELXIO_EMULATION`): the buzzer goes to
**D9** (Velxio only polls Timer2 duty on PWM pins, so D8 is silent there — and
D10/D11 are the buttons) and key 7 becomes a digital button on **D12** (avr8js has
no A6). Keys 1–6 need no shim at all: a pushbutton with a pull-up *is* the 2019
polarity — idle ~1023, pressed ~0.

## Files

| Path | What |
|---|---|
| [firmware/src/main.cpp](firmware/src/main.cpp) | the whole rig: live threshold, buttons, readout, Velxio shim |
| [emulation/keyboard-test.yaml](emulation/keyboard-test.yaml) | circuit spec (7 keys + 2 buttons + buzzer) |
| [emulation/keyboard-test.vlx](emulation/keyboard-test.vlx) | generated project — import into Velxio and Run |
| [HARDWARE.md](HARDWARE.md) | pin map, BOM, wiring detail |
| [images/wiring-v2.5.png](images/wiring-v2.5.png) | wirewright-rendered wiring |

**Next revision:** [V3 — game prototype](../v3-game-prototype/) keeps the same
keyboard and adds the feedback LEDs, a game-select button and the first relay.

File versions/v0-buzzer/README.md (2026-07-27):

# V0 — buzzer bring-up rig (2026)

The smallest board in the project: **an ATmega328 and one passive buzzer on D8.**
No keys, no LEDs beyond the on-board one, no game, no touch sensing. The firmware
plays a C-major scale up and down, forever, with real silence between notes.

If the scale sounds right here, the buzzer and its wiring are fine and any problem
is upstream (sensing, timing, the game). If it sounds wrong here, you have removed
every other suspect.

> **Not a historical board.** V1–V5 are the real lineage; V0 was created on
> 2026-07-26 as a diagnostic. It is numbered 0 because its board is a *subset* of
> every other version — take any board in this repo, remove everything except the
> buzzer, and you have V0.

<div align="center">
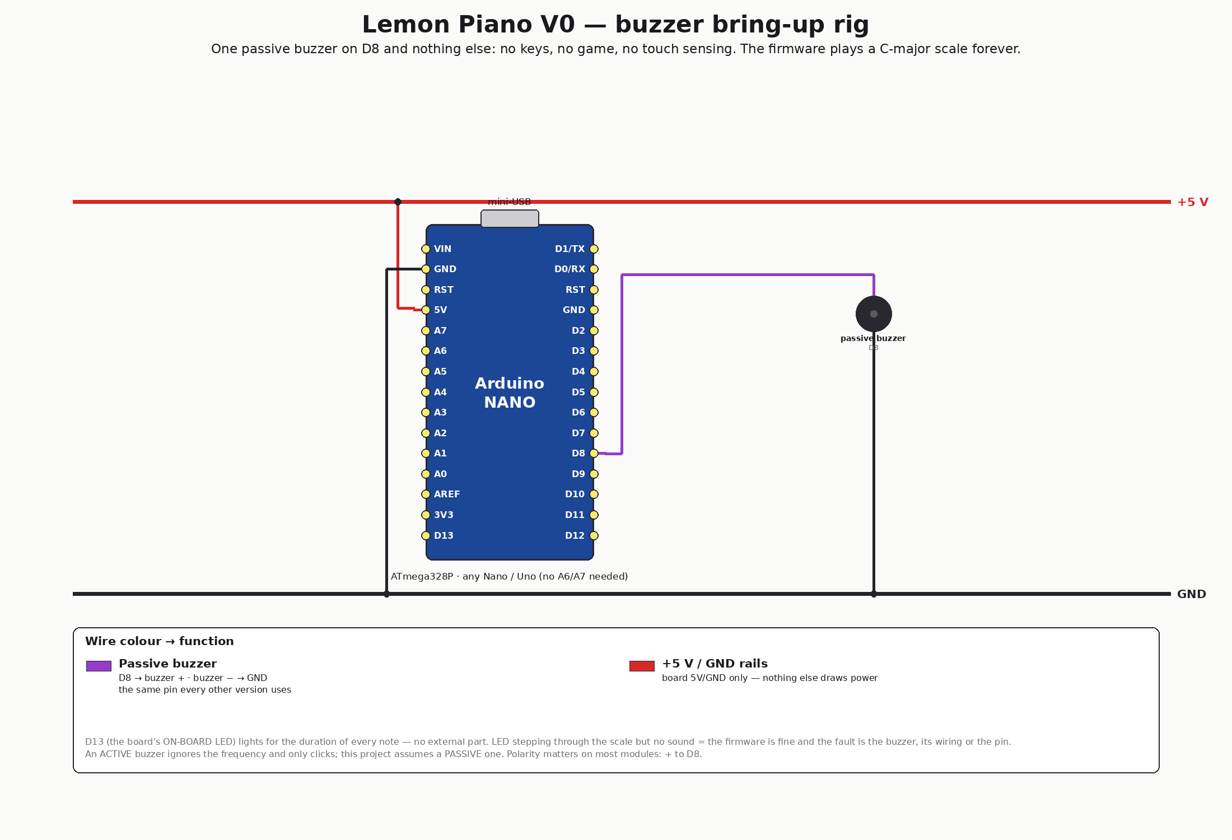
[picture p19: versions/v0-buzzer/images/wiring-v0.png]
V0 wiring diagram

</div>

## What you hear and see

```
C4  D4  E4  F4  G4  A4  B4  C5      ascending   (262 → 523 Hz)
C5  B4  A4  G4  F4  E4  D4          descending, back to the start
… 700 ms pause, then again, forever
```

- Each note sounds for **300 ms**, followed by **80 ms of real silence** — so a
  dropout, a stuck note or a wrong pitch is obvious by ear.
- The **on-board LED (D13)** lights for the duration of every note. This is the
  key diagnostic: *LED stepping through the scale but no sound* ⇒ the firmware is
  running fine and the fault is the buzzer, its wiring, or the pin.
- Every note is printed at **9600 baud**: `note 3/14 - 330 Hz`.

> **Field result, 2026-07-26 — V0 earned its keep on the first run.** A build whose
> buzzer had started sounding wrong (one continuous, discontinuous-sounding tone)
> was traced with this board: the same V0 firmware played the scale cleanly on a
> *different* Nano, so the fault was the original **board**, not the buzzer, the
> wiring, the amplifier or the game firmware. See
> [HARDWARE.md](HARDWARE.md#if-it-still-sounds-wrong--in-order) step 7.

## Flash it

```bash
cd firmware
pio run -t upload                            # Nano, old bootloader (57600) — default
pio run -e nanoatmega328new -t upload        # if that times out ("programmer is not responding")
pio run -e uno -t upload                     # Uno (V0 needs no A6/A7)
pio device monitor                           # 9600 baud — watch the notes go by
```

### Testing the *other* playback path

Every version drives the buzzer two ways, and they can fail independently:

| Build | Path | Used in the real game for |
|---|---|---|
| `pio run -t upload` (default) | `tone()` / `noTone()` — AVR hardware timer | key notes, the "wrong" tone |
| `pio run -e nanoatmega328-buzz -t upload` | bit-banged `buzz()` — `digitalWrite` + `delayMicroseconds` | the Mario victory / death themes |

Flash both. If the scale is clean on one and wrong on the other, you have located
the fault precisely; if both are wrong, it is the hardware.

## Wiring (that's all of it)

```
 D8  ──────────── buzzer (+)
 GND ──────────── buzzer (−)
```

Nothing else — no resistor needed. ⚠️ Two classic traps: a **passive** buzzer is
required (an *active* one ignores the frequency and just clicks at its own pitch),
and most buzzer modules are **polarised** (+ to D8). Details:
[HARDWARE.md](HARDWARE.md).

## Emulation — ✅ verify green

The reference recording, in the browser, on the same firmware:

```bash
PIPE=../../../velxio-multi-board-emulator/harness/.venv/bin/velxio-pipeline
$PIPE stack up        # then import emulation/lemon-piano.vlx at http://localhost:3080/editor
$PIPE run --mode verify --spec emulation/lemon-piano.yaml --out emulation/runs
```

Play it in the browser and compare it with your board by ear — that is the fastest
way to judge "it doesn't sound as usual". `verify` asserts the banner, that the
buzzer pin toggles through the scale (7 496 edges) and that the scale **completes
and repeats** (a note that never ends is the classic browser failure). Last run:
**pass** (2026-07-26). Browser buzzer is on **D11**, not D8 — see
[emulation/README.md](emulation/README.md).

## Files

| Path | What |
|---|---|
| [firmware/src/main.cpp](firmware/src/main.cpp) | the whole thing: scale table, both playback paths, Velxio shim |
| [emulation/lemon-piano.yaml](emulation/lemon-piano.yaml) | circuit spec (one buzzer) |
| [emulation/lemon-piano.vlx](emulation/lemon-piano.vlx) | generated project — import into Velxio and Run |
| [HARDWARE.md](HARDWARE.md) | pin map, BOM, buzzer troubleshooting |
| [images/wiring-v0.png](images/wiring-v0.png) | wirewright-rendered wiring |

**Next revision:** [V1 — banana piano](../v1-banana-piano/) adds the 7 fruit touch
keys (and the HC-SR04 the tutorial rig carried) around this same buzzer.

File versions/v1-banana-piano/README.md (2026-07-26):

# V1 — banana piano 🍌 (2019)

The board this whole project grew from: the
[untitled.es](http://untitled.es) *fruit piano* tutorial rig. Seven pieces of
fruit are touch keys on A0–A6; touching one plays a fixed note on a speaker.
No LEDs, no game, no relays — an instrument, not a puzzle.

**Hardware delta:** the 2019 origin — historically the first board in this story
(the [V0 buzzer rig](../v0-buzzer/) is a 2026 diagnostic that isolates a *subset*
of it). 7 fruit keys with 220 Ω pull-ups, a speaker on D8, and an **HC-SR04
ultrasonic module** left over from the tutorial's other demo (mounted and wired,
its driving code commented out in the sketch).

<div align="center">
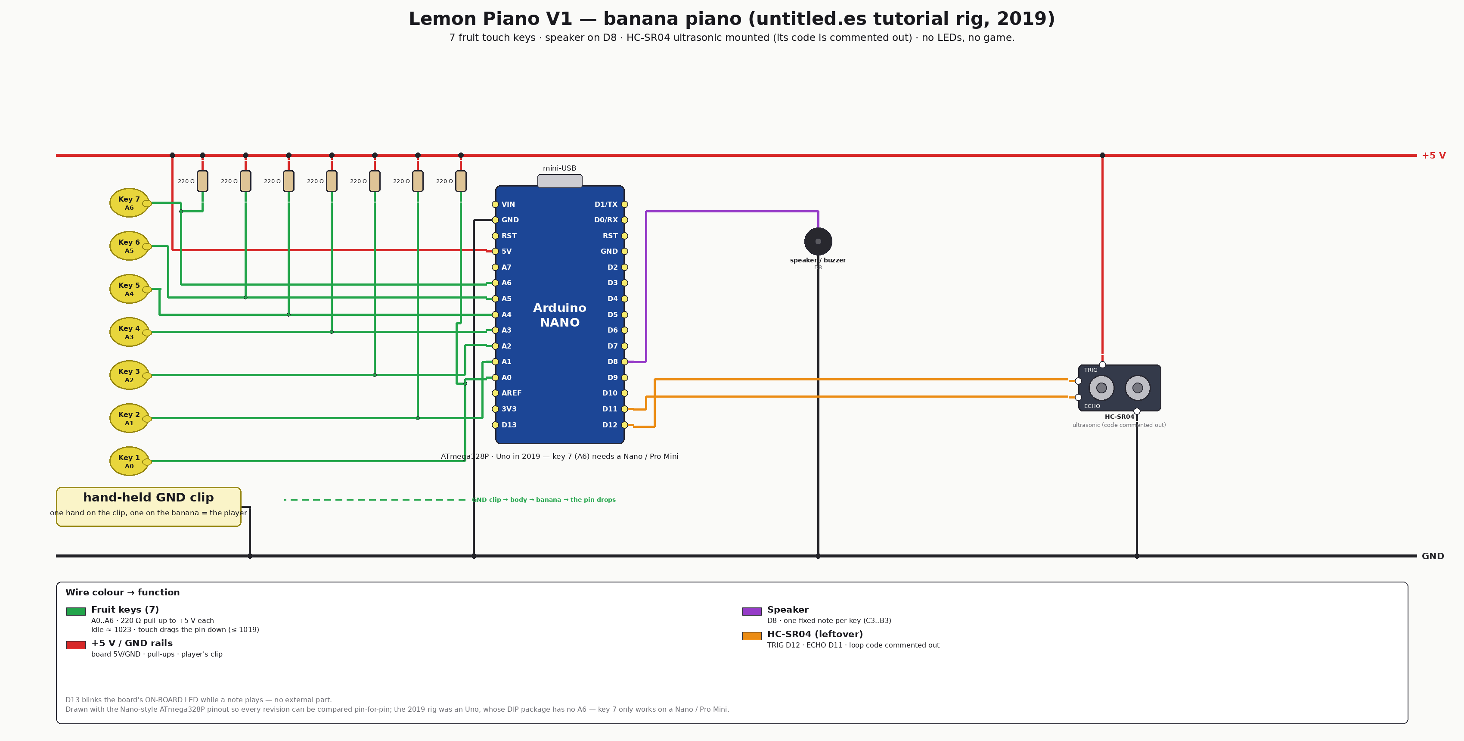
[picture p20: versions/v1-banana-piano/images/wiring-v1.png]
V1 wiring diagram

</div>

## How it plays

Hold the **GND** clip in one hand, touch a fruit with the other: your body drags
that analog pin down from its idle ~1023 and the sketch plays the key's note.
One fixed note per key, 150 ms, no sequence to guess.

| Key | 1 | 2 | 3 | 4 | 5 | 6 | 7 |
|---|---|---|---|---|---|---|---|
| Pin | A0 | A1 | A2 | A3 | A4 | A5 | A6 |
| Note | C3 | D3 | E3 | F3 | G3 | A3 | B3 |

Detection is `((analogRead(n) + analogRead(n)) / 2) <= 1019` — a 2-sample
average and a threshold only 4 counts below idle, because the body's resistance
is enormous next to the 220 Ω pull-up. See
[../../docs/HARDWARE.md](../../docs/HARDWARE.md) for the sensing physics and why
V4 inverted it.

## Firmware

Arduino IDE sketch, kept in its IDE-compatible folder and also driven by
PlatformIO (`src_dir = banana-piano`):

```bash
cd firmware
pio run                 # nanoatmega328 (default) — the env with a working key 7
pio run -e uno          # the historical board; A6 (key 7) does not exist on it
pio run -t upload
```

Comments and identifiers were translated to English during the 2026-07-12
rescue; the pristine Spanish original is in git history (commit
`rescue: original 2019 lemon piano files`). The commented-out HC-SR04 block is
preserved verbatim — it is the reason the module is on the diagram.

## Emulation

None. The 2019 sketches predate the `VELXIO_EMULATION` input shim, and a
faithful browser build would need three changes to historical code (buzzer moved
to a PWM pin with `OCR2A` cleared, key 7 off A6, pull-up buttons instead of the
divider). Rather than rewrite the oldest sketch in the repo, this board is
documented and buildable only — see [emulation/README.md](emulation/README.md)
for exactly what it would take, and `TODO.md` for the open decision.

## Files

| Path | What |
|---|---|
| [firmware/banana-piano/banana-piano.ino](firmware/banana-piano/banana-piano.ino) | the sketch (+ `pitches.h`) |
| [HARDWARE.md](HARDWARE.md) | pin map, BOM, wiring detail |
| [images/wiring-v1.png](images/wiring-v1.png) | wirewright-rendered wiring |
| [images/banana-piano-original.png](images/banana-piano-original.png) | the tutorial's own breadboard picture (Uno + speaker) |

**Next revision:** [V2 — keyboard test](../v2-keyboard-test/) strips the
ultrasonic module off the rig.

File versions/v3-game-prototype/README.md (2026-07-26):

# V3 — game prototype (2019)

The board where the piano becomes a **game**: guess a secret 10-note sequence,
with a red/green LED telling you whether each note was right. Both secret codes
that V4 and V5 still use were fixed here.

**Hardware delta vs [V2](../v2-keyboard-test/):** four parts arrive — a **red
LED (D2)**, a **green LED (D3)**, a **game-select push button (D4)** and a
**single relay channel (D5)** with its load. The keyboard is untouched.

<div align="center">
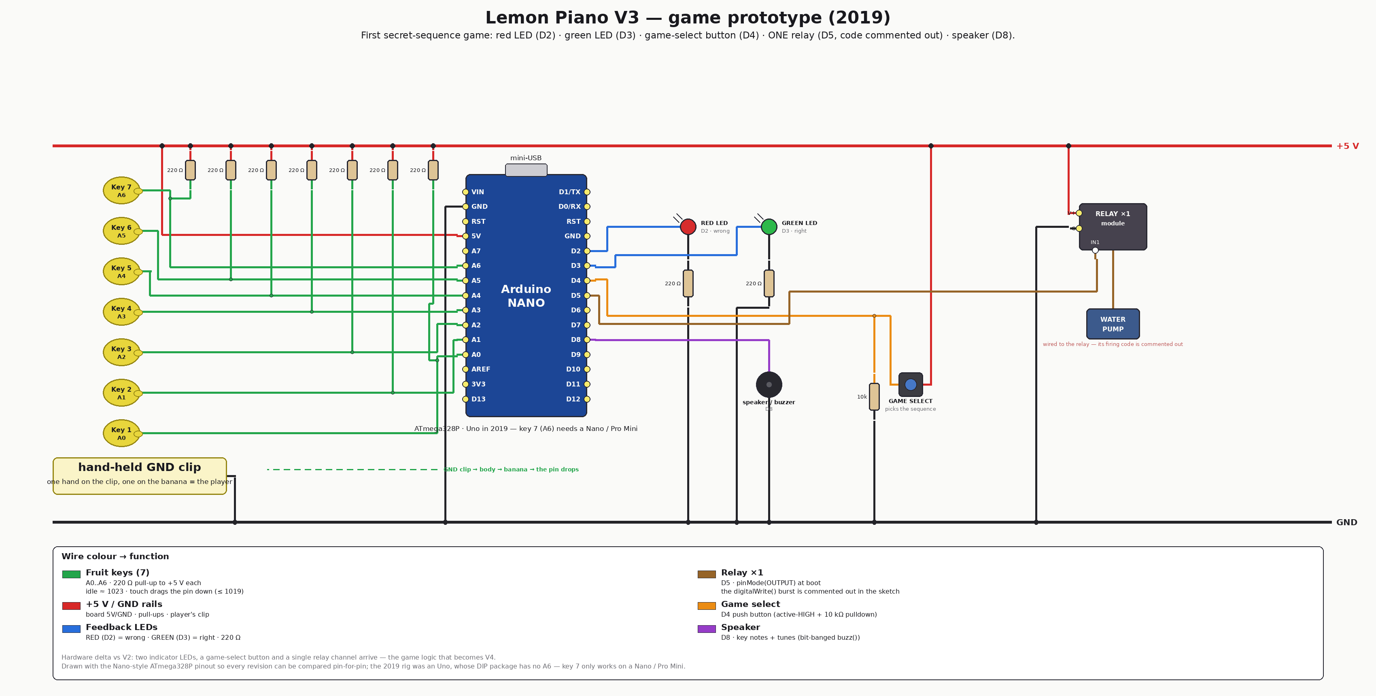
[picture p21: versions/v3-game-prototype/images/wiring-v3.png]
V3 wiring diagram

</div>

## How it plays

1. **Pick the game** with the D4 button at start-up (held HIGH = game 1).
2. **Touch fruit** — each key plays its note (the note *set* switches with the
   game, so the same 7 keys cover two octaves).
3. **Guess the sequence.** A correct note lights the **green** LED and advances
   the sequence; a wrong one lights the **red** LED and resets it. LEDs clear
   after a delay counted in loop iterations.
4. Complete the sequence → the theme plays through the speaker.

### Secret codes (spoilers)

Keys numbered 1–7, left to right — the same codes that survive into V4/V5:

| Game | Melody | Code |
|---|---|---|
| 1 | Super Mario Bros — Main Theme | `6, 5, 6, 7, 2, 5, 2, 1, 3, 4` |
| 2 | Super Mario Bros — Underworld | `3, 6, 1, 4, 2, 5, 3, 6, 1, 4` |

| Key | 1 | 2 | 3 | 4 | 5 | 6 | 7 |
|---|---|---|---|---|---|---|---|
| Game 1 note | E6 | G6 | A6 | B6 | C7 | E7 | G7 |
| Game 2 note | A3 | A#3 | C4 | A4 | A#4 | C5 | D5 |

> **The relay is wired but silent.** `pinMode(relay, OUTPUT)` runs at boot, yet
> the only `digitalWrite(relay, …)` burst in the sketch sits inside a commented
> block. So the channel is on the board and initialised, but nothing fires it —
> the water-pump penalty becomes real in [V4](../v4-water-pump/), with a second
> channel and a trigger condition.

Known rough edges of this prototype (all cleaned up in V4, see
[../../CHANGELOG.md](../../CHANGELOG.md) 2026-07-12): LED timeout counted in loop
iterations, no debounce/edge detection, melodies in RAM, `sequenceLength = 9`
("sequence length − 1"), and the inverted-threshold sensing inherited from V1.

## Firmware

```bash
cd firmware
pio run                 # nanoatmega328 (default) — the env with a working key 7
pio run -e uno          # the historical board; A6 (key 7) does not exist on it
pio run -t upload
```

RAM is tight here (≈ 706 B / 34 % on the Uno env) because every melody lives in
RAM — V4's `PROGMEM` move drops the same game to 309 B.

## Emulation

None — see [emulation/README.md](emulation/README.md). Of the three 2019 boards
this is the one worth emulating first: it has a real game to assert on.

## Files

| Path | What |
|---|---|
| [firmware/game-prototype/game-prototype.ino](firmware/game-prototype/game-prototype.ino) | the sketch (notes + melodies inlined) |
| [HARDWARE.md](HARDWARE.md) | pin map, BOM, wiring detail |
| [images/wiring-v3.png](images/wiring-v3.png) | wirewright-rendered wiring |

**Next revision:** [V4 — water pump](../v4-water-pump/) — the 02/2019 lemon
build: Nano, clip flipped to +5 V, second relay channel, restart button, and the
pump that actually sprays you.

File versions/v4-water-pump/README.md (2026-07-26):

# V4 — lemon piano with the water pump (02/2019)

The university build: bananas become **lemons**, the Uno becomes a **Nano**, the
player's clip moves to **+5 V**, and a **relay-driven water pump** sprays you
when you miss late in the sequence. Ten penalties and the Mario death tune plays
until you hit RESTART.

**Hardware delta vs [V3](../v3-game-prototype/):**

- the hand-held clip flips from **GND to +5 V**, and the 220 Ω resistors move
  from pull-ups to **series resistors** — pins now float near 0 and a touch
  *raises* the reading (the sensing inversion);
- a **second relay channel** (D5 + D6) drives a real **water pump**;
- a **RESTART button** on D7;
- game select becomes a proper **SPDT switch** on D4;
- board: **Arduino Nano** (A6 is now genuinely required for key 7).

<div align="center">
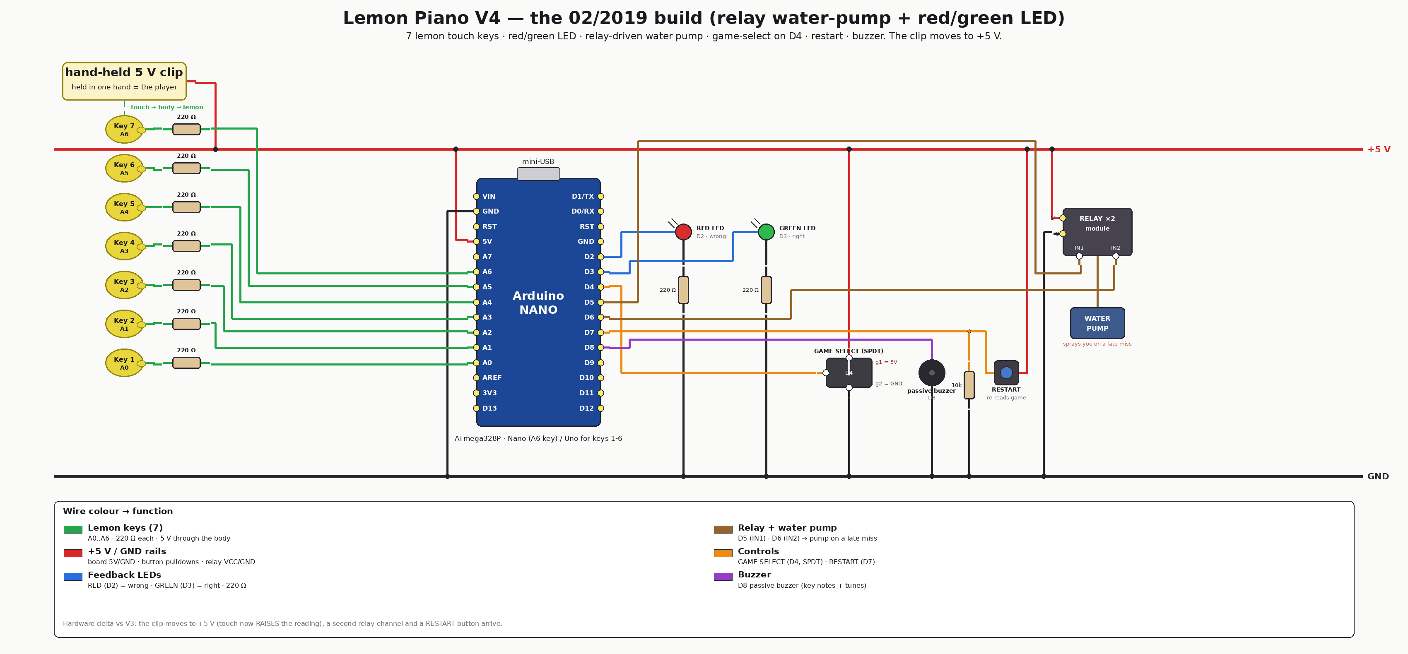
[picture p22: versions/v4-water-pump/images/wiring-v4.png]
V4 wiring diagram

</div>

## How it plays

1. **Power on / RESTART (D7).** The D4 switch picks the game: HIGH = game 1
   (Mario Main Theme), LOW = game 2 (Underworld). `calibrate()` samples each
   key's floating baseline — hands off the lemons at boot.
2. **Touch lemons.** Hold the 5 V clip in one hand, touch a lemon with the other;
   your body closes the circuit and the note plays on the buzzer.
3. **Guess the 10-note secret melody.** Correct note → **green LED**; wrong note
   → **red LED** and the sequence restarts from the first note.
4. **Miss from note 7 onward → the pump fires** for 1 s (`PUMP_FROM_STEP = 7`).
5. **Ten penalties (`MAX_FAILS = 10`)** → the death tune plays and the game is
   over until RESTART.
6. **All ten notes right** → the victory theme plays.

### Secret codes (spoilers)

| Game | Melody | Code |
|---|---|---|
| 1 | Super Mario Bros — Main Theme | `6, 5, 6, 7, 2, 5, 2, 1, 3, 4` |
| 2 | Super Mario Bros — Underworld | `3, 6, 1, 4, 2, 5, 3, 6, 1, 4` |

| Key | 1 | 2 | 3 | 4 | 5 | 6 | 7 |
|---|---|---|---|---|---|---|---|
| Game 1 note | E6 | G6 | A6 | B6 | C7 | E7 | G7 |
| Game 2 note | A3 | A#3 | C4 | A4 | A#4 | C5 | D5 |

## Firmware

This is the 02/2019 game with the 2026-07-12 fix pass applied (TODO #1–#12:
edge-triggered input, `millis()` timing, `PROGMEM` melodies, auto-calibrated
touch, no UART clobber) — and **nothing after that**. This is also the last board
with the water pump: [V4.5](../v4.5-margin-buttons/) removes the relay pair and the
pump, and adds the touch-tuning buttons.

Touch threshold here is the simple form: `threshold = baseline + TOUCH_MARGIN`
with `TOUCH_MARGIN = 100`, calibrated once at boot.

```bash
cd firmware
pio run                          # nanoatmega328 (default, old bootloader)
pio run -e nanoatmega328new      # Nano with the new bootloader
pio run -e uno                   # keys 1-6 only (Uno DIP has no A6)
pio run -e emulation             # compile-check the VELXIO_EMULATION shim
pio run -t upload
pio device monitor               # 9600 baud — logs Game/OK/WRONG/WIN
```

RAM 309 B (15 %), flash 7 296 B (24 %) on `nanoatmega328`.

## Emulation — ✅ verify green

Real firmware on an emulated ATmega328 in the browser, with clickable lemons, the
red/green LEDs and a blue **pump indicator** LED standing in for the relay pair:

```bash
cd .                              # from this version directory
PIPE=../../../velxio-multi-board-emulator/harness/.venv/bin/velxio-pipeline
$PIPE stack up                    # then import emulation/lemon-piano.vlx at http://localhost:3080/editor
$PIPE run --mode verify --spec emulation/lemon-piano.yaml --out emulation/runs
```

`verify` injects game 2's secret code and asserts the firmware boots
(`Lemon Piano V4`), picks `Game 2`, flashes the green LED, sings, and logs `WIN`.
Last run: **pass** (2026-07-26). Details and the browser pin map:
[emulation/README.md](emulation/README.md).

## Files

| Path | What |
|---|---|
| [firmware/src/main.cpp](firmware/src/main.cpp) | the V4 game + the Velxio input shim |
| [firmware/include/notes.h](firmware/include/notes.h) | note frequency table |
| [emulation/lemon-piano.yaml](emulation/lemon-piano.yaml) | circuit spec (source of truth) |
| [emulation/lemon-piano.vlx](emulation/lemon-piano.vlx) | generated project — import into Velxio and Run |
| [HARDWARE.md](HARDWARE.md) | pin map, BOM, wiring detail |
| [images/wiring-v4.png](images/wiring-v4.png) | wirewright-rendered wiring |

**Next revision:** [V4.5 — margin buttons](../v4.5-margin-buttons/) takes the
relay pair and the water pump **off** the board and adds two buttons that tune
touch sensitivity without a reflash.

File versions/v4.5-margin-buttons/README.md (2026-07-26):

# V4.5 — no water pump, plus the touch-tuning buttons (2026)

V4's game — the same 10-note secret melodies, the same red/green LED feedback, the
same penalty counter and death tune — on a board that **dropped the relay pair and
the water pump** and gained **two buttons for tuning touch sensitivity while you
play**. Fruit, hands, power supplies and mains noise all move the touch threshold;
before this revision the only fix was a reflash.

**Hardware delta vs [V4](../v4-water-pump/):**

- **off** the board: the **2-channel relay module and the water pump** — D5 and D6
  are now unused. A miss from note 7 onward still counts a penalty and plays the
  low warning groan; it just doesn't spray you;
- **on** the board: **MARGIN + on D10** (less sensitive) and **MARGIN − on D11**
  (more sensitive), wired active-HIGH exactly like RESTART (button → 5 V + 10 kΩ
  pulldown). The matching firmware change (noise-adaptive calibration) needs no
  wiring at all.

<div align="center">
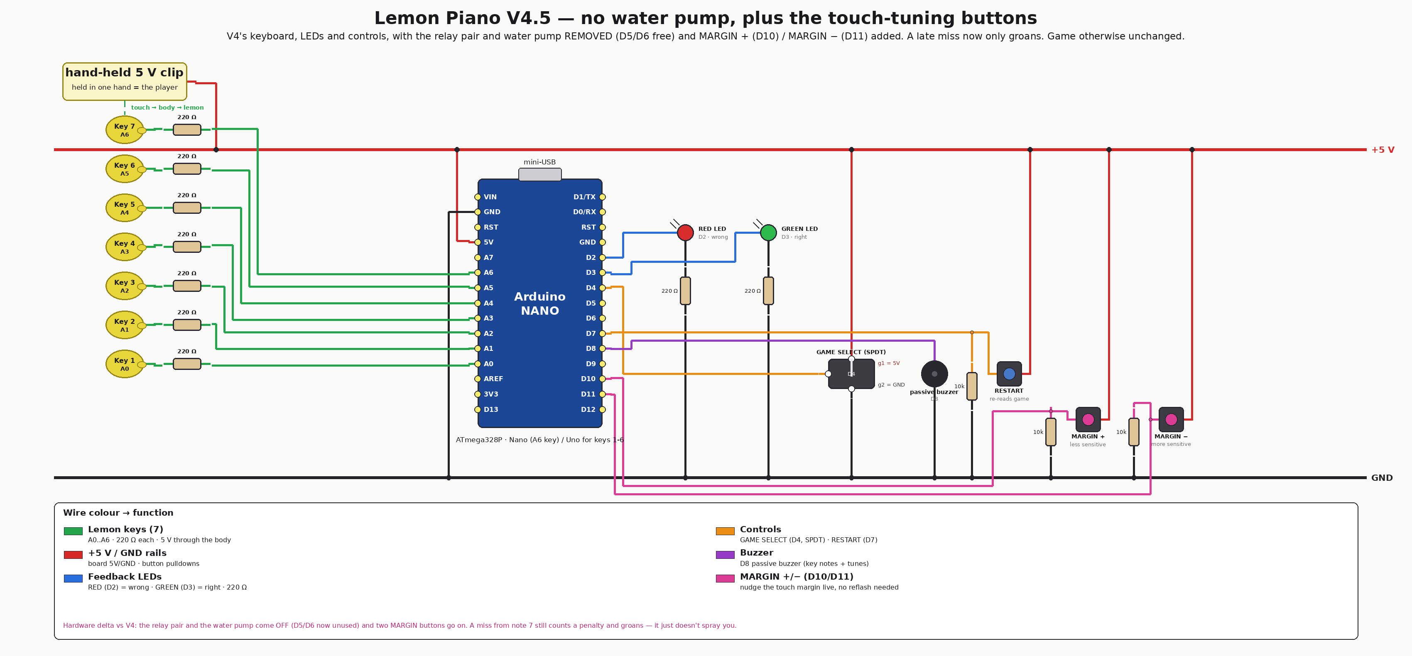
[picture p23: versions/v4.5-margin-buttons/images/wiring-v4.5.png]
V4.5 wiring diagram

</div>

## How it plays

Exactly like [V4](../v4-water-pump/README.md) — pick the game with the D4 switch,
touch lemons, guess the 10-note melody, green LED = right / red = wrong — with
these differences:

| | V4 | V4.5 |
|---|---|---|
| Miss from note 7 (`PENALTY_FROM_STEP`) | low groan **+ 1 s of water pump** | low groan only (`playPenalty()`) |
| Ten penalties (`MAX_FAILS = 10`) | death tune until RESTART | unchanged |
| Touch threshold | `baseline + 100` (fixed `TOUCH_MARGIN`) | `baseline + max(40, 3 × measured noise)`, capped at 900 |
| Calibration runs | at boot | at boot **and on every RESTART** |
| Live tuning | none (reflash) | **MARGIN +/− buttons**, ±10 per press, applied on top of every key's auto margin |

Constants: `MIN_TOUCH_MARGIN = 40`, `NOISE_FACTOR = 3`, `THRESHOLD_CAP = 900`,
`MARGIN_STEP = 10`, `PENALTY_MS = 1000`. Keep hands off the lemons during boot and
after a RESTART — that is when the baseline and noise are sampled.

### Secret codes (spoilers)

| Game | Melody | Code |
|---|---|---|
| 1 | Super Mario Bros — Main Theme | `6, 5, 6, 7, 2, 5, 2, 1, 3, 4` |
| 2 | Super Mario Bros — Underworld | `3, 6, 1, 4, 2, 5, 3, 6, 1, 4` |

| Key | 1 | 2 | 3 | 4 | 5 | 6 | 7 |
|---|---|---|---|---|---|---|---|
| Game 1 note | E6 | G6 | A6 | B6 | C7 | E7 | G7 |
| Game 2 note | A3 | A#3 | C4 | A4 | A#4 | C5 | D5 |

## Firmware

```bash
cd firmware
pio run                          # nanoatmega328 (default, old bootloader)
pio run -e nanoatmega328new      # Nano with the new bootloader
pio run -e uno                   # keys 1-6 only (Uno DIP has no A6)
pio run -e emulation             # compile-check the VELXIO_EMULATION shim
pio run -t upload
pio device monitor               # 9600 baud — logs Game/OK/WRONG/WIN + margin changes
```

The relay code is **gone, not disabled**: no `RELAY_1`/`RELAY_2` pins, no
`pumpOff()`, no `firePump()`. `playPenalty()` replaces the last one and only makes
noise. All four envs build green.

## Emulation — ✅ verify green

The V4 browser circuit minus the blue pump-indicator LED (**the MARGIN buttons are
hardware-only** — D11 is the buzzer in the browser build and there are no pins to
spare), compiling *this* version's firmware, so the emulation also exercises the
noise-adaptive calibration path:

```bash
PIPE=../../../velxio-multi-board-emulator/harness/.venv/bin/velxio-pipeline
$PIPE run --mode verify --spec emulation/lemon-piano.yaml --out emulation/runs
```

`verify` injects game 2's secret code and asserts `Lemon Piano V4.5` → `Game 2` →
green LED → buzzer → `WIN`. Last run: **pass** (2026-07-26). Browser pin map and
the shim rationale: [emulation/README.md](emulation/README.md).

## Files

| Path | What |
|---|---|
| [firmware/src/main.cpp](firmware/src/main.cpp) | V4's game without the pump + noise-adaptive calibration + MARGIN buttons |
| [firmware/include/notes.h](firmware/include/notes.h) | note frequency table |
| [emulation/lemon-piano.yaml](emulation/lemon-piano.yaml) | circuit spec (source of truth) |
| [emulation/lemon-piano.vlx](emulation/lemon-piano.vlx) | generated project — import into Velxio and Run |
| [HARDWARE.md](HARDWARE.md) | pin map, BOM, wiring detail |
| [images/wiring-v4.5.png](images/wiring-v4.5.png) | wirewright-rendered wiring |

**Next revision:** [V5 — ten-LED bar](../v5-led-bar/) strips the red LED *and*
these two buttons, and spends every freed pin on a ten-LED progress bar.

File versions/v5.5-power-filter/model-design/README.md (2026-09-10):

# Enclosure design (model-design)

`reference-images/` are Sergio's caliper-annotated photos of the parts that
must fit in the box besides the PCB: the speaker (27.8 × ~24.5 × 15.1 mm,
mounting-ear holes 30.7 mm apart), the LM386 amplifier module (40.7 × 13.8,
13.6 tall), the optional USB-C keep-alive gadget (27.7 × 10.9, 13.6 tall),
the wanted left-to-right layout (`comp distribution.png`) and the openings
(`holes.png`).

`enclosure-v6/` and `fruit-arc-v5/` are the **current** design. `enclosure-v4/`
is superseded — kept only because its README section explains how the board got
raised in the first place. `enclosure-v2/`
is what was physically printed on 2026-09-07/08 and is kept as the record.
Everything is generated from the parametric recipes in the 3D-design repo
(`3d-modeling-agent`, `recetas/piano-limones-caja-v4` and
`recetas/piano-limones-luna-v4` — that repo is the source of truth; the STLs
here are copies of its gate output).

## v6 of the box (2026-09-10): three fixes found with the parts in the box

Three corrections Sergio found once the v5 box was printed and populated. All
three are the same lesson: **a component modelled as a plain brick hides its
real features.**

| File | What | Print |
|---|---|---|
| `enclosure-v6/tapa.stl` | lid — **needs reprinting** | 33.34 g, 1 h 09 m |
| `enclosure-v6/base.stl` | base — changed, but see below | 63.79 cm³ |

1. **LED slot 5.0 → 5.5 mm.** *"A touch wider, barely half a millimetre, so the
   LEDs go in properly — right now they rub a little and that could cause
   friction opening and closing the lid."* They rubbed because of v5 itself: with
   the board raised the LEDs are no longer soldered proud, so the slot stopped
   being a peephole and became the **socket** the LED head enters. 5.5 leaves
   2.0 mm of real air, 1.0 per side.
2. **The volume trimmer is not on the module's centreline.** *"You worked the
   hole out as if the pot were in the middle of the board."* It was an
   assumption of mine, not a measurement. Measured **from his photo** — blue
   trimmer and board edges segmented by colour, scaled by the **14.4 mm between
   the cradle rails** (a model dimension, not a guess): the trimmer axis sits
   **3.0 mm west** of the module axis. The access changes from a Ø6.4 circle to
   a **10.0 × 6.4 slot** shifted west — a slot rather than a circle because a
   handheld photo is easily ±0.5 mm out and looking down on a 13.6 mm-tall part
   makes it worse, so the screwdriver still reaches if I'm 2 mm off.
3. **The amp's screw terminal fouled the cradle stop.** *"On the side opposite
   the pins it has the speaker input, and right now it hits the wall a bit —
   you need to take that wall down."* The wall is the cradle's 8 mm south stop;
   the terminal sits **on top of** the board (top face at z 6.1), so the stop
   covered the 3.9 mm where the wires enter. Both amp stops now come up only to
   **the board's top face** — they stop the board's **edge** and leave anything
   soldered above it clear — and they are set back **1.5 mm** instead of 0.3 so a
   terminal overhanging the edge passes over them.

The screw terminal now has its **own envelope** in `comprobar_encaje.py` (10.2 ×
7.5 × 9.0 on the board's top face, overhanging 1.5 mm — the worst case the design
accepts), and the check reports what the wire has to the south: **1.4 mm worst
case** before the x=150 screw column, 2.9 mm if the terminal is flush. Moving
that column would fix it but would force reprinting the base too, because the
lid's countersinks would no longer line up with the already-printed base.

**The base does not need reprinting**: the only change is 4 mm of height off two
1.35 mm walls, which comes off the printed part with a file in a minute.

## v5 of the box (2026-09-09): the lid becomes a mask, the box drops 6.2 mm

Sergio's second pass the same day: *"a hole with plenty of clearance in the lid
for the two capacitors, the choke and the diodes, and for the 7-pin connector.
Also holes for the internal buttons, in case the panel ones fail. The point is
to redesign the box lower, with the PCB as close to the lid as you possibly
can, so its components show. Adjust the speaker and the amplifier so they don't
collide and you can cut height."*

| File | What | Print |
|---|---|---|
| `enclosure-v5/base.stl` | box body, 219.2 × 66.9 × **23.4 mm** | upright, **68.78 g, 2 h 09 m** |
| `enclosure-v5/tapa.stl` | lid, modelled face-down as printed | **33.43 g, 1 h 09 m** |

The conceptual shift: once the tall parts have holes, the ceiling is no longer
set by the tallest component but by whatever has **no** hole — which is the
**M2 screw head** on the standoffs, 1.5 mm.

- **Standoffs 9 → 17.3 mm**: the PCB's top face rises to **z 20.9**, i.e.
  **2.5 mm** below the lid's inner face. `base_alto` 29.6 → **23.4**; assembled
  height 32.8 → **26.6 mm**.
- **Six openings** over the board: the two capacitors in **one** hole (as
  asked — they are 10 mm apart and Ø8, so two holes would leave a 2 mm rib),
  the filter block (choke + both diodes + the 5 V input) in another, the key
  connector (the "7-pin" one is really a 1×8: 7 keys plus the player's ground
  clip), a slot serving **both internal tact switches**, which merges with the
  Nano window, and the buzzer — whose Ø12 body now passes through instead of
  speaking through a 3.4 sound hole. Clearance 1.2 mm per side on top of
  process compensation.
- **The mini-USB channel is gone**: with the board up there, the Nano's
  connector sits *above* the visible face, so the channel only weakened the lid.
- **The LEDs no longer need to be soldered raised** — the v4's one awkward
  assembly step. A short-legged Ø3 LED now ends inside the lid's 3.2 mm and
  shines through its slot.
- **Panel buttons go back side by side** (− left, + right): two Ø11 nuts in a
  column need 24 mm of wall and the wall is 23.4. Their bodies pass *under* the
  board now.
- **The collision Sergio predicted was real and measured**: 11.5 mm³ between
  the speaker's cable and the amplifier module. In v4 the cable exited above the
  amp (z 22.2 vs its 18.1 top); lowering the box drops it to z 16.0, level with
  it. The amp-to-collar gap goes 1.5 → 5.0 mm and the east gap 7.0 → 5.0, so the
  box grows just 1.5 mm in length, with an assert per speaker orientation.

What now limits the height, in order: the amp's **straight Dupont header**
(z 22.6, 0.8 mm under the lid) and the **speaker's back** (z 4.9, 2.9 mm off
the floor).

**One assembly condition:** the speaker output J5 must use a soldered wire or a
**right-angle** connector, never a straight Dupont (16.5 mm won't fit). It is
the only header without a hole, because opening it would merge three openings
into one 70 mm gap and leave the lid's north edge as an unsupported 5 mm rib.
It gets a 2 mm relief pocket in the inner face instead.

Components that deliberately stand proud of the visible face: the socketed Nano
with its ICSP header (+12.9 mm), the key connector with its Dupont (+10.8) and
the two capacitors (+9.3).

## v4 of the box (2026-09-09, superseded): the PCB rises to the lid

Sergio found the flaw with the printed box in his hands: with the board sitting
at the bottom, the Nano window and the LED slot in the lid looked at 22 mm of
air. So the board goes up.

| File | What | Print |
|---|---|---|
| `enclosure-v4/base.stl` | box body, 217.7 × 66.9 × 29.6 mm | upright, **74.44 g, 2 h 13 m** |
| `enclosure-v4/tapa.stl` | lid, modelled face-down as printed | **34.40 g, 1 h 10 m** |

- **Standoffs 4 → 9 mm**: the top face of the PCB moves from z 7.6 to **z 12.6**.
  The ceiling is set by the **Dupont plugged into the pin strips (16.5 mm)**,
  not by the Nano: they end 0.5 mm below the lid. The Nano reaches 31.2, i.e.
  **1.6 mm below the visible face** — visible through its window and swappable
  without opening the box. The 10 LEDs must be **soldered 11.6 mm raised** to
  reach the slot, which is what Sergio planned. The tallest filter part, the
  capacitor, is 15 mm (his measurement) and clears by 2 mm.
- **The two panel buttons leave the lid** (a 20 mm body would hit the board)
  and move to the **front wall in a column**: **+ at z 21, − at z 8**, hole
  Ø6.3 = 5.0 thread + 0.8 process compensation + 0.5 assembly clearance, each
  with its sign in relief beside it.
- **18 mm front strip** (interior depth 62.5, +4.5 mm overall): it takes the
  button bodies (14.5 mm with pins) and the **16.3 × 30 ferrite** of the power
  lead, lying on the floor between two 4 mm stops.
- **LED slot narrowed 6.4 → 5.0**: it now guides the raised LEDs.
- **The lid stays single-level.** Sergio asked whether a stepped lid was worth
  it; with the board raised there is no clearance left to recover, and a step
  would add two overhangs and a visible seam to a part that today prints with
  no supports at all (1.59% overhang).

Everything else is as in v3: engraved logo with a checked 2 mm keep-out, DIN 562
square nuts in the six columns, centred key-ribbon slot, west power inlet
separated from the USB-C jack, speaker-cable notches on **both** sides of the
collar, 7-slot modern grille, cradles for the USB gadget and the LM386 with
trimmer access.

## v5 of the fruit arc (2026-09-09): the joint actually locks now

Sergio, with the v4 arc **assembled** in his hands: *"the puzzle pieces go in
and out without having to be fitted from above, and that means I'd need glue.
Make the puzzle tab more pronounced so it has to go in top-down and can't be
pulled apart once joined."*

**The neck size was never the problem, and that was the trap.** v4 had a Ø7.0
head against a 5.6 neck, and the check passed it — because it compared a
*formula* (`2·radius` vs `2·sqrt(radius² − offset²)`) and ignored the **relief
holes**. Those two holes sat **on the joint line itself**, and with their radius
plus clearance they opened the female's mouth to **7.70 mm** — wider than the
male's 7.10 head. The head simply walked out. Simulating extraction on the real
profile: **0.00 mm of deformation needed**.

The new profile is a **keyhole**: a **straight 4.4 mm neck** (a rectangle — the
only thing that sets the mouth) and a **Ø8.4 head** pushed 5.2 mm past the
joint line. Mouth 4.70 vs head 8.10 → **3.40 mm of deformation** would be needed
to pull it apart, so it can only be assembled and disassembled by **lowering one
piece onto the other**. No glue.

The relief holes are gone on purpose. They existed because the v4 circle crossed
the joint line at a very acute angle; in the keyhole that corner meets at **122°**
measured in the material. And here they did harm twice over: they opened the
mouth (the bug) and, at 0.9 mm, they poked past the head's arc leaving a
**0.63 mm** fin — 13.4 mm², caught by the gate on this very v5's first attempt.

And the part that actually mattered: `comprobar_puzzle.py` no longer compares a
formula. It **simulates the extraction** on the profile the recipe draws,
sweeping the tenon along the arc axis and measuring the deformation needed at
each position, requiring at least 2.0 mm — with a **new positive control**: the
same computation on the v4 profile must return 0.00 mm, i.e. reproduce the
failure Sergio is holding. Without that control, "3.40 mm" would prove nothing.

Nothing else changed: cups, numbers, wire channel and the rest are as in v4. The
longer tenon grows the west piece from 123.44 to 126.76 mm and the centre from
183.93 to 187.58.

| File | What | Print |
|---|---|---|
| `fruit-arc-v5/oeste.stl`, `este.stl` | end segments (2 cups each) | 35.50 / 34.36 g |
| `fruit-arc-v5/centro.stl` | middle segment (3 cups) | 57.90 g |

## v4 of the fruit arc (2026-09-08, superseded): oranges, puzzle joints, numbers

| File | What | Print |
|---|---|---|
| `fruit-arc-v4/oeste.stl`, `este.stl` | end segments (2 cups each) | 35.05 / 34.31 g |
| `fruit-arc-v4/centro.stl` | middle segment (3 cups), rotated to fit the bed | 57.35 g |

Open 140° arc, radius 226.7, seven cups **85 mm apart** with a Ø34 mouth so a
fat orange sits without touching its neighbour; **puzzle joints** (peg and
socket, 0.30 mm diametral clearance) instead of dowels, so no loose parts;
**numbers 1–7 on inclined wedges** on the outside, reading upright from outside
the arc; and the wire channel **extended past the end nail holes** so the nail
goes fully in — the four corrections Sergio asked for with the v3 arc printed.
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

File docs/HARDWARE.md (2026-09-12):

# Hardware fundamentals (shared across versions)

The parts of the build that do **not** change from board to board: how a piece of
fruit becomes a key, the one polarity flip in the project's history, and the
shared reference images. Per-board pin maps and BOMs live with their version:

| Version | Hardware doc |
|---|---|
| V0 — buzzer rig | [../versions/v0-buzzer/HARDWARE.md](../versions/v0-buzzer/HARDWARE.md) |
| V1 — banana piano | [../versions/v1-banana-piano/HARDWARE.md](../versions/v1-banana-piano/HARDWARE.md) |
| V2 — keyboard test | [../versions/v2-keyboard-test/HARDWARE.md](../versions/v2-keyboard-test/HARDWARE.md) |
| V2.5 — live threshold | [../versions/v2.5-threshold-buttons/HARDWARE.md](../versions/v2.5-threshold-buttons/HARDWARE.md) |
| V3 — game prototype | [../versions/v3-game-prototype/HARDWARE.md](../versions/v3-game-prototype/HARDWARE.md) |
| V4 — water pump | [../versions/v4-water-pump/HARDWARE.md](../versions/v4-water-pump/HARDWARE.md) |
| V4.5 — margin buttons | [../versions/v4.5-margin-buttons/HARDWARE.md](../versions/v4.5-margin-buttons/HARDWARE.md) |
| V5 — LED bar | [../versions/v5-led-bar/HARDWARE.md](../versions/v5-led-bar/HARDWARE.md) |
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

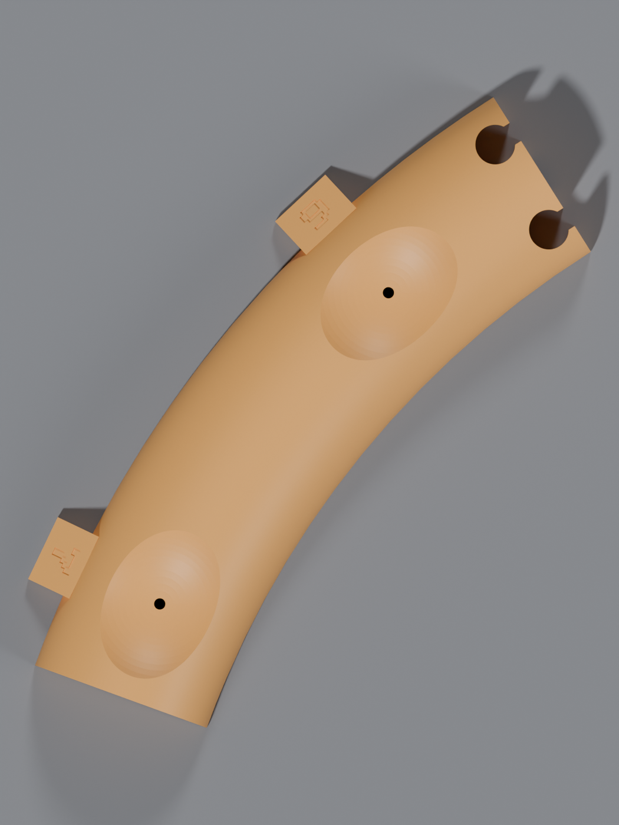
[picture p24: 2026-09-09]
versions/v5.5-power-filter/model-design/fruit-arc-v5/renders/este-hembra-planta.png

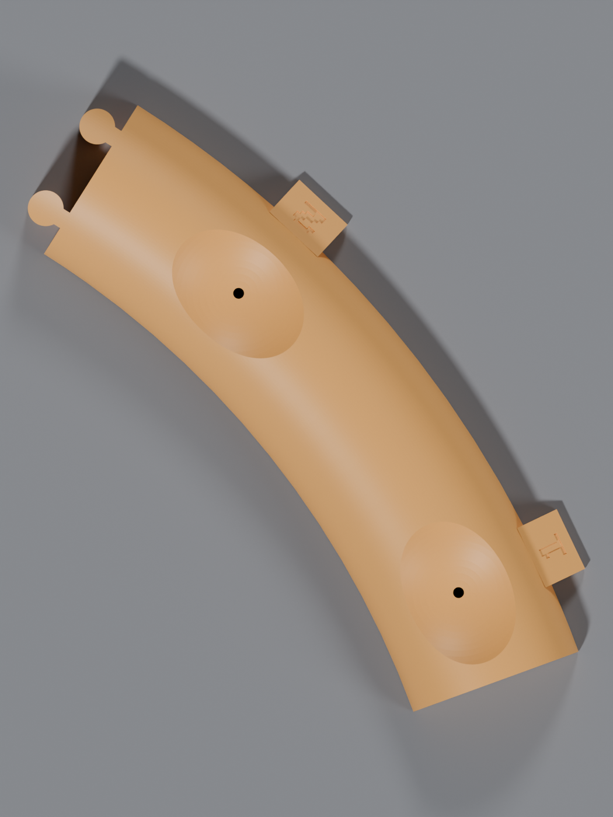
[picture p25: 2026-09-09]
versions/v5.5-power-filter/model-design/fruit-arc-v5/renders/oeste-junta-planta.png

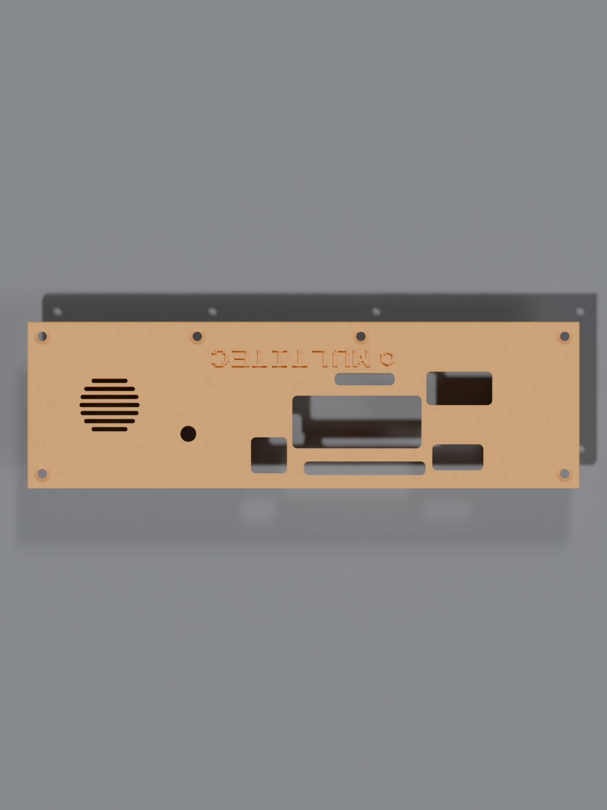
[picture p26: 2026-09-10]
versions/v5.5-power-filter/model-design/enclosure-v6/renders/tapa-marca.png

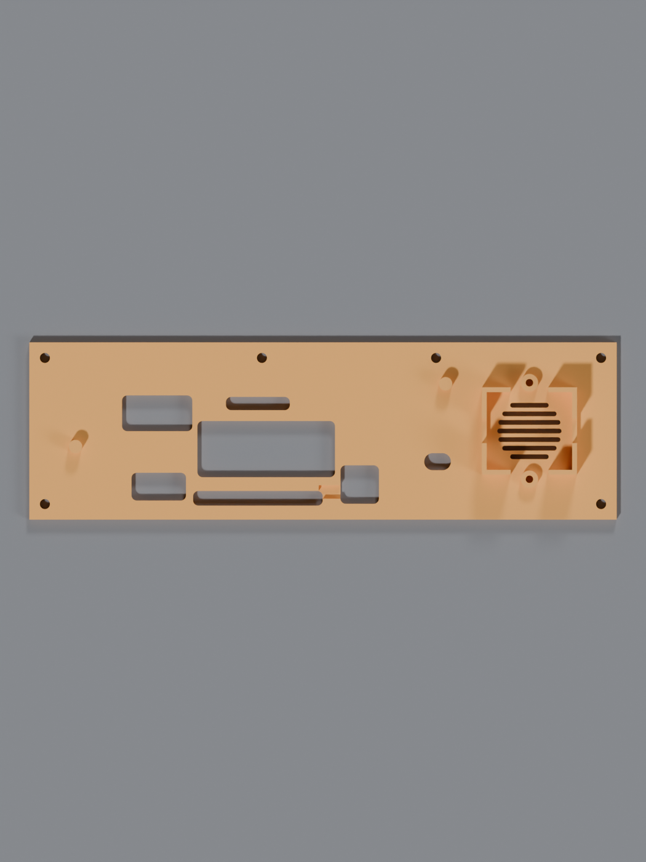
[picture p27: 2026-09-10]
versions/v5.5-power-filter/model-design/enclosure-v6/renders/tapa-planta.png

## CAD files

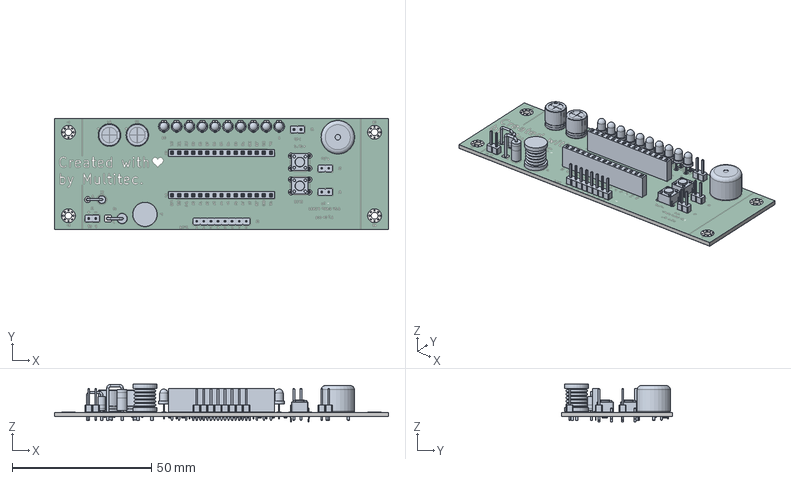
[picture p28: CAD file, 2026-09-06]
pcb/3d/lemon-piano-v0.7.1.step
120.0 x 40.0 x 13.6 mm
LED_D3.0mm_Green x 3
LED_D3.0mm x 2
D_DO-15_P5.08mm_Vertical_CathodeUp
L_Radial_D8.7mm_P5.00mm_Fastron_07HCP
SW_PUSH_6mm x 2
PinHeader_1x02_P2.54mm_Vertical x 4
PinSocket_1x15_P2.54mm_Vertical x 2
CP_Radial_D8.0mm_P3.50mm x 2
LED_D3.0mm_Orange x 2
D_DO-41_SOD81_P5.08mm_Vertical_AnodeUp
LED_D3.0mm_Yellow x 3
Buzzer_12x9.5RM7.6
PinHeader_1x08_P2.54mm_Vertical
R_0805_2012Metric x 18
C_0805_2012Metric x 2
board_copper
board_pad
board_silkscreen x 2
board_soldermask x 2
board_PCB

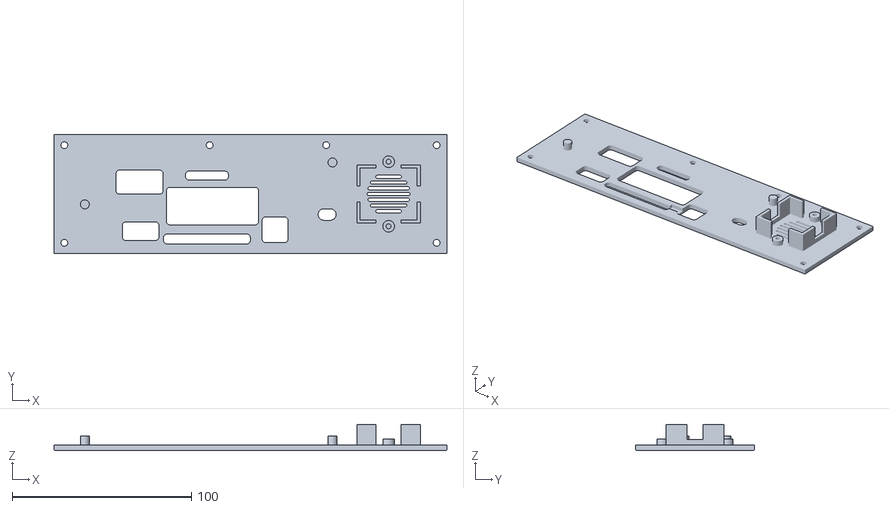
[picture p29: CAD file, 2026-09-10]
versions/v5.5-power-filter/model-design/enclosure-v6/tapa.stl
219.2 x 66.1 x 14.6

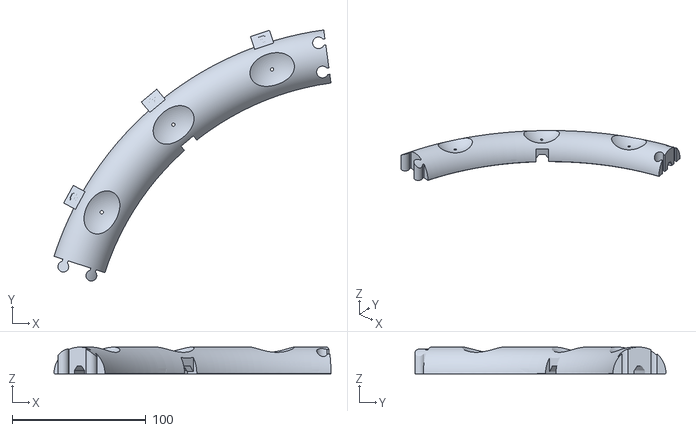
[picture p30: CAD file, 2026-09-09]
versions/v5.5-power-filter/model-design/fruit-arc-v5/centro.stl
207.0 x 187.6 x 20.0

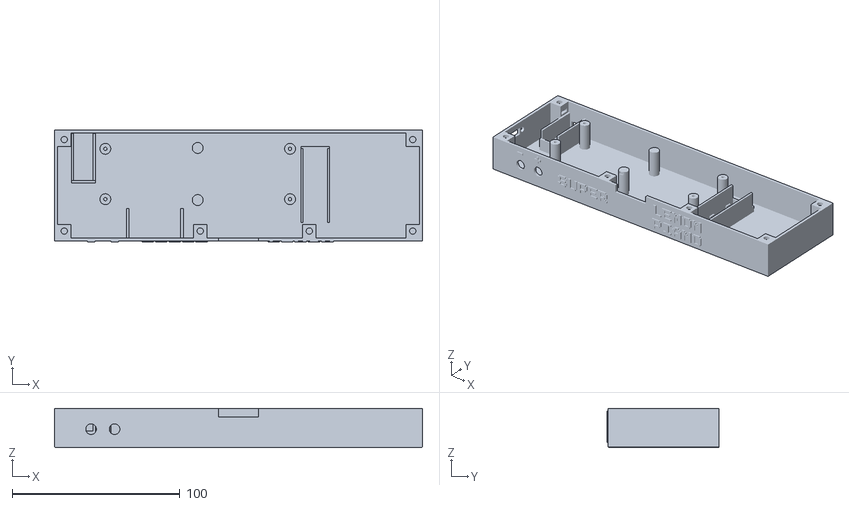
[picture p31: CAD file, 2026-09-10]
versions/v5.5-power-filter/model-design/enclosure-v6/base.stl
219.2 x 66.9 x 23.4

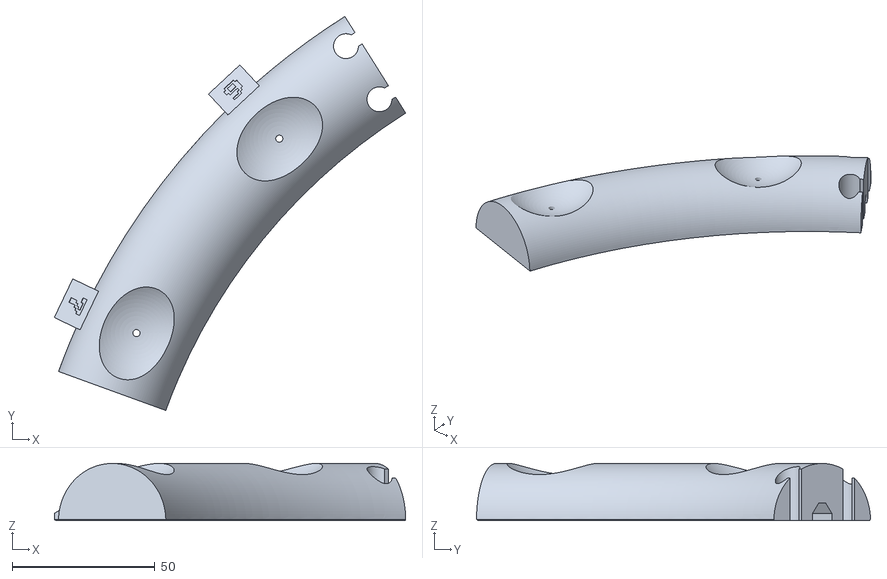
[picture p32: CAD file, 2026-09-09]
versions/v5.5-power-filter/model-design/fruit-arc-v5/este.stl
123.1 x 138.0 x 20.0

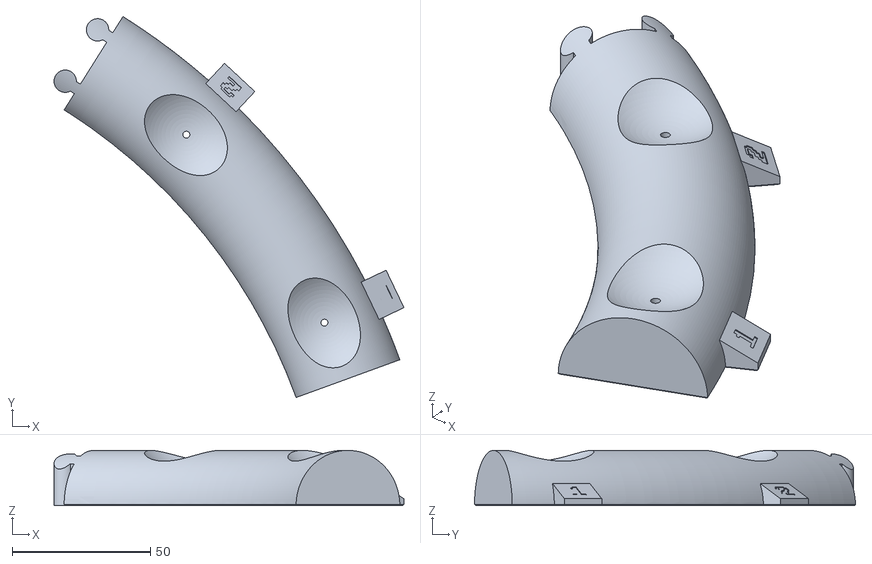
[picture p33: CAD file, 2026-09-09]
versions/v5.5-power-filter/model-design/fruit-arc-v5/oeste.stl
126.8 x 138.0 x 20.0

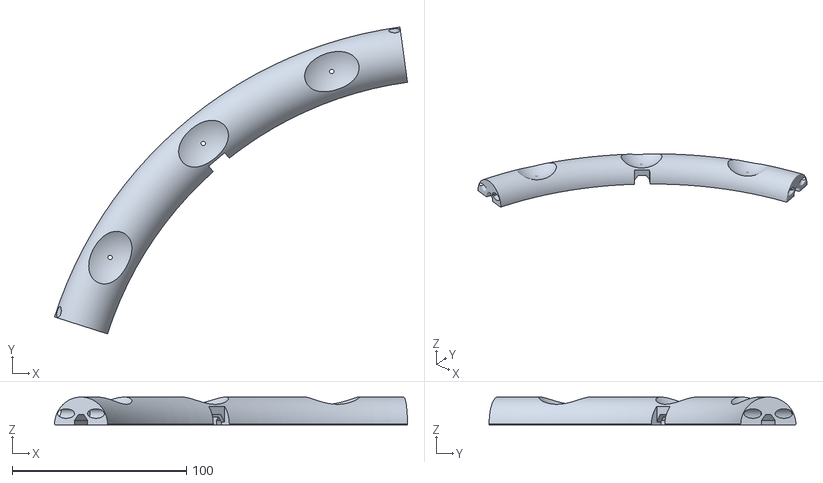
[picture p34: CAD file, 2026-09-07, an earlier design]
versions/v5.5-power-filter/model-design/enclosure-v2/centro.stl
202.6 x 176.1 x 16.0

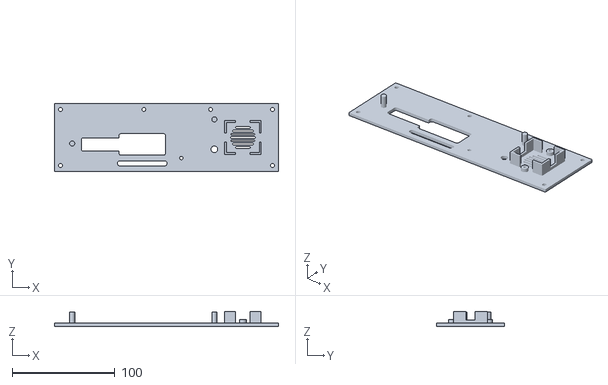
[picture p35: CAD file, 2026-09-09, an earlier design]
versions/v5.5-power-filter/model-design/enclosure-v4/tapa.stl
217.7 x 66.1 x 14.6

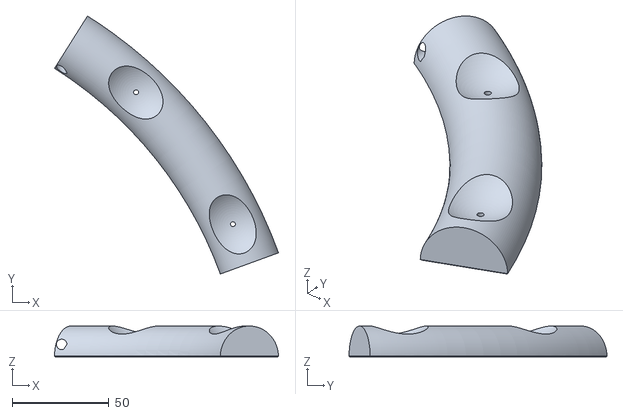
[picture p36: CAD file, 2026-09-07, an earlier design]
versions/v5.5-power-filter/model-design/enclosure-v2/oeste.stl
115.7 x 133.3 x 16.0

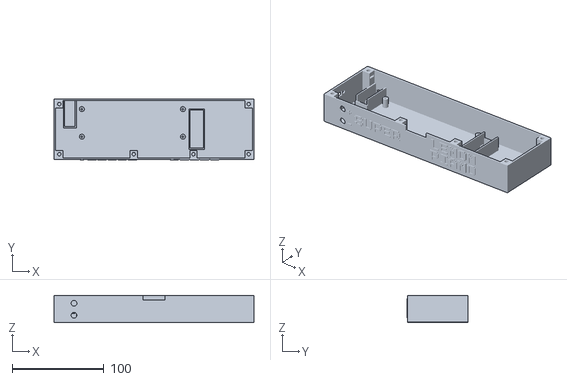
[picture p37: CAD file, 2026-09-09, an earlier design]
versions/v5.5-power-filter/model-design/enclosure-v4/base.stl
217.7 x 66.9 x 29.6

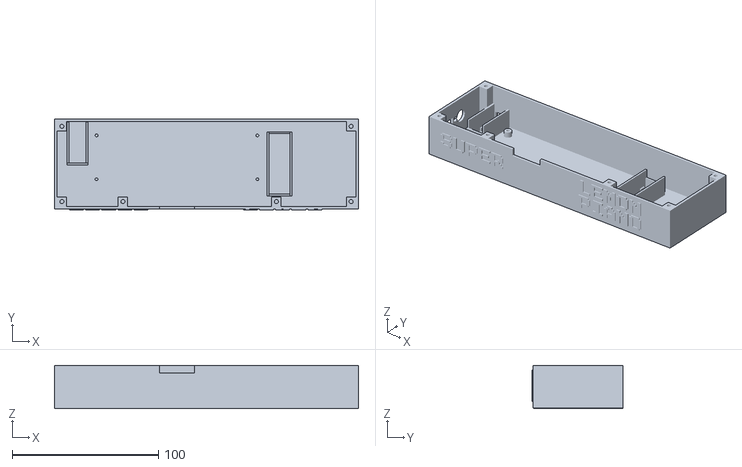
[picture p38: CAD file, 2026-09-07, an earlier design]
versions/v5.5-power-filter/model-design/enclosure-v2/base.stl
208.0 x 62.4 x 29.6

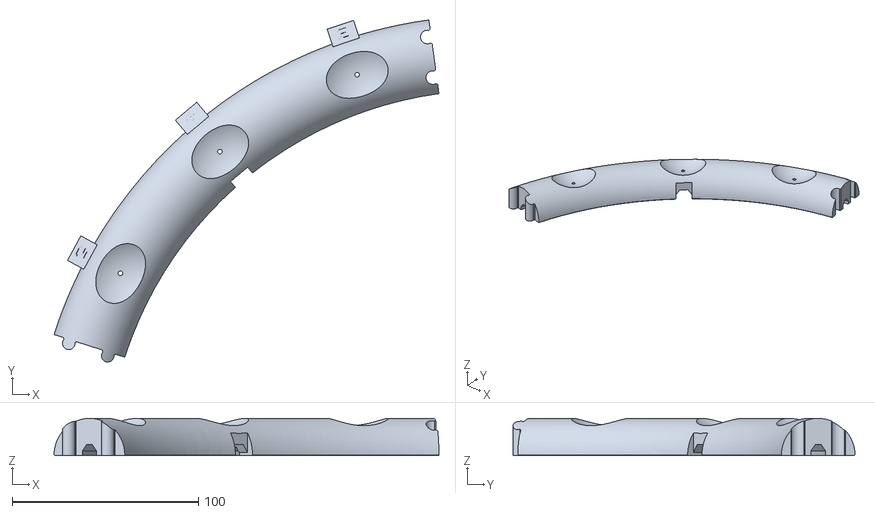
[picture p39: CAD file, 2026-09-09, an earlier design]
versions/v5.5-power-filter/model-design/fruit-arc-v4/centro.stl
207.0 x 183.9 x 20.0

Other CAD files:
versions/v5.5-power-filter/model-design/enclosure-v5/base.stl
versions/v5.5-power-filter/model-design/fruit-arc-v4/este.stl
pcb/3d/lemon-piano-v0.7.0.step
versions/v5.5-power-filter/model-design/enclosure-v5/tapa.stl
versions/v5.5-power-filter/model-design/fruit-arc-v4/oeste.stl
versions/v5.5-power-filter/model-design/enclosure-v2/este.stl
versions/v5.5-power-filter/model-design/enclosure-v2/espiga.stl
versions/v5.5-power-filter/model-design/enclosure-v2/tapa.stl

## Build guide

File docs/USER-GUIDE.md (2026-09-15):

# 🍋 Lemon Piano — how to play

*The instruction sheet. Written to be printed and left next to the piano, so it
explains the box in front of you and assumes nothing about the code inside it.*

Applies to the **V5.5** board (the one in the printed enclosure) with the
2026-09-09 firmware. Spanish translation: [GUIA-DE-USO.es.md](GUIA-DE-USO.es.md).

---

## 1. Set it up

1. Push one nail into each of the seven lemons and clip a wire to each nail,
   left to right — that is key **1** to key **7**.
2. Plug the eighth wire — the loose one — into the **clip**, and **hold the clip
   in one hand**. This is not optional: you are half the circuit. Nothing works
   until someone is holding it.
3. Power it from a **USB wall charger**, not from a laptop. A computer's ground
   noise walks straight past the filter and the piano starts playing by itself.
4. Touch a lemon with your other hand. It sings.

> **If nothing happens, or if it plays without being touched**, jump to
> §6 *Tuning*. Fruit changes as it dries out; the piano expects to be re-tuned.

## 2. Switching on

The bar of ten lights fills up on its own for a couple of seconds and you hear
a coin for each lemon. That is **calibration**: it is measuring what "not being
touched" looks like for each lemon.

**Keep your hands off the fruit while the lights are running.** If you are
holding a lemon during those two seconds, it learns that as normal and that key
goes deaf.

A little fanfare, and then it plays a short tune — that is the piano telling you
**which mode it woke up in**. It always wakes up in **Level 1**.

## 3. The game

Each level hides a **secret ten-note melody**. Your job is to find it by ear.

- Touch lemons freely: nothing bad happens and the bar stays empty.
- The moment you hit the **first note of the secret melody**, light 1 comes on.
  You are in.
- Every further correct note lights the next light. **1 → 10.**
- A wrong note **blanks the whole bar** and you start the melody again. You will
  hear the note you played first, then the "wrong" rattle — so you always know
  which lemon was the mistake.
- Light all ten and the level's own theme plays, with the lights counting up to
  it, then the flagpole fanfare — and the **next level starts by itself**.
- Clear level 4 and the finale plays on a loop until you stop it (see §5).

**Playing the same lemon twice in a row is not a mistake — it just does not
count.** The note sounds exactly as it should; the game simply is not listening
for it, because it is already waiting for a *different* lemon.

You can see that it did not count: **the whole bar lights up** while you are
holding that lemon, and the moment you let go your score comes back exactly as
it was. Ten lit lights are never a score — ten is a win, and a win does not
leave you holding a lemon. Nothing is lost, nothing is deducted, and there is no
telling-off noise — that rattle is gone (2026-09-13).
Compare it with a wrong note, which **blanks the bar and leaves it blank**: the
two can never be confused.

## 4. Free play — the piano with no game

Free play is not a level and you cannot reach it by winning. **Hold the + button
for three seconds** and the piano swaps the game for the instrument. Hold it
again and the game comes back, at the level you left.

In free play the seven lemons are simply the notes you were taught at school:

| Lemon | 1 | 2 | 3 | 4 | 5 | 6 | 7 |
|---|---|---|---|---|---|---|---|
| Note | **do** | **re** | **mi** | **fa** | **sol** | **la** | **si** |
| | C5 | D5 | E5 | F5 | G5 | A5 | B5 |

- No secret melody, no wrong notes, nothing to win.
- **Play the same lemon as many times as you like** — the game's one-touch rule
  is off here, because that rule is the opposite of what an instrument needs.
- **Hold a lemon and the note holds with it — one note, not a stutter.** Let go
  properly and touch it again for a second note. Playing fast still works; it
  only ignores the flicker of a finger that never left.
- **Every note breaks a wave.** Touch a lemon and a wave of light runs out from
  that lemon's own place on the bar: lemon 1 sends it left to right, lemon 7
  sends it right to left, and a lemon in the middle opens it both ways at once.
- And that is **all** the lights do here: the wave passes and the bar goes dark
  again. Nothing stays lit while you hold a note.
- **Two lemons at once sound as two notes.** Hold a second lemon along with the
  first and you get the interval, with the bar showing two separate lights, one
  for each note. Let either one go and the other keeps sounding. It takes two
  deliberate touches — a finger resting near a neighbouring lemon will not do
  it, on purpose.
- When you are not playing, the bar is **dark**. Every light you see was put
  there by your own finger.
- Going into free play is announced by the bar itself: two lights run in from
  the ends, meet, open out until the whole bar is lit, and then go out — and
  then the piano plays you the scale.

### Forgotten how the tune went? Ask for it again

**Press the same lemon five times in a row** and the level plays you its theme
again — the same one it opened with. The melody is where the secret code is
hidden, so this is the hint button.

**The note you just played counts as the first one**, so in practice it is four
more taps on the lemon already under your finger. Press, let go, press again;
don't dawdle, because leaving more than a second and a half between two taps
starts the count over.

It does not disturb the game: the lights come back exactly as they were and you
carry on from where you were. And there is a free way to do it — **drum the
lemon the game has just accepted.** Playing the same lemon twice never counts
for anything, so done that way the hint costs you nothing at all.

Not available in free play, on purpose: playing one lemon over and over is what
free play is *for*.

## 5. Choosing a mode

Everything below uses only the two buttons: **+** and **−**. The rule that makes
them easy to remember: **a tap is the sensitivity, a hold is a mode.**

### The instrument switch — hold **+**

**Hold the + button for three seconds.** From one second the bar fills and a
chirp climbs, exactly like the wheel below, so you can always tell it is
charging. At three seconds the piano swaps:

- playing a level → **free play**, announced by a run up do-re-mi-fa-sol-la-si
- in free play → **back to the level you left**, announced by its own theme

Let go early and nothing happens. It is a switch, so the same gesture takes you
both ways; you never have to go looking for a menu to get your instrument back.

### The level wheel — hold **−**

**Hold the − button down and keep holding.** After one second the piano starts
charging: the bar fills up and you hear a chirp that climbs. At **three seconds**
the lights sweep once across and back, a rising three-note cue plays, and you
are in.

Let go before three seconds and nothing happens — you get a low double bump
meaning "cancelled". *(The press itself turns the sensitivity down one step, as
any − press would; the moment the hold becomes a mode change that step is put
straight back.)*

### Turn it

**Tap +** for the next level, **tap −** for the previous one. It is a wheel: past
level 4 you come back to level 1. Free play is **not** on the wheel — it is the
+ hold above, so turning the wheel can never take your instrument away.

Each stop tells you where you are, twice over:

| Mode | Lights | Sound |
|---|---|---|
| Level 1 | **1** light, blinking | the Overworld theme |
| Level 2 | **2** lights, blinking | the Underworld theme |
| Level 3 | **3** lights, blinking | the Starman theme |
| Level 4 | **4** lights, blinking | the Castle theme |

Blinking lights mean *a question*; steady lights mean *a score*.

Tap again while a tune is playing and it stops immediately and moves on — you
never have to wait for the music.

### Choose it

**Press both buttons at once.** Order and timing do not matter: press one, then
the other whenever you like. A short confirmation plays and the mode starts.

Choosing a **level** starts it from scratch, with an empty bar. Choosing **free
play** hands you the instrument.

### Leave without choosing

Three ways, all of which change nothing:

- **Hold either button for three seconds** — the opening cue plays backwards.
- **Walk away.** After twenty seconds with no button, it closes itself.
- **Choose the mode you were already in** — it opens on the mode you are
  playing, so opening and immediately accepting does nothing at all.

The game is exactly where you left it: same level, same lights, same progress.

## 6. Tuning — when the fruit stops behaving

The piano reads a touch as a **drop of three or four counts** out of 1024. That
is a tiny signal, and it changes with the fruit, the room and your hands.

| Symptom | Do this |
|---|---|
| Lemons do not respond | Tap **+** a few times (more sensitive) |
| It plays notes on its own | Tap **−** a few times (less sensitive) |
| Neither helps | **Smart adjust**, below |
| Nothing at all works | Are you holding the clip? Is it plugged into a wall charger? |

Each tap moves it one step and the bar shows you where the setting sits; the
chirp's pitch rises as it gets more sensitive, so you can tune it without
looking. Hold a button to run through the steps quickly.

**Smart adjust** — the good one. **Touch a lemon and keep touching it**, then
hold **both buttons for one second**. The bar fills as it listens, and it works
out the best setting from your actual finger on your actual fruit.

- A rising triad (**1-up**) = it learned something. You are done.
- A falling rattle = it could not tell your touch from the noise, and **nothing
  changed**. Check the clip is in your hand and try again.

> **The three long presses, and how to keep them apart.** *Both* buttons for one
> second = tune. *Just* **+** for three seconds = the instrument switch. *Just*
> **−** for three seconds = the level wheel. They cannot collide: if you reach
> for the second button mid-charge, the charge cancels and hands over to tuning.

To start completely fresh, **unplug it and plug it back in**. That re-runs
calibration and returns to level 1.

## 7. Every gesture, on one line each

| Gesture | What it does |
|---|---|
| Tap **+** | More sensitive, one step — **one more light** |
| Tap **−** | Less sensitive, one step — **one light out** |
| Hold **+** for **3 s** | **Free play ⇄ the level** |
| Hold **−** for **3 s** | **Opens the level wheel** |
| In the wheel: tap **+** / **−** | Next / previous level (it wraps) |
| In the wheel: **both buttons** | Choose this mode |
| In the wheel: hold either **3 s** | Leave, change nothing |
| Hold **both** for **1 s**, touching a lemon | Smart adjust |
| Hold **both** for **1 s** during the finale | Back to level 1 |
| Unplug and plug back in | Full reset, re-calibrates |

## 8. Sounds, and what they mean

Every non-musical sound is a Super Mario Bros effect, pitched **above** the
lemons so it can never be mistaken for a note.

| Sound | Meaning |
|---|---|
| Coin, one per lemon | Calibrating — hands off |
| Mushroom power-up | Calibration finished, go ahead |
| Rising chirps, climbing | A button is charging: **+** the instrument switch, **−** the level wheel |
| Rising three notes | The wheel is open |
| The same three, falling | The wheel closed, nothing changed |
| Fifth resolving to the octave | You chose a mode |
| Low double bump | End of the range, or a cancelled charge |
| Short death rattle | Wrong note |
| 1-up | Smart adjust learned something |
| Full death tune | Smart adjust could not; nothing changed |
| Flagpole fanfare | Level cleared |

---

*Secret codes, note tables and the reasoning behind every timing above:
[../versions/v5.5-power-filter/README.md](../versions/v5.5-power-filter/README.md).*

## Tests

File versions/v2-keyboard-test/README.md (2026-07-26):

# V2 — keyboard test rig (2019)

The instrument reduced to the part that mattered: **just the keyboard and the
speaker**. This is the board used to find out what the fruit keys actually read,
right before the game logic arrived in V3.

**Hardware delta vs [V1](../v1-banana-piano/):** the HC-SR04 ultrasonic module
comes **off** the rig (D11/D12 free again). Nothing else changes — same 7 keys,
same 220 Ω pull-ups, same speaker on D8.

<div align="center">
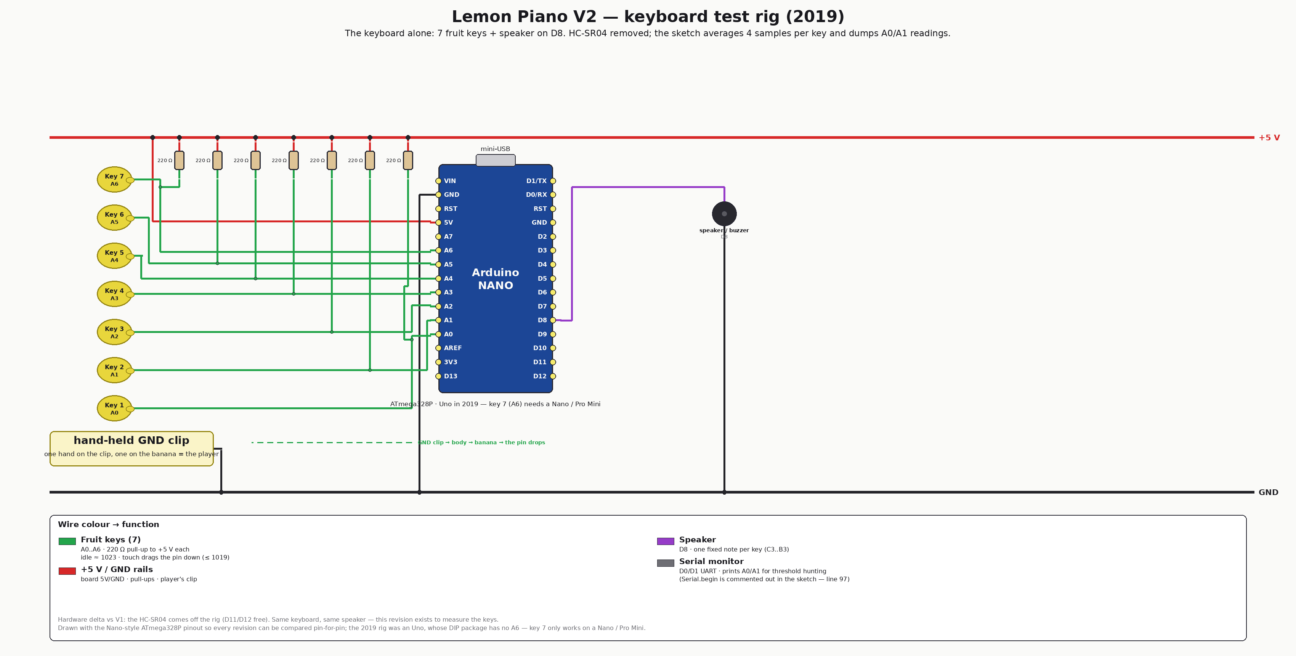
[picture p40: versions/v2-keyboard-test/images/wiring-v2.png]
V2 wiring diagram

</div>

## How it plays

Same as V1 — hold the GND clip, touch a fruit, hear its note — with two firmware
differences that betray what the board was *for*:

- **4-sample averaging** per key (`(analogRead(n)×4)/4`) instead of V1's 2, to
  fight mains noise. Key 7 still uses 2 samples (a leftover).
- **Serial dumps** of A0 and A1, four readings each per loop, so you can watch
  the idle level and pick a threshold.

| Key | 1 | 2 | 3 | 4 | 5 | 6 | 7 |
|---|---|---|---|---|---|---|---|
| Pin | A0 | A1 | A2 | A3 | A4 | A5 | A6 |
| Note | C3 | D3 | E3 | F3 | G3 | A3 | B3 |

> **Quirk worth knowing:** `Serial.begin(9600)` is commented out (line 97) while
> the `Serial.print` calls are live — as shipped, the readings go nowhere.
> Uncomment that line before using the monitor. Left as-is on purpose: this is
> the 2019 sketch, and the fix belongs to whoever revives the rig.

## Firmware

```bash
cd firmware
pio run                 # nanoatmega328 (default) — the env with a working key 7
pio run -e uno          # the historical board; A6 (key 7) does not exist on it
pio run -t upload
pio device monitor       # 9600 baud — after uncommenting Serial.begin
```

## Emulation

None — same reason as V1 (buzzer pin, key 7 on A6, and the divider), see
[emulation/README.md](emulation/README.md).

## Files

| Path | What |
|---|---|
| [firmware/keyboard-test/keyboard-test.ino](firmware/keyboard-test/keyboard-test.ino) | the sketch (note table inlined) |
| [HARDWARE.md](HARDWARE.md) | pin map, BOM, wiring detail |
| [images/wiring-v2.png](images/wiring-v2.png) | wirewright-rendered wiring |

**Next revision:** [V3 — game prototype](../v3-game-prototype/) adds the two
feedback LEDs, a game-select button and the first relay.

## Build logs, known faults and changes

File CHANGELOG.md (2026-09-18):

# Changelog

Append-only log of significant changes. Newest first.

<!-- ARCHIVE-DIGEST START -->
**Archived history**

50 older entries live in `docs/changelog/`, moved there verbatim. Run
`bin/qpc-changelog-archive <repo> --verify` to prove none of them changed.

[undated](docs/changelog/undated.md), 6 entries:

- theme, VU-meter colours in the emulator
- a more recognisable Castle theme
- the ending loops until reset
- themes, a real castle-clear ending
- not a mistake
- driving the browser, not by guessing

[2026-07](docs/changelog/2026-07.md), 44 entries:

- 2026-07-31 (pcb/) — rotatable 3D models in the pipeline
- 2026-07-31 (pcb/) — v0.6.0: J5, aux speaker output in parallel with the buzzer
- 2026-07-30 (pcb/) — v0.5.1: D1's missing 3D body (Kathode/Cathode filename split)
- 2026-07-30 (pcb/) — v0.5.0: Nano flipped (USB east), keys north, LEDs south, filter refactored
- 2026-07-30 (pcb/) — v0.4.0: 120 × 40 mm remake, centred Nano, external-button headers
- 2026-07-30 (pcb/) — v0.3.0: 4 anchor holes, VU-meter LEDs, render fixes
- 2026-07-30 (pcb/) — v0.2.1: silk label pass + render naming
- 2026-07-30 (pcb/) — v0.2.0: Nano-orientation erratum fixed + full render suite
- 2026-07-30 (pcb/) — Fabricable V5.5 PCB, release v0.1.0
- 2026-07-29 (V5.5) — New version: filtered 5 V supply
- 2026-07-29 (V5 LEDs) — Progressive 10-LED fill for calibration and the win
- 2026-07-29 (V5 audio, part 4) — Faster autoplayer, Castle closes the game,
- 2026-07-29 (V5 audio, fix) — The ending loop actually loops in the emulator now
- 2026-07-29 (V5 audio, part 3) — Stuck-key cue, Castle replaces Underwater,
- 2026-07-29 (V5 audio, part 2) — Level-start announce, full Underwater/Starman
- 2026-07-29 (V5 audio) — Mistake cue is now Mario's death rattle; win order fixed
- 2026-07-29 (V5 autoplayer, v5) — Manual clicks came back dead; a real short,
- 2026-07-29 (V5 emulation) — A "virtual button" that plays every level for you
- 2026-07-29 (V5 autoplayer, v2-v4) — Three real bugs, found by actually
- 2026-07-29 (V5 audio timing) — Fixed the sound race; silences are now policy
- 2026-07-29 (V5) — Four levels, and every sound is Mario's
- 2026-07-28 (V5.5) — Drawn proposal: sensitivity on a KY-040 rotary encoder
- 2026-07-28 (V5 rebuilt) — GND-clip keyboard, live sensitivity, no restart/select
- 2026-07-27 (V2.5) — New version: keyboard test with a LIVE touch threshold
- 2026-07-27 (V5 input) — One key at a time; and the measurement that says the pull-downs are mandatory
- 2026-07-27 (V5 touch) — Notes sustain while held; a key only ever counts once
- 2026-07-27 (V5) — Piano first, puzzle second: free play + a wrong tone that waits its turn
- 2026-07-26 (V0 field result) — The bad "buzzer" was a bad Arduino
- 2026-07-26 (V0) — New buzzer bring-up board: a scale, forever
- 2026-07-26 (V4.5) — V4+ renamed to V4.5, and its relay pair + water pump removed
- 2026-07-26 (restructure) — One version per hardware revision, none archived
- 2026-07-26 — Wiring engine extracted to its own repo (eda-wirewright)
- 2026-07-25 (engine) — Real schematic engine: auto-router + DRC (no more overlaps)
- 2026-07-25 (diagrams) — Fix overlapping wires in the wiring diagrams
- 2026-07-25 — V4 touch upgrade (in-place) + manual MARGIN buttons + wiring diagrams
- 2026-07-14 (calibration) — Noise-adaptive touch margin, recalibrate on RESTART
- 2026-07-14 (light show) — LED bar flashes to the victory theme
- 2026-07-14 — V5: ten-LED progress bar, auto-advancing games
- 2026-07-13 (routing) — Hard wire-routing rules in the pipeline
- 2026-07-13 (final) — Emulation polish: keyboard play, switch, clean wiring
- 2026-07-13 (later) — Emulation fixes: dead keys, endless beep, layout
- 2026-07-13 — Interactive browser emulation (Velxio)
- 2026-07-12 — Firmware fixes & refactor (TODO #1–#12)
- 2026-07-12 — Rescue & workspace setup

<!-- ARCHIVE-DIGEST END -->

---

<!-- ARCHIVE-DIGEST START -->
**Archived history**

18 older entries live in `docs/changelog/`, moved there verbatim. Run
`bin/qpc-changelog-archive <repo> --verify` to prove none of them changed.

[2026-09](docs/changelog/2026-09.md), 17 entries:

- 2026-09-13 — the SENS − button played a note: A7 is on the key multiplexer
- 2026-09-13 — quiet-rest control: 1 MΩ does not ghost, and the game is loaded
- 2026-09-13 — SOLVED: R1 at 1 MΩ, 15 clean presses, no ground clip
- 2026-09-13 (night) — `readKey()` discards its first conversion, with a test that proves it
- 2026-09-13 (late) — R1 → 10 kΩ, twice: a floating node, then the real number
- 2026-09-13 (night) — a log that cannot say what it measured is not evidence
- 2026-09-13 (evening) — the breadboard, measured: it works by two counts
- 2026-09-13 (later) — the board is good, and a wire proved it in thirty seconds
- 2026-09-13 — the probe records to a file at last, and the board's answer
- 2026-09-12 (fix) — the probe flashed fine and printed to nobody
- 2026-09-12 (later) — the bench answers back: the probe learns to look both ways
- 2026-09-12 — V5.5 wiring diagram: every part labelled with its PCB v0.7.1 reference designator
- 2026-09-12 — v0.7.1 assembled and silent: review, board probe, doc correction
- 2026-09-09 — V5.5 firmware: FREE PLAY and the MODE WHEEL (no hardware change)
- 2026-09-06 — PCB v0.7.1: "Created with ♥ by Multitec." maker's mark (cosmetic)
- 2026-09-06 — PCB v0.7.0: Nano turned back to USB-WEST for enclosure cable access (LEDs north, keys south)
- 2026-09-06 — V5.5: add the amplified speaker that was missing from the diagram

[2026-08](docs/changelog/2026-08.md), 1 entries:

- 2026-08-05 — V6 proposal: battery power + amplified speaker (diagram only)

<!-- ARCHIVE-DIGEST END -->

---

## 2026-09-15 (late, take two) — every theme at three sizes

*"Creo que no me he expresado bien. Hay tres versiones de cada canción. La
corta, que es para el menú. Una de siete notas y únicamente de las siete notas
que se tocan. Así es como tiene que ser la canción cuando empieza o cuando el
usuario toca cinco veces la nota. Y luego la versión ultra completa, full, que
es ya cuando el nivel es completado y como celebración."*

The entry above this one made the level announcement the **whole** theme. That
was half of what he meant and the wrong half: a 23-second Castle at the start of
every level is not an announcement, it is a wait. Corrected here — and the
result is better than either version, because the three sizes each have a job.

| Size | Where | What it is |
|---|---|---|
| **SHORT** | the mode wheel | the first `MENU_PREVIEW_NOTES` (8) entries of the raw theme. Browsing four modes has to be fast above everything else. Unchanged |
| **PLAYABLE** | the level announcement, and the five-tap reminder | **seven notes, and only notes this level's lemons can make** |
| **FULL** | the celebration when a level is cleared | the whole piece, 10–23 s |

### The PLAYABLE cut is the interesting one

The announcement **is the clue** — the ten-note code is hidden in the theme — so
it must not be full of notes the keyboard cannot make. Every theme reaches
pitches that are on no lemon: the Overworld goes to AS6, F7 and D7, none of
which is one of level 1's seven keys.

So `playPlayableIntro()` walks the theme and plays only what the level's row
contains, stopping at seven notes. A pitch outside the row is **not skipped** —
it is played as silence of the same length, so the rhythm of the hook survives,
which is most of what makes a hook recognisable. It is a rule rather than four
hand-written excerpts, it costs no flash (the note data is the theme that is
already there), and it lands on each theme's actual hook, which is a pleasant
accident of Mario having written them that way:

| Level | Theme | The seven notes it announces | Time |
|---|---|---|---|
| 1 | Overworld | `E7 E7 E7 C7 E7 G7 G6` — the riff, exactly | 2.0 s |
| 2 | Underworld | `C4 C5 A3 A4 AS3 AS4 C4` | 2.0 s |
| 3 | Starman | `C6 F5 F5 D5 F5 F5 D5` | 1.4 s |
| 4 | Castle | `G3 D4 G3 D4 AS3 D4 AS3` — the alternating pedal | 2.0 s |

### …which freed the celebration to be the whole piece

A win used to play the theme's **tail**, from `*_VICTORY_FROM`, for a reason
that has now evaporated: the level announcement was already playing its head,
and hearing the whole thing twice in a row would have been too much. The
announcement is seven notes now, so `playVictory()` plays from the top —
Overworld 12.2 s, Underworld 13.1 s, Starman 10.4 s, Castle 22.7 s, with the bar
counting up from empty to all ten across the whole thing. The four
`*_VICTORY_FROM` constants are gone with it.

### Evidence

- **All five envs build.** 17 998 B flash / 58.6 %, 558 B RAM / 27.2 %.
- **Host tests: 107 + 174 checks, 0 failed.** New test 26 pins all three sizes,
  and it can see *which* notes the announcement played because
  `playPlayableIntro()` now prints them (`theme: 2637 2637 …`) — a theme is
  bit-banged through `buzz()` rather than `tone()`, so a log line is the only
  window onto it. The test asserts seven notes on every level, **every one of
  them on that level's keyboard**, and that the celebration is many times longer
  than the clue.
- **Flashed and verified**, and confirmed from the board's own serial:

```
  5.4s  Level 1
  7.6s  theme: 2637 2637 2637 2093 2637 3136 1568
```

  That is E7 E7 E7 C7 E7 G7 G6 — seven notes, 2.2 s from the level being
  announced to the tune being over, every note playable on a lemon.

## 2026-09-15 (late) — a level announces itself with its WHOLE theme

*"Tienes que hacer que suene completa la melodía. No solo las primeras notas.
En cambio, cuando estamos usando el menú de selección de nivel, sigue teniendo
que tocar la versión reducida para que no se haga tan largo."*

The reason is the game itself: **the ten-note code is hidden in the theme**, and
the codes draw on the whole piece rather than its opening bar. An announcement
that stopped after twelve notes was showing the player a twelfth of the clue —
and the five-tap reminder, which calls the same function, was handing out that
same twelfth when someone asked to hear it again.

`playLevelIntro()` now plays `*_LEN` instead of `*_INTRO_LEN`. Both callers get
it: the level start (boot, a win, accepting from the wheel, coming back from
free play) and the five-tap reminder. Free play is unchanged — its announcement
was always the whole scale.

**What it costs, measured rather than guessed** (playSong's own pacing: a note,
then 1.3× its length as a gap):

| Level | Theme | Notes | Was | Now |
|---|---|---|---|---|
| 1 | Overworld | 78 | 1.8 s | **12.2 s** |
| 2 | Underworld | 56 | 1.8 s | **13.1 s** |
| 3 | Starman | 48 | 2.1 s | **10.4 s** |
| 4 | Castle | 72 | 4.9 s | **22.7 s** |

So a win now costs the victory tail, the flagpole fanfare and then up to 23
seconds of the next level's theme. That is the trade he asked for, and it is
worth having written down next to the numbers.

**The wheel did not change.** Browsing modes still previews at most
`MENU_PREVIEW_NOTES` (8) notes, because a wheel you turn five times cannot spend
two minutes on it — which is exactly the second half of what he asked for. The
four `*_INTRO_LEN` constants now exist for that one caller and nothing else,
and say so.

### Evidence

- **All five envs build.** Unchanged at 17 806 B flash / 58.0 %, 562 B RAM /
  27.4 % — the lengths were already constants, so this costs nothing.
- **Host tests: 107 + 162 checks, 0 failed.** Test 25's edge-for-edge assertion
  is what covers this without a single change: it compares the five-tap replay
  against the boot announcement through `pinWrites[BUZZER]`, so "the reminder
  plays what the level opened with" stays true whichever length that is.
- **Flashed and verified**: `/dev/ttyUSB0`, 17 806 bytes written and verified.
  Boot log timed over serial: banner at 1.5 s, seven baselines by 5.1 s, margin
  30, `Level 1` at 5.4 s — and then twelve seconds of Overworld.

## 2026-09-15 (later) — the bank says `ICP`, and the fault flipped from too little current to too much

Natalia took the trigger to the bench and came back with two facts that move the
diagnosis further than any amount of reasoning about it would have:

1. **The trigger alone keeps the UGREEN Nexode's output up.** A few mA, far
   under any low-load threshold, and it does not drop. That closes the open
   question from this morning's doc — the decoy really does hold the port open at
   5 V — and it **removes the low-load timeout from the list of suspects
   entirely**. The bleeder resistor may never be needed.
2. **Attach the PCB and the bank shows `ICP` and cuts.** A code on the screen is
   a *protection trip*, and a trip means too much current, not too little. The
   fault we were chasing has inverted.

So the doc grew the branch that actually matters now, and it leads with the
cheapest cause: **reversed polarity**. `D1`'s cathode is on `/VIN` and its anode
on `/GND` (`pcb/docs/NETLIST.md` nets 2 and 3), so a swapped pigtail forward-biases
the TVS into a 0.7 V diode straight across the bank — a short, instantaneous and
repeatable, which is exactly the shape of the symptom. `D2` keeps it away from
the Nano, so the board fails safe and the bank's code is the alarm. Three
unpowered checks (which screw is `+`, a frayed strand across the terminal, Ω
across `J1` — *with the warning that the reversed-probe reading is `D1` conducting
and not a fault*), then a diode test on `D1` itself before trusting it again.

If polarity is clean it is the inrush into `C1 ‖ C3` = 940 µF, and the first
attempt costs nothing: **land the screw terminal before plugging the USB-C in**,
so the bank ramps VBUS into the capacitance on its own soft-start instead of
being hot-plugged onto a discharged 940 µF. Only then C1 470 → 220 µF.

`ICP` itself is left honest: UGREEN does not publish the expansion and searching
found only their generic "unusual code = protection mode" FAQ. The doc reads it
as a current protection and says it is not verified, because the actionable half
— trip, not timeout — does not depend on the acronym.

## 2026-09-15 (late) — the power bank switches itself off, and the PD trigger is only half the answer

Natalia asked for the DIP code that gets 5 V out of the PD/QC trigger module in
the inventory (`mod-pd-trigger-dip100w`), so the V5.5 board can run off a power
bank instead of a charger — the bank keeps cutting out because the piano does
not draw enough.

**The code is `1=OFF, 2=OFF, 3=OFF`.** Full table (1=ON, 0=OFF): `000`→5 V,
`111`→9 V, `110`→12 V, `100`→15 V, `101`→20 V. The module never steps up, so a
wrong code fails safe downwards to 5 V.

But the premise deserved a second look, and the new
[docs/POWER-FROM-A-POWER-BANK.md](docs/POWER-FROM-A-POWER-BANK.md) says so in
full:

- **A trigger set to 5 V does not raise the current draw**, and the draw is what
  the bank is measuring. The shutdown is a low-load timeout, not a voltage
  problem.
- **5 V is the one setting where a decoy may do nothing at all** — a USB-C
  source offers 5 V by default, so the board may take vSafe5V without ever
  sending an explicit Request, leaving the bank exactly as unaware of the piano
  as a bare two-wire pigtail does. Not documented by the seller, not verified
  here, and the KWS-X1's protocol page answers it in one look.
- **Three different faults look the same from the couch** and want different
  fixes: the low-load timeout (raise the draw), inrush into the 940 µF of
  `C1 ‖ C3` (drop C1 to 220 µF), and no PD contract at all (needs a C-to-C
  path). Which one it is follows from *when* the output drops.
- **`D1` makes a wrong DIP code expensive.** The P6KE6.8A is a 600 W part for
  1 ms, not a shunt: a 9 V contract from a 100 W bank puts it into continuous
  avalanche, and the ATmega inherits the 9 V when it fails. Hence the rule the
  doc leads with — measure the screw terminal with the Fluke *before* the wires
  reach `J1`.
- **The keep-alive, if it is still needed**, is a plain resistor across the
  trigger's screw terminal: 150 Ω (33 mA) to start, 2 × 220 Ω in parallel
  (45 mA) if the meter says so, never a single 100 Ω on a ¼ W part. On the
  unfiltered side, so it adds no drop across `L1` and cannot move AVcc. The
  bank's own low-current mode is tried first — it costs nothing.

Nothing on the board changes, so this is not a new version: it is a document,
linked from V5.5's powering rules and from V6's open-risk table. The current
figures in it are computed from the schematic, not measured — the measurement
protocol is step 1 of the doc, and it is what turns the table honest.

## 2026-09-15 (night) — "play me that tune again" moves off two lemons and onto one

*"Creo que es físicamente imposible detectar correctamente la pulsación de
varias teclas a la vez. Por lo cual vamos a cambiar el paradigma."*

The theme reminder shipped an hour ago as **hold the two END lemons together for
two seconds**. It was a good gesture built on the one thing this keyboard cannot
do — the same shared return path that makes the chord hard (every lemon's
current goes home through the player's body and the GND clip, so two fingers are
in each other's way and each dips shallower than one). Sergio called it, and he
is right: a gesture must not be built on the input the hardware is worst at.

**So it is built out of the input this piano has read perfectly since 2019: one
lemon, pressed and released.** Five presses of the same lemon in a row and the
level plays its theme again. Nothing simultaneous, nothing to disambiguate, no
threshold that is not already load-bearing.

### How it behaves

- **The note you just played is press one.** In practice it is four more taps on
  the lemon already under your finger — which is what he described: *"pulsa
  cuatro veces cualquier nota… pulsa, suelta y pulsa de nuevo hasta cinco
  veces"*.
- **It changes nothing about the game**, which is the part he asked for in as
  many words (*"el juego continúa por donde estaba"*). Presses two to five are
  repeats, which already score nothing and cost nothing; the first is an
  ordinary press, because the player chose to touch a lemon. `playThemeReminder()`
  does not touch `currentStep`, and `restoreIdleDisplay()` puts the same count of
  LEDs back on the bar.
- **There is an obvious free move**: drum the lemon the game has *just accepted*.
  Then all five are repeats and the hint costs nothing at all. Deliberately not
  enforced — no snapshot, no undo, no rewinding a wrong note — because a gesture
  that gives you your progress back after a mistake is a gesture that trivialises
  the game. The rule is "asking changes nothing", not "asking un-does things".
- **The keys are dead while it plays**, because `playLevelIntro()` blocks
  (*"se desactivan las teclas temporalmente"*), and the lemon still under the
  finger has to be let go before it counts as anything again — capped at 4 s so
  a channel that never reads clear cannot hang the piano.
- **A pause resets the count.** More than `THEME_REPEAT_GAP_MS` (1.5 s) between
  two presses and it starts over, so drumming is a decision and a lemon poked
  twice a minute apart never adds up to a request.

**Game only, and that is not an omission.** Free play exists precisely so the
same lemon can be played over and over — the mode's whole point, and the one
rule the game has that an instrument must not. Counting repeats there would take
the mode away to give it a hint it has no use for. The test asserts it: eight
taps on one lemon in free play are eight notes and not one byte of a theme.

### What came back

**The widest chord.** With the gesture off the two end lemons, **lemon 1 +
lemon 7 is available again** in free play — the widest interval this keyboard
has, lost for about an hour.

And the code got smaller rather than bigger: `bothEndsDown()`,
`serviceThemeReminder()`, the `stepBeforePress`/`countedBeforePress` snapshot,
the arming meter's trip outside the buttons-only region, and two constants are
all gone, replaced by three variables and an eleven-line counter in the press
branch. **17 806 B** against the 18 050 B of the version it replaces.

### Evidence

- **All five envs build.** `nanoatmega328` 17 806 B flash / 58.0 %, 562 B RAM /
  27.4 %.
- **Host tests: 107 + 162 checks, 0 failed.** Test 25 rewritten around the new
  gesture, and it pins the awkward cases as well as the happy one: four taps are
  not five; a different lemon in the middle starts the run over and the fifth of
  the *new* run is what fires; a 2.5 s pause breaks it; free play counts nothing.
  The replay is still asserted **edge for edge** against the boot announcement
  via `FakeBoard::pinWrites[BUZZER]` — not "a tune played", *that* tune.
- **Flashed and verified**: `/dev/ttyUSB0`, 17 806 bytes written and verified;
  boots, calibrates (margin 34 on a noisy bench this time) and announces
  `Level 1`.

## 2026-09-15 (evening) — the wave is the whole display, and the theme can be asked for

Two more from Sergio, straight after playing the last build.

### 1. Free play's bar only ever MOVES now

*"Quita el estático. El estático de que cuando pulsas la tecla 1 se enciende el
primer LED y cuando tocas la 7 se encienden todos. Solo quiero que salga la
onda, el barrido… están solapados."*

The pitch meter and the wave were both drawing on the same ten LEDs, one after
the other, and they read as one confused thing: a wave that runs and then a
block of light that stays. The static half is gone. In free play the bar is now
**dark, a wave, dark again** — the wave is the only thing a played note ever
draws, and `playKeyWave()` ends with `allLedsOff()` so the pond is left as it
was found.

The two places a single note could still leave a standing light went with it:
when a chord narrows to one voice (either way round), the bar goes dark rather
than falling back to the pitch bar. `showPitchBar()` survives for exactly one
caller — the scale that announces the mode, where the bar climbing *is* the
animation.

Worth noting what is deliberately kept: the chord's **two lone LEDs**. That is
the one standing shape left in free play, and it is the one worth keeping still
— it is the only way to see that two notes are sounding.

### 2. Both END lemons, held two seconds, replay the level's theme

*"Si el usuario toca la tecla 1 y la tecla 7 a la vez durante 2 segundos, suene
de nuevo la musiquita de ese nivel. Para que el usuario pueda recordar cómo
era."*

The theme **is** the clue — the ten-note code is hidden in it — so a player who
half-remembers it had to reset the board or win the level to hear it again. Now
they can ask. Hold lemon 1 and lemon 7 together: the bar becomes a charge meter
with a rising chirp (the same language as the two button holds), and at two
seconds `playLevelIntro()` runs again. In free play that replays the mode's own
announcement, sweep and scale.

**The two ends, because they are the one pair nobody plays by accident** — as
far apart as this keyboard goes, and no melody here asks for both at once.

**And it must not cost anything to ask**, which is most of the work:

- It is checked **before the input layer turns a finger into a guess**
  (`serviceThemeReminder()` returns true and owns the loop), so when both land
  in the same scan neither lemon sounds and neither is scored.
- When the second lemon arrives *late*, the first has already been scored — so
  the gesture **undoes it**, putting `currentStep` and `lastCountedKey` back to
  what that press found. Only a press of lemon 1 or lemon 7 arms that snapshot;
  any other lemon sets it to −1, or a stale snapshot would roll the game
  backwards on the next arming. Same trick the buttons already use for the
  sensitivity knob (`marginBeforePlus`).
- Letting go early cancels with the same bump every other held gesture uses, and
  **leaves the undo in place**: touching both ends is never a move.

**It had to be made shadow-proof, and the host test said so before the fruit
could.** The first version asked "are both ends over `touchMargin`?" — which, on
a rig where one finger's shadow is bigger than the margin, is true *every time
anybody plays anything*. Ten existing tests went red at once: the piano stopped
on every note to offer the theme. The rest of the firmware survives such a rig
because `strongestKey()` only ever takes the deepest channel, so `bothEndsDown()`
now does the same sort of thing — the two ends must also be the **two deepest**,
judged by the same ratio the chord uses. A middle lemon dipping comparably means
a hand on the fruit, not this gesture.

**What it costs:** lemon 1 + lemon 7 is no longer available as a chord in free
play. It is the widest interval the keyboard has, and it is the price of putting
the gesture on the pair nobody hits by accident. Said out loud here and in the
version README rather than left to be discovered.

### The fake board learned to hear a bit-banged tune

Asserting "it replayed the level's own music" was impossible until now: themes
go through `playSong()` → `buzz()`, which **toggles the buzzer pin by hand**
rather than calling `tone()` (that is what the 2019 code did, and what the piezo
is wired for), so `board.tones` never saw a single note of one. `FakeBoard` now
counts raw writes per pin, and that turns out to be a sharper instrument than
expected: the buzzer's edge count straight after boot **is** one playing of the
level-1 intro, so the test asserts the reminder produced **the same number
again, edge for edge**. Not "a tune played" — *that* tune.

### Evidence

- **All five envs build.** `nanoatmega328` 18 050 B flash / 58.8 %, 567 B RAM /
  27.7 %.
- **Host tests: 107 + 161 checks, 0 failed**, up from 107 + 145. Test 7 rewritten
  (the free-play bar has no standing state at all now), test 25 added.
- **Flashed and verified**: `/dev/ttyUSB0`, 18 050 bytes written and verified;
  the board boots, calibrates (margin 18 on a quiet bench) and announces
  `Level 1`.
- **Still needs fingers on fruit**: whether two seconds is the right hold, and
  whether the chord comes now that gate 1 is fixed. Both are single constants,
  and `-DDEBUG_TOUCH` prints the dips for the second one.

## 2026-09-15 (later) — the levels play in their own key, and the light moves where it should

Four reports from Sergio after playing the morning's build, all in
`versions/v5.5-power-filter/firmware/`.

### 1. Level 4's lemons were in the wrong key — and so were level 3's and one of level 2's

*"En el nivel 4 suena la melodía, pero cuando yo toco las notas no están en la
tonalidad correcta de ese nivel. Revisa todos los niveles y las melodías."*

He is right, and it was a design gap rather than a bug. A level announces itself
by playing the first bars of its theme and then hands the player seven lemons,
so those seven have to belong to the same piece of music. **Levels 1 and 2 were
built that way in 2019** — their rows are notes lifted straight out of the
Overworld and the Underworld, which is why playing them sounds like the tune
that just played. **Levels 3 and 4 were given plain C major runs.** On level 4
that is audible from across the room: the Castle theme is in **G minor around
G3-G4**, and the lemons answered it a C major scale an octave above.

| Level | Theme | The seven lemons, low to high |
|---|---|---|
| 1 | Overworld | E6 G6 A6 B6 C7 E7 G7 — unchanged |
| 2 | Underworld | A3 AS3 C4 **D4** A4 AS4 C5 |
| 3 | Starman | C5 D5 E5 F5 G5 A5 **C6** |
| 4 | Castle | **G3 AS3 C4 D4 DS4 F4 G4** |

- **Level 4** was rebuilt in the theme's own key and octave: G natural minor,
  every note one the melody hammers (G3 and D4 are its alternating pedal, AS3
  opens the second bar, and C4/DS4/F4/G4 are where the chromatic answer lands).
- **Level 3** lost a C# that appears nowhere in the Starman theme and gained the
  **C6** the melody opens every phrase on. The theme uses exactly eight pitches;
  the row is seven of them, dropping the B5 that turns up once in the tail.
- **Level 2 was not on his list and turned out to be wrong too.** Its top lemon
  played **D5, a note the Underworld never plays** — the tune's highest note is
  C5. That was inherited from 2019. It is the D4 the melody does play now, moved
  up the row so the keyboard still ascends left to right and the pitch bar keeps
  telling the truth; the three octave pairs the theme alternates (A3/A4, AS3/AS4,
  C4/C5) are untouched.

The fourth case was found because the test was written as a **rule**, not as
four assertions: *every lemon on every level must be a note that level's theme
actually plays*. It is `test_every_level_plays_in_its_own_key`, and it also
checks the seven are distinct (two lemons sharing a note would be
indistinguishable to the guess comparison).

**THE CODES DID NOT CHANGE.** They are written down as key NUMBERS — the
organiser's booklet prints them on paper, in a folder someone carries to an
event — so retuning the keyboard means recomputing the frequencies the sequences
store and leaving the numbers alone. Proven, not asserted:

```
$ python3 docs/cartilla/seqs.py
cross-check against the host test, level 1: OK
level 1: 6  5  6  7  2  5  2  1  3  4      level 3: 2  4  6  1  5  3  7  4  2  6
level 2: 3  6  1  4  2  5  3  6  1  4      level 4: 5  1  3  7  2  6  4  1  5  3
```

### 2. A repeated lemon: the whole bar, held, instead of a sweep

*"Se encienden todos los LEDs a la vez y cuando la suelta se apagan."* The
backwards sweep shipped on 2026-09-13 and lasted two days, for a good reason:
motion is now what free play's wave uses, on the same ten LEDs, and two moving
cues on one bar is one too many.

It is a better shape anyway. Ten lit LEDs is the one thing this bar does that is
**not a count of something** — a score of ten is a win, and a win never leaves
you still holding the lemon. It lasts exactly as long as the finger does, so it
reads as "this is about what you are doing right now" rather than as an event
that has already happened, and it still ends on the identical bar it started
from, which was always the message. `showRepeatSweep()` and `REPEAT_SWEEP_MS`
are gone; `showRepeatHold()` and one `repeatBarOn` flag replace them, and the
release path now restores the bar for **both** modes through one call to
`restoreIdleDisplay()` instead of two special cases.

### 3. Free play: every note breaks a wave, from the lemon that made it

*"Si toca la tecla 1, el efecto tiene que ser de la tecla 1 hasta la 7. Si toca
la 7, de la 7 a la 1. Pero si toca una intermedia, por ejemplo la 4, tiene que
ser de la 4 hacia ambos lados. Como un efecto ola hacia ambos lados."*

That is one shape with seven readings of it, so `playKeyWave()` is one loop and
no special cases: a wavefront expands from the note's own place on the bar, one
LED further out each frame, until it runs out of bar. The end keys have only one
side to travel down — which is exactly the run across the whole strip he
described — and the middle keys give two lights parting. The wave from key 4 is
shorter than the wave from key 1, deliberately: the light stops when it runs out
of pond. The note is already sounding underneath it, and the bar settles on the
pitch meter afterwards, which is the part he said he liked.

Asserted from the LED **film** rather than the final pin states
(`test_free_play_wave_starts_at_the_key`), because by the time the note settles
the wave has been and gone: key 1's film contains `#.........` before
`.........#`, key 7's contains them in the opposite order, and key 4's contains
`...#.#....` and then `#........#` — a symmetry no end key can produce.

### 4. The chord barely came, and the reason is the return path

*"No ha funcionado especialmente bien la doble pulsación... puede ser que sea
una limitación de hardware. Piénsalo."*

Thought about, and it is a fact about this keyboard rather than a limitation of
it. Every lemon's pull-up current goes home through **one shared element**: the
player's body and the GND clip in their other hand. With one finger down, all of
a key's 220 Ω current flows through that single path. With **two** fingers down,
the two channels are pulling the *same* body node up together — so each of them
sits **shallower** than a single touch would. The fingers are in each other's way.

Gate 1 asked the second finger for a dip of `touchMargin + 2`, i.e. **deeper
than a lone finger has to manage**. That is the one thing two fingers cannot do.
It is now just "is this a touch at all" (`>= touchMargin`), and the
discrimination is left entirely to gate 2, the ratio — which the shared path
does not affect at all, because both dips shrink *together* and their ratio
stays near 1 while a shadow's stays low. That is why the ratio is the gate that
does the work.

Gate 2 was lowered with it (70 → 60 %) and put straight back, because the host
test showed what that costs: with a shadow modelled at 42 % of a finger, a 60 %
gate has almost no room under it and a 45 % *hold* ratio would not let a chord
go at all — the released lemon stays shadowed by the one still down, so the
chord never ended. 70/55 sits squarely between "a shadow" and "another finger".

**And the guessing has an end now.** `-DDEBUG_TOUCH` prints
`dips margin=N 1:.. 2:.. … 7:..` four times a second while any lemon is held:

```
pio run -e nanoatmega328-debug -t upload && pio device monitor
```

Press one lemon and read a column; press two and read two. The ratio between
them **is** `CHORD_MIN_RATIO_PCT`, measured rather than argued about — TODO 21.
If the numbers say two fingers genuinely cannot both clear `touchMargin` on this
fruit, that is the hardware limitation he suspected, and the answer is a lower
margin or a better clip contact, not a looser gate.

### Evidence

- **All five envs build.** `nanoatmega328` 17 384 B flash / 56.6 %, 555 B RAM /
  27.1 %; `nanoatmega328-debug` 17 738 B (the dip dump); emulation builds 12 480
  and 12 492 B.
- **Host tests: 107 + 145 checks, 0 failed**, up from 107 + 122. Three new
  scenarios (22 levels-in-key, 23 level 4 chosen and level 3 won, 24 the wave),
  and test 18 rewritten around the held bar.
  - 23 wins **level 3** end to end rather than level 4 on purpose: clearing
    level 4 clears the last level, which drops into `playEndingLoop()` — a piece
    that only stops for a button gesture and therefore never returns on a fake
    board. Level 4 is proven to nine notes of ten plus the tenth lemon's pitch,
    which is the whole code with no infinite loop.
- **`docs/cartilla/seqs.py` exits 0** and prints the four codes unchanged, which
  is what says the printed booklet is still correct.
- **Flashed and verified**: `/dev/ttyUSB0`, env `nanoatmega328`, 17 384 bytes
  written and verified by avrdude; the board boots, calibrates seven baselines
  and announces `Level 1`.
- **Still needs fingers on fruit**: whether the chord now comes reliably, and
  whether `FREE_WAVE_STEP_MS` (14 ms/frame, so 140 ms for an end key) makes fast
  playing feel syrupy. Both are single constants.

## 2026-09-15 — free play opens with a sweep, and two lemons sound as two notes

Two asks from Sergio, both about FREE PLAY, both in
`versions/v5.5-power-filter/firmware/`.

### 1. The two end LEDs are gone, and the mode announces itself instead

Free play used to idle with **its two ends lit** — a shape the game's
left-filling bar can never draw, so one glance said "this is the instrument".
It worked as a badge and failed as a display: it never went away. Press a lemon,
the pitch bar climbs, and those two LEDs are still sitting inside the reading
pretending to be part of it. *"Al tocar y que se vayan encendiendo los LEDs de
la escala se queda un poco raro... que no se queden esos dos LEDs encendidos de
los extremos."*

So the badge became an **event**. `playFreePlayEntrySweep()` runs once, on the
way in, in three beats:

1. two lights walk in from the ends and meet in the middle — the old idle shape,
   collected up and carried away,
2. they open back out, filling the bar to all ten,
3. and the bar empties from the outside in, to nothing.

It ends **dark**, which is exactly where free play now lives, so the animation
hands over to the mode instead of being switched off by it. Then do-re-mi-fa-sol-
la-si plays as it always did, and the bar stays dark until a finger lights it.
`showFreePlayIdle()` is one `allLedsOff()` now.

**The scale also stopped being abortable.** `playFreePlayFlourish()` gave up the
moment either button read down — a leftover from when it doubled as the wheel's
preview for free play, which it has not done since free play left the wheel on
2026-09-13. The only button that can be down while it plays is the **+** that
just asked for the mode, so the check did nothing but cut the announcement short
for anyone who holds a button a beat longer than three seconds. *"Y como siempre
toques la melodía."* It plays to the end now.

### 2. Two lemons at once sound as two notes

*"Cuando el usuario toque dos notas a la vez, esto se detecte y toque la nota
correspondiente a ambas notas."* Free play only — the game recognises a guess by
comparing **one** frequency against the secret sequence, so a chord there is not
a richer guess, it is an unanswerable question. The game's code is untouched.

**Sounding it** is the easy half. `tone()` owns Timer2 and Timer2 makes exactly
one square wave, so the two voices take turns every `CHORD_SWAP_MS` (10 ms):
50 handovers a second, above the ~20 Hz where the ear stops hearing an
alternation and starts hearing an interval, and slow enough that C5 still gets
five whole cycles to establish its pitch. `tone()` reprograms OCR2A in place
rather than restarting the pin, so a handover costs no click. It is the Game
Boy's arpeggio trick.

**Deciding there are two fingers** is the hard half, and it is the whole of the
work. A touch on this keyboard is 3-4 ADC counts and the channels are coupled:
one finger already drags its neighbours part of the way down, which is why
`strongestKey()` picks a winner by depth instead of taking the first channel
over its threshold. A rule that asked "are two channels below threshold?" would
hear a chord on every single note anyone played — and **a false chord is far
worse than a missed one**, because a note that warbles like two ruins every note
in the mode. So `chordPartnerFor()` is deliberately hard to please. Three gates,
all of which the second lemon must pass:

| | gate | why |
|---|---|---|
| 1 | dip ≥ `touchMargin + CHORD_EXTRA_COUNTS` (2) | coupling crumbs sit just over the plain margin |
| 2 | dip ≥ `CHORD_MIN_RATIO_PCT` (70 %) of the first finger's dip | a second finger is the same ORDER as the first; a shadow is a fraction of it. **This is the gate that separates the two cases** |
| 3 | it is the ONLY key that passes 1 and 2 | three lemons' worth of signal is a hand laid across the fruit, not a chord — refuse the lot |

…and then the survivor holds still for `CHORD_CONFIRM_MS` (24 ms), so a spike on
the way into a single touch cannot open a second voice for one scan.

**Letting go needed the same idea, and that was the bug worth catching.** The
first version asked `keyStillDown()` about the second voice and would have held
a chord until BOTH fingers left: lift one lemon while the other is held and its
channel does not come back to its resting level, it falls back to the *shadow*
of the one still down — which is deeper than the release threshold. What does
collapse the instant a finger lifts is the **ratio** between the two dips, so
that is what is watched, with hysteresis (opens at 70 %, lets go under 55 %) and
the same 90 ms confirmation a single note gets. Either voice may be the one that
leaves: let the lower lemon go and the upper one is **promoted** to the note
under the finger rather than the sound stopping, which is what every instrument
does. While a chord is up it owns the release decision for both of its voices —
`loop()` hands over to `serviceChord()` and does not second-guess it.

`trackBaselines()` now skips the second voice too, or a chord held past
`STUCK_MS` would have re-baselined the lemon underneath it.

**The bar shows two lone LEDs**, one at each note's place. A single note fills
the bar from the left, so two separated points is a shape one finger cannot
draw — the light says "two" before the ear has finished deciding. It is also,
on purpose, the shape the idle bar used to wear: keys 1 and 7 are simply the
widest chord this keyboard has.

### Evidence

- **All five PlatformIO envs build**: `nanoatmega328` (the flashed one) at
  **17 348 B flash / 56.5 %** and **555 B RAM / 27.1 %**, up from 15 570 B /
  50.7 % and 536 B / 26.2 %. `nanoatmega328new`, `nanoatmega328-debug`,
  `emulation` and `emulation-freeplay` green.
- **Host tests: 107 + 122 checks, 0 failed** (`firmware/test/run.sh`), up from
  107 + 107. Three new scenarios, and the fake board grew the thing they needed:
  **`FakeBoard::couplingDepth`**, a model of one finger shadowing the other
  channels. It is 0 by default, so every test written before today still sees
  the clean board it was written for; the chord tests set it, and a chord rule
  that only worked on an idealised board would not be a chord rule.
  - *19* — the sweep's three beats are asserted from the LED **film**, not the
    final pin states, because an animation is invisible to a snapshot; plus the
    bar ends dark and the scale still plays all seven notes.
  - *20* — both notes take turns on the one buzzer; the bar is `#.....#...`;
    releasing either voice leaves the other **sustaining**, not re-struck.
  - *21* — the expensive failure, three ways: a shadow too shallow (fails gate
    1), a shadow deep enough to clear the floor but not the ratio (8 counts
    against a finger's 12 — 67 % against the 70 % needed), and three fingers at
    once (fails gate 3). No chord opens in any of them.
- **Not run here**: the Velxio `--mode verify`. The harness repo is not on this
  machine, which is also why TODO 19 is still open. The host tests are V5.5's
  regression suite (`versions/README.md`), and free play has always been tested
  there rather than in the browser — the emulation has no pins left for the two
  buttons.
- **Flashed to the board**, `/dev/ttyUSB0`, env `nanoatmega328` (the Nano was
  plugged in while this was being written — it had not been at the start):
  17 348 bytes written and **verified** by avrdude, and the boot log came back
  over the serial monitor: banner, seven baselines, an auto margin, `Level 1`.
  What that proves is that the firmware runs; the two features themselves need
  fingers on fruit, which is TODO 21 and 22.

```
  key 1 baseline=1017 noise=15 -> threshold=985      auto margin=32
  ...                                                (worst noise 16 x 2)
  key 7 baseline=1018 noise=16 -> threshold=986      Level 1
```

  Note the margin: **32 counts** on a bench where nothing is hanging off the
  pins. The chord's absolute gate is `touchMargin + 2`, so it scales with
  whatever calibration decides on the day rather than being a number tuned to
  one rig — which is the only form of that gate that survives the fruit
  changing. The ratio gate does not depend on the margin at all.

Docs updated in step: the version README, `docs/USER-GUIDE.md`,
`docs/GUIA-DE-USO.es.md`, and TODO items 18 (its two-ends question is answered),
21, 22 and 23. The organiser's booklet is still accurate — it never described
the idle bar — but it now describes less than the piano does; that is TODO 23,
worth a line at the next reprint rather than a reprint of its own.

## 2026-09-14 — the organiser's booklet, built and printed

One A4 sheet, black and white, both sides, folding down the middle into an A5.
It exists so someone who has never seen the lemon piano can switch it on,
explain it and rescue it with Sergio not in the room. `docs/cartilla/`, and it
went to the laser on job `laser-9`.

Four panels: the cover; what the two buttons do plus **si algo va mal**; how the
game works plus the two questions everyone asks about the finger; and **the four
codes**. Almost no prose — nearly every explanation is a drawing of the **LED bar
itself**, ten boxes filled or empty, because that is the only thing the piano can
say and the only thing a helper has to read.

**The codes are derived, never typed.** A level's code lives in the firmware as
note *frequencies*, and which lemon plays a note is different on every level —
each has its own seven-note row — so the answer a player needs exists nowhere in
the source. `docs/cartilla/seqs.py` resolves one table against the other and
**cross-checks level 1 against the sequence hard-coded in the host test**, which
was written independently. It exits non-zero rather than guess. Change a melody
in `main.cpp`, re-run `build.sh`, and the booklet is right again:

```
level 1  6 5 6 7 2 5 2 1 3 4      level 3  2 4 6 1 5 3 7 4 2 6
level 2  3 6 1 4 2 5 3 6 1 4      level 4  5 1 3 7 2 6 4 1 5 3
```

The booklet also answers the question those numbers raise on their own — *which
lemon is number 1?* — physically rather than by wiring diagram: it is the one
that sounds **lowest**, and free play (hold + for 3 s) plays do re mi fa sol la
si left to right, so anyone can check it in ten seconds.

Two things caught in review before printing, both visible only once rendered:
**Press Start 2P has no accented capitals** and drew `CóMO SE JUEGA` and
`LIMóN`, so the pixel face is now used only where Spanish needs no accent and
DejaVu carries the rest; and the ten-LED bars were 42 mm wide in a 19 mm column,
so the text ran straight over them.

Printed duplex **short edge** — the content is landscape, so that is the flip
that reads like a book; long edge would put the inside spread upside down.

## 2026-09-14 — the event poster, stored byte for byte

Sergio made a poster with Gemini to stand behind the lemon piano at a private
event, so people come over and play it, and asked for it in the repo with no
loss of quality. It is at `docs/poster/super-limon-piano-cartel.png`, copied
**byte for byte** — never opened and re-saved, never re-encoded:

```
sha256  b8db4412b7b9a77b31b51f8a2a371763dbf7a310eab1b599980af863dad18f26
bytes   1 010 859
848 x 1264 px, 8-bit RGB
```

`cmp` against the original returns identical. The hash is written into
`docs/poster/README.md` so a later "compress this PNG" is detectable rather than
silent.

**What it can be printed at**, measured rather than assumed: the file is pixel
art in style only — **102 156 distinct colours** with soft anti-aliased edges —
so nearest-neighbour enlargement, which is lossless on real pixel art, would
only magnify the softness. 300 dpi is 72 × 107 mm; full A4 works out at about
**102 dpi**, soft up close and fine from a metre away, which is normal for
large-format printing. Its aspect is 1:1.49 against A4's 1:1.41, so "fit to
page" leaves ~10 mm of white down each side and "fill page" would crop ~16 mm
off the top and bottom, into the wordmark.

Also built, and NOT chosen: an A4 poster composed here in HTML and rendered
through headless Chrome at a true 2480 × 3508 px (300 dpi) — the Super Mario 256
wordmark with a hand-built acute accent the font does not ship, seven
photographed lemons cut out by chroma, and the same four levels. It is outside
git at `~/Pictures/piano-limones/` on quantumpc.

## 2026-09-13 — a repeated lemon is not a mistake: it sounds, and the bar says so

Sergio, after the four changes above landed: the locked-key rattle reads as
"you got it wrong", and pressing the same lemon twice is not wrong. It is just
not a move. He asked for the lock and the scolding noise to go, for the note to
sound properly, and for the piano to say **visually** that the press did not
count — and left the choice of cue to me.

**What the game does now.** A repeat sounds its note at full voice (a piano
before it is a game), scores nothing, advances nothing and — the part that
changed — costs nothing. Gone with it: `KEY_LOCK_COOLDOWN_MS`, `lastReleaseAt`,
`lastSoundedKey` (fully redundant with `lastCountedKey`) and `soundKeyStuck()`.
`sfxKeyStuck` stays in `mario_sfx.h`, unused by V5.5; earlier versions still
play it.

**The cue: the bar runs BACKWARDS.** One LED from the right end to the left,
then the progress bar snaps back exactly as it was. Three deliberate choices,
each one a reason it can be read across the room with the lid closed:

- it **moves**, and this bar is otherwise perfectly steady while playing. Motion
  is already this piano's word for "neither a score nor a question" — it is what
  the wheel used to use to mark free play — so it cannot be read as either.
- it runs **right to left**, against the direction progress fills, so it reads
  as "that took you nowhere" and never as a step forward.
- it **ends on the identical bar it started from**. The score is visibly
  untouched, which is the whole message. A wrong note blanks the bar and LEAVES
  it blank, so the two can never be confused.

It is not the menu's entry sweep either: that one goes out and back, is slower,
and arrives with a three-note cue.

**A cue that starts and ends on the same picture is invisible to a test that
only reads final pin states** — which is how the first version of test 18 passed
with the sweep deleted. So the fake board now records a frame per change to the
bar (`ledFrames`, capped) and the test asserts the **shape of the motion**, not
just where it landed.

Evidence:

- New **test 18**, `A repeated lemon sounds, scores nothing, and costs nothing`:
  it sounds, it is that lemon's own note, no WRONG, no OK, progress untouched,
  the bar ends where it started, one sound only, the cue really is a right-to-
  left run, the next correct lemon still scores, and a wrong note still blanks
  the bar and leaves it blank.
- **107 + 100 checks, 0 failed.**
- **Mutation controls, run separately:** delete `showRepeatSweep()` → 2 checks
  fail (`0 frames, none of them a backwards run`); make the repeat silent again
  → 4 checks fail.
- Two harness defects found and fixed on the way, both mine: `ledFrames` grew
  without bound, and test 18 indexed an empty vector (ASAN: SEGV at
  `piano_sim_test.cpp:585`). The second is why the first mutation run reported
  a crash instead of a failure.
- `pio run` clean on all five envs; 15570 B.
- Flashed and verified on the board: boots, all seven at baseline 1023 /
  noise 0 / margin 4, Level 1.

Both printed instruction sheets and `docs/MARIO-SOUNDS.md` updated — they
documented a lock, a cooldown and a rattle that no longer exist.

**Not yet played by a human.**

## 2026-09-13 — four changes from the first real session with the board

All four are Sergio's own reports after playing the fixed v0.7.1 rig, and each
one lands with a named test and a mutation control.

**1. Neither button ramps the sensitivity any more.** Holding used to fire a
step every 120 ms. Both buttons carry a hold gesture now, so a hold that also
spun the knob thirty times re-tuned the keyboard on every mode change. A tap is
one step and that is all. The nudge still fires on PRESS — a knob that waits for
the release feels broken — so the gesture that fires puts its own step back:
each button snapshots the margin as it goes down (`marginBeforePlus` /
`marginBeforeMinus`) and restores its own.

**2. The LED bar counts SENSITIVITY, not margin.** More LEDs = more sensitive =
a smaller margin, so **+** adds light and **−** takes it away. It was inverted,
and he called it immediately: a button labelled "more" that puts lights out
reads as "less" from across the room. The bar's own comment already claimed it
was a sensitivity meter; now it is one.

**3. FREE PLAY left the wheel and became a hold on +.** His words: "mantener el
botón más es un switch entre el modo libre y el nivel". So the wheel is four
levels and nothing else — turning it can never take the instrument away — and
+ held for 3 s swaps game for instrument and back. Going in remembers the level
it interrupted; coming out restarts it, for the same reason accepting a level
does. A player who never touched the wheel is on level 1, so for them it is
exactly the "free play <-> level 1" switch he asked for, with no special case.
Opening the wheel from inside free play lands on the interrupted level, so the
wheel is still a way out. + and − now arm identically (1 s meter, 3 s fire) and
differ only in where they land.

**4. A HELD lemon sounds once.** In free play, resting a finger on a lemon
machine-gunned the note. The contact is not a switch: through 1 MOhm it breaks
for a few ms at a time without the finger moving, and every one of those ended
the note and started a new one. A release is now only believed after
`RELEASE_CONFIRM_MS` (90 ms) of silence — the note survives any shorter dropout,
a real release still lets it sound again, and fast deliberate playing is
untouched.

Evidence:

- `test/arduino/Arduino.h` grew a flaky-contact model (`dropoutEveryMs` /
  `dropoutMs`) so a held key can read clear in bursts, which is what the bug
  needed to exist at all.
- New tests: gestures 2, 3, 3b, 3c (no ramp; + arms and toggles; + cancels; the
  two holds never cross) and piano 15, 16, 17 (the switch both ways and the
  level it remembers; a held lemon is one note; the bar counts sensitivity).
- **107 + 84 checks, 0 failed.**
- **Mutation controls:** put the ramp back and 5 gesture checks fail; remove the
  release confirmation and test 16 reports **11 notes for one held lemon** —
  the reported symptom, reproduced exactly.
- `pio run` clean on all five envs; 15754 B.
- Flashed and verified on the board: boots, all seven at baseline 1023 /
  noise 0 / margin 4, Level 1.

Docs rewritten to match, including both printed instruction sheets
(`docs/USER-GUIDE.md` and `docs/GUIA-DE-USO.es.md`) — they documented a ramp
that no longer exists and a wheel item that moved.

**Not yet played by a human.** Everything above is the host tests and a boot log.

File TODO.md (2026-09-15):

# TODO — fix roadmap

Firmware bugs found in the rescued 2019 code. **Items 1–12 are done** (applied
in the 2026-07-12 refactor to the firmware that is now
[V4](versions/v4-water-pump/), all envs still build green, RAM down from
778 B/38 % to 309 B/15 %). Items 13, 15, 16, 17 are open — 13 and 15 need the
physical V5 build.

Items apply to the newest board ([V5](versions/v5-led-bar/)) unless a version is
named. New hardware belongs in a new version directory, not in this list — see
[docs/VERSIONING.md](docs/VERSIONING.md).

## Correctness — ✅ done

- [x] **1. Post-victory false fail** — clearing `pressedNote = 0` on victory
  (plus the cleaner edge-triggered engine) stops the instant "fail" after a win.
- [x] **2. Relay init** — replaced `analogWrite(pin, HIGH)` with a defined
  `pumpOff()` (`RELAY_1 LOW`, `RELAY_2 HIGH`) set *before* `pinMode(OUTPUT)`.
- [x] **3. `fails` never reset on restart** — `selectGame()` now clears
  `fails`, `currentStep`, `dead` and the LEDs, so a restart after death is a
  clean slate.
- [x] **4. UART clobber + serial** — dropped the bogus `pinMode(0..7, INPUT)`
  block; all debug output goes through one `log()` helper guarded by
  `serialEnabled`, with `Serial.begin()` in `setup()`.
- [x] **5. `buzz()` divide-by-zero** — early `return` on `frequency <= 0`.
- [x] **6. Assignment-in-condition** — the dead `if (game = 1)` toggle block is
  deleted.

## Gameplay / robustness — ✅ done

- [x] **7. LED timeout** — now real-time via `millis()` (`LED_FEEDBACK_MS`),
  not a loop counter.
- [x] **8. Debounce / edge detection** — the sequence engine is edge-triggered
  (`keyHeld[]` rising-edge), so a held finger no longer machine-guns the
  sequence and **melodies with repeated consecutive notes are now playable**.
- [x] **9. Blocking melodies** — reviewed and **kept blocking on purpose**: the
  game is meant to pause while the victory/death tune or the spray plays, and
  idle key input stays responsive. Revisit only if the game grows a UI.

## Code quality — ✅ done

- [x] **10. Melodies in `PROGMEM`** — all tunes moved to flash; static RAM
  dropped to 309 B.
- [x] **11. De-duplicated `*_cut` arrays** — one copy of each theme, played
  from an offset (`MARIO_VICTORY_FROM` / `UNDER_VICTORY_FROM`); lengths derived
  with `sizeof` so they can't drift.
- [x] **12. Auto-calibrated touch** — `calibrate()` samples each key's floating
  baseline at boot and sets `threshold = baseline + TOUCH_MARGIN`, replacing
  the hardcoded 100/170-per-power-supply constant.

## Hardware / docs — open (needs the physical V5 build)

- [ ] **13. Wire and playtest the V5 board**: ten green LEDs on
  D2,D3,D4,D5,D6,D9,D10,D11,D12,D13 (220 Ω each), game-select SPDT on A7
  (5 V/GND), restart on D7. The Velxio emulation is the closest thing to a
  reference schematic today
  ([versions/v5-led-bar/emulation/lemon-piano.yaml](versions/v5-led-bar/emulation/lemon-piano.yaml)).
- [x] **14. Full wiring diagrams** — done, and now **one per hardware revision**:
  `versions/*/images/wiring-{v1,v2,v3,v4,v4.5,v5}.png`, generated from the
  declarative contracts in [tools/wiring_diagrams.py](tools/wiring_diagrams.py) on
  the wirewright auto-router + DRC (0 violations). A formal Fritzing/KiCad redraw
  is still optional.
- [ ] **15. Confirm A7 game-select biasing** on the real board (SPDT vs.
  switch + 10 kΩ pulldown); A7 has no internal pull-up.
- [ ] **16. Decide: emulate the 2019 boards (V1–V3)?** It needs a
  `#ifdef VELXIO_EMULATION` shim inside the 2019 sketches (buzzer onto a PWM pin
  with `OCR2A` cleared, key 7 off A6, pull-up buttons instead of the divider) —
  i.e. editing code whose value is being the untouched original. Blockers per
  board are written up in each `versions/v{1,2,3}-*/emulation/README.md`. If yes,
  start with V3: it has a real game to assert on.
- [ ] **17. V2 quirk:** `Serial.begin(9600)` is commented out while the
  `Serial.print` calls are live — decide whether to fix it (helps anyone reviving
  the rig) or leave it as 2019 shipped it.

## Open — needs the physical board (2026-09-09 firmware)

- [ ] **18. Playtest FREE PLAY and the MODE WHEEL on the real V5.5 board.**
  Everything about them was designed and validated with the board unplugged
  (`versions/v5.5-power-filter/firmware/test/run.sh`, 97 + 56 checks green,
  mutation-checked). What a host test cannot judge: whether **3 s** is the right
  hold, whether the charge chirp is reassuring or annoying, and whether an
  8-note preview is too long to browse five modes. All three numbers are single
  constants — `GES_MENU_HOLD_MS`, `GES_MENU_ARM_MS`, `MENU_PREVIEW_NOTES`.
  (The fourth question here used to be whether the two-ends-lit idle bar read as
  "this is the piano". It was answered on 2026-09-15: it read as clutter under
  the pitch meter, and free play idles dark now.)
- [ ] **19. Run `emulation/piano-mode.yaml`.** Written on a machine without the
  Velxio harness, so it has never had a `--mode verify` pass. It parses and its
  build compiles; that is all that is currently claimed for it.
- [ ] **20. Should the chosen mode survive a power cycle?** Free play currently
  lasts until you unplug it, then the piano is back on level 1. One EEPROM byte
  would fix that, at the cost of a write per mode change — deliberately not done
  without the owner asking, since "it forgets" may well be the right behaviour
  for a toy that lives on a shelf.

- [ ] **21. Measure the chord gates on real fruit** (2026-09-15, still open
  after the first playtest). Sergio played the chord the day it shipped and it
  barely came. One cause was found and fixed the same day — gate 1 asked the
  second finger to dip *deeper* than a lone finger has to, which the shared
  return path makes impossible (see the CHANGELOG) — but whether **gate 2** is
  in the right place is still unmeasured. It does not have to stay that way:
  - `pio run -e nanoatmega328-debug -t upload && pio device monitor` now prints
    **`dips margin=N 1:.. 2:.. … 7:..`** four times a second while any lemon is
    held. Press one lemon and read a column; press two and read two. The ratio
    between them **is** `CHORD_MIN_RATIO_PCT`, measured instead of argued about.
  - `startChord()` also prints both dips every time a chord does open.
  - The knobs: `CHORD_MIN_RATIO_PCT` (70 %, opening) and `CHORD_HOLD_RATIO_PCT`
    (55 %, letting go). **A false chord is much worse than a missed one** — a
    single note that warbles like two ruins every note — so a shadow measured
    near the gate means the gate goes up, not the guard comes down.
  - If the measurement says two fingers genuinely cannot both clear
    `touchMargin` on this fruit, that IS the hardware limitation Sergio
    suspected, and the answer is a lower margin (the + button) or a better clip
    contact, not a looser gate.
- [ ] **22. Does the chord swap rate sound right?** `CHORD_SWAP_MS` is 10 ms,
  chosen so the alternation sits above the ~20 Hz where the ear stops hearing
  two notes taking turns, while still giving C5 five whole cycles per turn. On a
  piezo with a 2-4 kHz mechanical resonance that is a calculation, not a
  listening test. One constant.
- [ ] **23. The organiser's booklet does not mention the chord.**
  `docs/cartilla/` is still accurate — it never described the idle bar — but it
  now describes less than the piano does. Worth a line in the MODO LIBRE row
  next time it is reprinted, not worth a reprint on its own.

## Nice-to-have (new ideas, not blocking)

- [ ] On-hardware playtest: confirm `TOUCH_MARGIN` feels right; tune if needed.
- [ ] LED flourish on win (e.g. chase/blink the full bar) before the theme, and
  on auto-advance.
- [ ] Optional per-note key LED feedback, or a "wrong" blink, if the plain
  blank-on-miss feels too subtle.

## Done in V5 (2026-07-14)

- [x] Removed relays / water pump / red LED / fail-counter / death tune.
- [x] Ten-green-LED progress bar; blank-all-on-wrong; win = all ten lit.
- [x] Auto-advance between the two games on win.
- [x] Game-select moved to A7 to free the 10th LED pin.
- [x] V5 Velxio emulation (10 LEDs) built + headless verify green.

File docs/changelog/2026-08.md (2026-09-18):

# Changelog archive: 2026-08

Entries moved here verbatim from `CHANGELOG.md` by `qpc-changelog-archive`.
Nothing on this page has been reworded; `--verify` proves that against a
fingerprint of the archive. Newest first, as in the original.

---

## 2026-08-05 — V6 proposal: battery power + amplified speaker (diagram only)

- **`versions/v6-battery-amp/`** — a **diagram-only proposal**, explicitly not a
  complete version directory: no `firmware/`, no `emulation/`, no `HARDWARE.md`,
  not in the version index tables, never built or measured. Its README lists
  exactly what is missing. The newest real board is still V5.5.
- **`build_v6()`** in `tools/wiring_diagrams.py` — 66 nets, DRC 0 violations.
  V5.5's board and filter unchanged, plus (a) a 1S LiPo 3.7 V / 10 000 mAh on an
  IP5356 power-bank driver module feeding the existing 2-pin `5V IN` header, and
  (b) an LM386 module + 4 Ω 3 W speaker in parallel with the buzzer on
  `/BUZZER`. **The PCB does not change**: ADR-025 already sized `5V IN` for a
  chopped USB-A pigtail and ADR-034 already put `SPK` (J5) across the buzzer, so
  moving the pigtail between the module's USB-A and a wall charger *is* the mode
  switch.
- **The amplifier hangs off the unfiltered 5 V (`vbus`), not the rail** — the
  one decision worth remembering. The CLC pi has fc ≈ 730 Hz, so at 1 kHz it
  only attenuates ~5 dB: audio-band current pulled *through* the filter would
  land almost unattenuated on the rail, which is AVcc, the reference the 3-4
  count (15-20 mV) touch margin is measured against. So the amp taps the module
  before the TVS and shares no series element with the keyboard. Consequently
  the drawing's `+5 V` rail **stops short** of the audio block (new `v5_x0` /
  `v5_x1` args on `_board`) rather than spanning the canvas — it is not there.
- D13 drives a 10 kΩ / 1 kΩ divider (≈ ÷11, 0.45 mA off the pin) and a 1 µF DC
  block, never the coil: a bare 4-8 Ω speaker on D13 would destroy the pin
  (PCB ADR-034). The on-board piezo stays in parallel on the same node.
- The README argues the case a battery makes beyond portability: the V5.5 filter
  is a **series** filter and cannot touch the common-mode path, so on battery the
  board floats *with* the player and that 50 Hz difference cancels in the ADC —
  plus the charger's Y-cap leakage stops flowing through the player's hand. It
  also records the five open risks to measure first, the worst being low-load
  auto-shutdown (the piano idles at 25-35 mA; IP5356-class modules cut out below
  ~45-75 mA, i.e. it would switch off during the silences).
- `keyboard_2019()` gains `dx=0` and `_board()` gains `v5_x0`/`v5_x1`, both
  backward-compatible: re-rendering V1-V5.5 leaves every committed PNG untouched.
  (V5.5's PNG does differ from its committed bytes on this machine, but the
  *pristine* engine and builder reproduce that same 113 885-pixel delta — it is
  pre-existing font-rendering drift, not this change, so it was left alone.)
- Engine side (`../eda-wirewright`): four new component factories — `battery`,
  `power_bank_module`, `amp_module`, `speaker` — plus `deco.panel` for the
  "three power modes" box, with tests. See its CHANGELOG.

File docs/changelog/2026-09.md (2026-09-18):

# Changelog archive: 2026-09

Entries moved here verbatim from `CHANGELOG.md` by `qpc-changelog-archive`.
Nothing on this page has been reworded; `--verify` proves that against a
fingerprint of the archive. Newest first, as in the original.

---

## 2026-09-13 — the SENS − button played a note: A7 is on the key multiplexer

With all seven pull-ups swapped to 1 MΩ and R18 finally a real 10 kΩ, every key
sounds and the dead LED 4 came back. A new symptom arrived with them: pressing
the **−** button beeped like a key and, held on, scored a wrong guess.

**Cause, and it is entirely inside the chip.** SENS − is **A7**, which is
analog-in only (hence R18) and is **channel 7 of the same ADC multiplexer that
carries the seven keys**. `serviceButtons()` reads it at the top of every
`loop()`, immediately before the key scan starts at A0 — and while the button is
held A7 sits at **0 V**, so the sample-and-hold cap is handed to key 1 holding
zero. Through 220 Ω that refilled 4000 τ before the conversion finished; through
1 MΩ one conversion closes only **57 %** of the gap, and `readKey()`'s single
discarded conversion (2026-09-13, earlier today) is only the first step.

Reproduced on the host with no hardware: `readKey(0) = 944` against a threshold
of 1016 — **72 counts below the trigger point**, every loop, for as long as the
button is down. Which also explains why it stopped past the middle of the LED
bar: the droop is finite, so a wide enough margin hides it. That was the margin
covering the bug, not the button behaving.

**Fix:** `readKey()` now converts the channel **until two readings agree**
(≤ 1 count apart, hard stop at 12) before averaging four. Not a bigger constant —
a settled 220 Ω channel breaks out on the second conversion and costs 112 µs, the
0 V → 5 V worst case on 1 MΩ takes eight and costs 0.9 ms, and nothing in it is
tuned to a particular pull-up. These resistors have changed twice already.

Evidence:

- `test/arduino/Arduino.h`: the binary mux-residue model replaced by an
  exponential one (0.575 of the gap per conversion at 1 MΩ), with A7 on the same
  multiplexer and settling instantly, which is the asymmetry that causes the bug.
- New **test 14**, `Holding SENS − does not press a key`. 68 checks, 0 failed.
- **Mutation control:** restore the single discard and test 14 fails 3 of 6.
- `pio run` clean on `nanoatmega328`, `nanoatmega328new`, `emulation`; 15492 B.
- Flashed and verified on the board: boots, calibrates all seven at baseline 1023
  / noise 0 / margin 4, Level 1.

**Verified on the board the same day:** Sergio pressed **−** repeatedly on the
real rig with this firmware on it — **no key sounds**
(`qpc-approvals piano/boton-menos-a7` → approved). That also kills the competing
theory: if the note had been his body coupling into a 1 MΩ node while he held
the button, changing how many times a channel is converted could not have
removed it. It was the multiplexer.

Full write-up: `pcb/docs/REVIEW-v0.7.1-silent-keys.md` §3.

## 2026-09-13 — quiet-rest control: 1 MΩ does not ghost, and the game is loaded

The V5.5 game firmware (with the first-conversion discard) was flashed to the
board: 15454 bytes written and verified. It boots, calibrates all seven at
baseline 1023 / noise 0 / margin 4, enters Level 1, and **detects key 1** — the
`key 1 again - locked` messages are the repeat lock behaving correctly, since
keys 2–7 are still 220 Ω and cannot unlock it.

A first pass showed chatter (11 retriggers in 0.6 s) and the margin walking from
4 to 76 on its own. Both were the operator playing with the board during the
flash — he confirmed it, and then left the rig untouched so it could be proved.
Unattended batch, nobody in the room:

- **Game, 4 min at rest:** after `Level 1`, **zero lines**. No phantom notes.
- **Probe, 4 min at rest, 2087 samples:** the 1 MΩ channel reads **1023 in
  100.00 % of samples** — zero excursion, zero samples below the 1019 threshold.
  Channels 2–7 (still 220 Ω) likewise flat.

Against a press signal of 132–291 counts and a threshold of 4, that settles it:
**do not raise `TOUCH_HYSTERESIS`, do not drop to 470 kΩ.** 1 MΩ has room on both
sides. Logs kept as `*-quiet-rest-4min-2026-09-13.txt`; the batch re-flashed the
game afterwards, so the board is playable as it stands.

Process note: the results sat finished for 26 minutes because the agent's own
wait loop ran `pgrep -f quiet.sh`, a pattern that **matches the waiting shell's
own command line** — it waited on itself and no completion ever fired. The user
had to come and say so.

## 2026-09-13 — SOLVED: R1 at 1 MΩ, 15 clean presses, no ground clip

External 1 MΩ from J2 pin 1 to the Nano's 5V pin, R1 lifted. Baseline **1022,
noise 2**, so the game's auto-margin would be **4**. Running event detection at
that real threshold finds **15 presses on channel 1**, and the operator's account
of the session falls straight out of the timestamps:

| phase | presses | dip |
|---|---|---|
| no ground, shod | 5 | **132–200** |
| gripping ground | 5 | **255–291** |
| barefoot on the floor | 5 | **166–258** |

Worst of the fifteen: **132 counts against a margin of 4 — 33× headroom.** Best:
72×. Presses last 300–1500 ms and return cleanly to 1023. **Channels 2–7 stayed
at exactly 1023 for all 90 s** — no crosstalk, no phantom notes, no stuck keys.

Barefoot does matter and does not matter: the floor is a partial return to
earth, better than isolated and worse than a hand on circuit ground, and the
three phases measure it cleanly. All three clear the threshold thirty times over.

**What the three-day zero actually was.** Not a broken board, not a bad netlist,
not flux, not the fruit header — a **220 Ω pull-up used as a body-resistance
sensor**. It needs the whole hand → body → fruit path under ~56 kΩ; a clipless
touch on this board measures **5–10 MΩ**. Four orders of magnitude, which is why
no assembly fault could have explained it and every intermediate theory missed.
The breadboard was the same design working on **2 counts** of headroom (§2f);
the PCB simply fell off that edge. 1 MΩ turns 2 counts into 33×.

Next: swap R2–R7 to 1 MΩ, then re-run the probe with all seven high-impedance —
the one thing this capture cannot predict, because channels 2–7 are still 220 Ω
and therefore immune to the coupling a MΩ neighbour could induce. Fallback if
ghosting appears: 470 kΩ, still ~65–145 counts on the measured contact.

## 2026-09-13 (night) — `readKey()` discards its first conversion, with a test that proves it

Firmware, V5.5 only. `readKey()` now throws away one conversion on each channel
before averaging its four samples.

**Why now.** The ATmega328P's sample-and-hold charges through the source; the
datasheet's ceiling is a **10 kΩ** source impedance, above which the first
conversion on a newly selected channel has not settled and mostly carries the
*previous* channel's level. At 220 Ω that never mattered. It matters the moment
the pull-ups go up — and the bench numbers say they must: measured on the real
v0.7.1 board, a **clipless touch is a 5–10 MΩ path**, which is 1–2 counts through
220 Ω and **91–168 counts through 1 MΩ**. Without the discard, a high-impedance
keyboard reads as the "gradient ramps" the V4 front end was rejected for in July.
One extra conversion per key, ~112 µs, harmless at any impedance, so it is
unconditional rather than a build flag.

**And a positive control, because 56 green checks proved nothing here.** The fake
board gained an optional `muxResidue` model: with it on, the first conversion on
a newly selected channel returns the previous channel's level — the textbook
description of an unsettled S/H. New section 13 holds key 5 down and asserts the
held channel reads its own level and the idle neighbour is not dragged with it.

Verified by mutation: **delete the discard and section 13 fails**, with the idle
neighbour reading **971 instead of 1023** — 52 counts of smear against a margin
of 4, i.e. a phantom note. Every other check passes either way, which is exactly
why the test had to be written: a 220 Ω front end settles instantly and cannot
show the bug.

97 + 62 checks green, AVR build clean (15454 B flash).

Still not applied to the board: the resistor swap is the owner's call and the
measurement that justifies swapping all seven has not been taken yet.

## 2026-09-13 (late) — R1 → 10 kΩ, twice: a floating node, then the real number

R1 lifted, a 10 kΩ through-hole resistor hung externally from J2 pin 1.

**Run 1, 10 kΩ to J1 ("5V IN").** Channel 1 swung 512 counts (383…895), the
other six flat. It looked like a triumph and was a floating pin: baseline **735**
(≈ 3.6 V) not 1023, the channel rose **160 counts above its own baseline** —
which no pull-up can do — and noise 10 with slow drift. J1 is the power input;
with the board on the Nano's USB the 1N5817 isolates J1 from the rail, so the
resistor was tied to a node held only by two diodes' reverse leakage: a 10 kΩ
antenna on an open pin, swung by a hand *near* it. That is the V4 floating
keyboard of July, called unreadable then. *It moved* is not *it worked*. (Log
not preserved — overwritten before it was copied; the numbers are from the
analysis at the time.)

**Run 2, 10 kΩ to the Nano's 5V pin.** Baseline **1023, noise 0**, all seven.
Channel 1 best dip **14 counts**, typical 1–2. Log
`pcb/validation/probe-v0.7.1-R1-10k-on-rail-2026-09-13.txt`, first log with the
new self-describing header (`label: pcb`).

Solving the divider for the finger's contact resistance, per capture:

| rig / condition | pull-up | dip | contact |
|---|---|---|---|
| breadboard, "no ground" | 220 Ω | 8 | **28 kΩ** |
| breadboard, gripping USB shell | 220 Ω | 40 | **5.4 kΩ** |
| PCB, 10 kΩ on rail, best | 10 kΩ | 14 | **721 kΩ** |
| PCB, 10 kΩ on rail, typical | 10 kΩ | 1–2 | **5–10 MΩ** |

**Same finger, same grip: 5 kΩ on the breadboard, 0.7–10 MΩ on the PCB.** With
that contact, 220 Ω yields 0.02–0.3 counts — the zero of the last three days,
finally with a cause attached. The circuit and the value are no longer in
question; the contact at the header pin is. Two consequences: the breadboard's
"clipless" 28 kΩ cannot be capacitive at DC, so there was an accidental return
path (a finger on an exposed GND jumper tip — a breadboard has dozens), and the
finished piano in its box will behave like the PCB, not the breadboard; and with
the return path held equal, the 100× gap left is at the pin surface — J2 was
hand-soldered from below and rosin flux wicks up pins as an insulating varnish.

Next test is how the instrument is actually played: **alligator clips** on J2
pin 1 and pin 8, which bite through any film. Expected with 10 kΩ: ~660 counts
with a 5.4 kΩ body, ~270 with 28 kΩ. Review §2g has the full table and the
honest route to a clipless version (MΩ pull-ups + first-conversion discard +
the adaptive baseline the firmware already has — a V5.6 design, not a repair).

## 2026-09-13 (night) — a log that cannot say what it measured is not evidence

A capture arrived that could have come from either rig, and the two readings of
it were **opposite conclusions**: either the v0.7.1 board now has a correct 1023
baseline but a finger that cannot reach its pin at all, or it is a recording of
an untouched breadboard and means nothing. The file name (`pcb` / `proto`) is
only a label — `run.sh` records whatever is on `/dev/ttyUSB0`, and both Nanos
here are indistinguishable CH340s (`1a86:7523`, no serial number), so nothing in
the log identified the rig.

- `capture.py` now writes a header into every log: the **label the operator
  chose**, the timestamp, the port, the USB path (`ID_PATH`) and the window.
- `run.sh` passes the label through and shouts it before recording — *"RECORDING
  AS: 'pcb' — is THAT the rig on /dev/ttyUSB0?"* — with the warning that the
  filename is only a label and a mislabelled log proves nothing.

The USB path is the one thing that is at least *physically* meaningful: if the
two rigs live in two different sockets, two logs from the same socket are
provably the same rig. It does not identify the board, but it can falsify a
claim that two captures came from different ones.

## 2026-09-13 (evening) — the breadboard, measured: it works by two counts

The comparison never made in three days. Same probe, same body, same supply,
same USB cable. The three phases the operator described are visible in the
timestamps without being told: touch, a 20 s pause, touch again gripping the
Nano's USB shell.

| phase | ch1 | ch2 | ch3–7 (untouched) |
|---|---|---|---|
| touching, no ground | 1015 → **8 counts** | 1017 → **6 counts** | 1021–1023 |
| pause | 1023 | 1023 | 1023 |
| touching, holding GND | 994 → **29 counts** | 983 → **40 counts** | 1023 |

Against the v0.7.1 board's **0 counts in both conditions**, and a game margin of 4.

**The working rig fires without a ground clip by a margin of two counts.** That
reframes everything: this was never a robust design that the PCB broke. It is a
design with ~2 counts of headroom, and on the PCB it fell off the edge.

§2's arithmetic was right and its conclusion wrong in one specific way. 220 Ω
does give a usable signal — 6 counts, from a **28 kΩ** contact, because a
fingertip pressed hard on bare pin metal is not the megohm of a "dry finger".
Holding ground drops the contact to **5.4 kΩ** and buys 40 counts.

It does not convict the PCB yet: the same finger cannot be 5 kΩ on one rig and
>250 kΩ on the other, so either the boards differ in a way still unfound, or the
**gestures** were not the same — the PCB runs were "fruit, the pin, before and
after the resistor", and may never have included that exact grip on bare J2
metal. So the last experiment is a back-to-back with one variable: identical
gesture, identical finger, identical USB shell, on the board.

And one recommendation moves from theory to evidence: **220 Ω leaves 2 counts of
headroom on the rig that works.** Raising R1–R7 turns 6–8 counts into hundreds
and removes the ground clip from the equation. Still queued behind the
back-to-back, because a fix applied before the cause is known is a coincidence,
not a repair.

## 2026-09-13 (later) — the board is good, and a wire proved it in thirty seconds

A bare wire from J2 pin 1, then pin 2, to J2 pin 8 (GND), probe running:

| channel | range over 176 s | bridged? |
|---|---|---|
| 1, 2 | **1023 → 0**, full scale | yes |
| 3–7 | 1023 → 1022 at worst | no |

Full-scale swing on exactly the two bridged channels and nothing on the other
five. It proves end to end that `J2.n → Rn → A(n-1)` is continuous, that
`J2.8 → GND` is continuous, that the ADC resolves the whole range, and that the
channels do not cross-talk. Log in
`pcb/validation/probe-v0.7.1-jumper-2026-09-13.txt`.

**Every hypothesis that blamed the board is now dead** — routing, buzzer, stuck
buttons, missing pull-ups, bridged pull-ups, shorted key nets, an unsoldered
fruit header. The meter cleared the last of them: all seven key resistors read
220 Ω, and key-to-key reads ~440 Ω, which is R+R through the shared rail, i.e.
exactly the *expected* value for a healthy pull-up bank. (That ~440 Ω is also,
measured, the same observation the owner made on day one: "all the resistors
look joined to each other". They are, and correctly.)

Two incidental faults found and confirmed irrelevant: **R18 fitted as 220 Ω
instead of 10 kΩ** (only touches `/SENS_MINUS` and `/+5V`; identical behaviour
with the button up, and the button works), and **LED4 dead** (anode on D5, a
digital output sharing nothing with A0–A6).

**The method lesson, which is the expensive part.** This wire test costs thirty
seconds and should have been the first thing done — before any theory about
pull-up values, skin impedance or earth references. It substitutes a known
resistance for the human and turns an argument into a number. Instead two days
went into arithmetic that was correct and aimed at the wrong question: *is the
board able to see a key at all?* was never asked. Worse, every test that WAS run
used a finger, and a dry finger is ~1 MΩ — which reads 1023 on a perfectly
working board. Every one of those tests was incapable of producing a signal, so
none of them could ever have been evidence.

What remains is not on the board: the path from the header pin to the hand — the
fruit, the clips, the wire, the return to GND. And the one comparison never made
in three days is the probe on the **breadboard**.

## 2026-09-13 — the probe records to a file at last, and the board's answer

`pio device monitor` wraps pySerial's **miniterm**, which is an interactive
console: point its stdout at a pipe or a file and it writes **nothing**. So the
second run produced a **zero-byte log from a correctly flashed board** — the
board was printing perfectly and the recorder was the broken part, for the
second round trip running.

- **`probe/capture.py`** — reads the port with pySerial directly, timestamps
  every line, flushes per line (a killed run still leaves a usable log), and
  toggles DTR first so the log always opens on the boot block with the seven
  baselines in it.
- `probe/run.sh` uses it instead of `pio device monitor`.

**First real reading from the assembled board**, taken over SSH with the Nano
plugged into quantumpc:

```
  key 1  baseline=1023  noise=0
  key 2  baseline=1023  noise=0     ... all seven identical
keys:  1023(-0)  1023(-0)  1023(-0)  1023(-0)  1023(-0)  1023(-0)  1023(-0)
```

All seven channels **pinned at 1023 with exactly zero counts of noise**, held
flat for the whole window. Two things follow immediately, and the second one
closes a question this review had left open:

1. **R1–R7 are populated and connected.** A floating analog pin does not read a
   rock-steady 1023 — it wanders, and it drags the previous mux channel's
   residue with it (that is precisely what the V4 keyboard measurements looked
   like: "gradient ramps", 76–104 counts of noise, 170 counts of drift). Seven
   identical, immovable 1023s are the signature of a stiff pull-up doing its
   job. So "the resistors or the rail are missing" is dead, positively rather
   than by inference.
2. **Zero noise means the auto-margin is at its floor of 4**, which is the
   best case the firmware can offer. Nothing is mis-calibrated. The margin was
   never the problem.

The board is doing exactly what it was designed to do. That is the finding.

**Then the long run: 156.5 s, 1345 samples, seven channels, and the set of
distinct values seen on every one of them is `{1023}`.** Zero movement, both
directions, for two and a half minutes with the fruit being played. Log kept at
`pcb/validation/probe-v0.7.1-board-2026-09-13.txt`.

That is the *predicted* number. §2's table said 0.2–0.7 counts for a normal-to-dry
touch through 220 Ω, and an ADC cannot show a fraction of a count — so the
prediction was zero, and zero is what the instrument reports. Working backwards,
a reading of exactly 1023 means the hand → body → fruit path stays above
~250 kΩ, which dry skin does on its own.

And one consequence worth writing down plainly: **no firmware change can rescue
this board.** A 220 Ω path to the rail defeats the resistive divider (sub-count
signal) *and* RC-timing / `CapacitiveSensor` alike, because the node recharges
through 220 Ω in nanoseconds. The resistor has to physically come off.

The plan is now in §2d of the review, cheapest step first: **remove R1–R7, fit
nothing, measure again** — no new parts, and it settles what the breadboard is
doing without anyone having to describe it. Then fit 1 MΩ (already in the parts
drawer, top unit) and make `readKey()` discard its first conversion.

## 2026-09-12 (fix) — the probe flashed fine and printed to nobody

First real run on the board: upload SUCCESS on `/dev/ttyUSB0`, and then nothing.
The probe's `platformio.ini` declared two environments and no `default_envs`, so
`pio run -t upload` uploaded **twice** — the second one out of sync against a
board that had just been reset — the command exited non-zero, and the
`&& pio device monitor` chained after it never ran. A correctly flashed board
printed to nobody, and the round trip was spent on a bug of mine.

The second attempt then auto-detected `/dev/ttyS0`, the motherboard's own serial
port, and failed with "Permission denied" — which reads like a permissions
problem to go and fix, and is not one.

- `default_envs = nanoatmega328`, with the reason written next to it.
- `upload_port` / `monitor_port` pinned to `/dev/ttyUSB*`, so auto-detect can
  never wander onto `ttyS0` again.
- **`probe/run.sh`** — one command, one file: `./run.sh pcb` flashes, records a
  fixed window into `~/sonda-pcb.txt`, and prints the verdict lines at the end.
  If no `/dev/ttyUSB*` is present it says so in one line instead of failing on
  the wrong port. `./run.sh proto` does the breadboard.

The file matters as much as the fix: the board is flashed from quantumpc over
SSH, so the log lands on the machine the agent is already on — nobody has to
copy a screenful of serial output out of a terminal to be read.

## 2026-09-12 (later) — the bench answers back: the probe learns to look both ways

Three facts from Sergio with the board in his hands, and they delete two of the
three branches of this morning's review:

- **Every boot sound plays and both SENS buttons beep.** The buzzer branch is
  closed. So is the stuck-switch worry — the buttons respond, so SW1/SW2's pad
  grouping is right.
- SENS− is on A7 and works **only** through R18, a pull-up to `/+5V` in the same
  bottom-side row as R1–R7. That beep proves the 5 V rail reaches the key
  pull-ups, with no meter. "The rail or R1–R7 are missing" is closed too.
- **He never touches a clip.** On the breadboard, with the same 220 Ω, he touches
  only the fruit, calibrates, and it plays.

Buzzer, buttons, LEDs and rail alive; exactly one block dead. And the third fact
does not fit this board at all: a 220 Ω pull-up is a stiff node, so a body that
is not galvanically tied to circuit GND couples nanovolts into it. Clipless play
cannot work on the v0.7.1 front end — not by four counts, by four orders of
magnitude. The working rig must have a **high-impedance** key node: either the
V4/V4.5 front end (pin floating, the 220 Ω in *series*, touch reads **UP**) or an
earth reference through an earthed PC's USB. Same resistor value in both, which
is exactly why "the same values work on the breadboard" was never evidence of the
same circuit.

Also answered, because it was a fair objection: *"pressing both buttons should
auto-calibrate whatever the value is — it has range."* It does; `MARGIN_MAX` is
600. The range is not the problem, the **direction** is. `learnFromTouch()`
tracks `lo[]` only, and clamps `dropped[i]` to 0, so an upward touch scores zero
on every channel and the gesture reports "not separable from noise — margin
unchanged" forever. `autoCalibrate()`, `keyTouched()` and `strongestKey()` all
look down too. A one-directional search cannot be widened into a two-directional
one.

So the probe is now **direction-agnostic**: it reports the largest excursion
since boot **both ways** and prints a one-line verdict — signal DOWN (this
board's polarity, tune the margin), signal UP (wrong front end, and no
calibration gesture will ever find it), or nothing moves (no signal to
threshold). A probe that only looked down would have hidden the very thing it
was flashed to find. Builds clean.

The protocol in the review is now one experiment with two runs: the same sketch
on the **board** and on the **working breadboard**, comparing the sign. Only one
of the four outcomes puts the fault back inside the PCB, and it is named. Plus a
free test in the same session — power the board from an earthed PC instead of a
charger, since V5.5's own powering rule ("never the PC's 5 V") is what would have
removed the earth path that makes clipless play work.

Nothing desoldered, no values changed, V5.6 still unwritten: it waits on the two
runs.

## 2026-09-12 — V5.5 wiring diagram: every part labelled with its PCB v0.7.1 reference designator

- **Why**: the V5.5 breadboard is built and the PCB exists, so a part has to be
  findable on both. The diagram previously showed values only (`470 µF`,
  `220 Ω`), which cannot be matched to a board silkscreen.
- **`build_v5_5()`** in `tools/wiring_diagrams.py` now labels all 42 parts with
  the designator from `pcb/docs/NETLIST.md`: `J1 D1 D2 C1 C2 L1 C3 C4`
  (filter), `R1..R7` (key pull-ups, R1 = A0 = KEY1), `D3..D12` + `R8..R17`
  (LED bar), `BUZ1 SW1 SW2 R18` (UI) and `R19 R20 C5` (the off-board amp).
  Values move to the legend where a part has only one text slot.
- **LED bar now carries BOTH numbers**, because they are off by one and that is
  the easiest mistake to make: the bold ref is the PCB designator `D3..D12`,
  the small line under it is the Arduino pin `D2..D11` that drives it.
- **LED colours now match the PCB VU meter** (3 green, 3 yellow, 2 orange,
  2 red per ADR-021) instead of ten green, verified by sampling the rendered
  pixels at the bar centres.
- **`keyboard_2019()` gains `refs=False`** so only V5.5 opts in. Re-rendering
  all ten revisions changed **only** `wiring-v5.5.png`; V1, V2, V2.5, V3, V5
  and V6 are byte-identical.
- The legend gains the PCB cross-reference: the keys land on `J2` (pin 8 = `G`,
  the hand-held clip), `J3`/`J4` parallel the SENS buttons, `J5` is where the
  amp plugs in, `U1`/`U2` are the Nano's socket rows, `H1..H4` the M2 holes.
  It also states the two physical differences: the PCB runs the LED bar the
  other way round (LED1/D3 at the EAST end), and the amp stage is off-board.
- The SENS buttons keep their `SW1`/`SW2` hardware labels; the FREE PLAY /
  MODE WHEEL roles added on 2026-09-09 are firmware on the same two buttons,
  no wiring change.
- `versions/v5.5-power-filter/HARDWARE.md` gains the full designator table.
- **Verification**: 64 nets, **0 spacing warnings, 0 hard violations** (the
  wirewright DRC treats label boxes as obstacles, so it is what proves the new
  longer labels do not collide); all ten diagrams re-rendered clean; label
  text dumped from the built schematic to confirm all 42 designators are
  actually drawn.

## 2026-09-12 — v0.7.1 assembled and silent: review, board probe, doc correction

The real PCB arrived, was assembled, and plays nothing — touching a lemon or an
A-pin directly produces no note, on several power supplies, while the Nano boots
and the LED bar runs. The owner suspected a design fault, having noticed that on
the board every key resistor looks joined to every other.

**The copper is not the fault.** `pcb/kicad/lemon-piano.kicad_pcb` was re-derived
independently of the design tooling — pads parsed out of the footprints, tracks
joined geometrically, the B.Cu pour treated as the GND node. All 34 nets are one
connected island each, no net is split, no island carries two nets, no non-GND
copper falls inside the pour, and the Nano socket rows map pin-for-pin onto the
real Nano. KiCad 9.0.9 DRC agrees (0 violations, 0 unconnected). The resistors
that look joined *are* joined, correctly: R1–R7 share `/+5V`, R8–R17 share the
GND pour.

Which means DRC never answered the question being asked. **DRC checks the copper
against the netlist; it cannot check the netlist against the intent.**

**The fault is the front end, and it was in the file all along.** The touch
signal on this board is **4 ADC counts out of 1023**: a 220 Ω pull-up against
skin only fires if the entire hand → body → fruit → clip path stays under
**56 kΩ**, and dry-skin contact alone is routinely 100 kΩ–1 MΩ. One extra count
of measured noise pushes `max(4, 2 × noise)` above the whole signal and the board
goes silent exactly as reported. `versions/v5-led-bar/HARDWARE.md` already named
the fix in its last paragraph and did not take it.

Added:

- **`pcb/docs/REVIEW-v0.7.1-silent-keys.md`** — the review: the connectivity
  evidence, the signal budget as a table of pull-up against body resistance, the
  buzzer branch as the cheaper thing to rule out first (the firmware plays a
  fireball, seven coins and a power-up sweep *before* any lemon is touched, so
  "silent at boot too" and "silent only on touch" are different faults), and a
  proposed V5.6: R1–R7 at 220 kΩ plus a discarded first ADC conversion.
- **`versions/v5.5-power-filter/firmware/probe/`** — a standalone PlatformIO
  project that turns "it does not sound" into numbers: beeps D13, prints every
  channel's baseline, then all seven channels at 10 Hz with the largest
  excursion since boot. Builds clean (5242 B flash, 269 B RAM). The game build's
  `-DDEBUG_TOUCH` cannot do this — it logs only *accepted* presses, so it says
  nothing when nothing is ever accepted.

Corrected — **two documents disagreed with the board, the firmware and
themselves**, and were being read as ground truth while the board sat silent:

- `versions/v5-led-bar/HARDWARE.md` "Touch sensing" claimed "pins float near 0,
  the +5 V clip through the body raises the reading,
  `threshold = baseline + max(40, 3 × noise)`" — V4.5's front end, copied forward
  and never updated, three paragraphs below the measured section that says the
  opposite.
- `docs/HARDWARE.md` filed V5 under "2026 boards — the clip is on +5 V" in the
  prose, the polarity table and the calibration section.

Both now say what `main.cpp` does: `threshold = baseline − max(4, 2 × noise)`,
pins pulled **up**, player on **GND**, touch drags **down**.

Nothing was changed on the board or in the game firmware: V5.6 waits on the
measurements, because the buzzer branch may turn out to be the whole story.

## 2026-09-09 — V5.5 firmware: FREE PLAY and the MODE WHEEL (no hardware change)

Requested by the owner with the board unplugged: *"diseña todo el software y
valídalo para que cuando pueda pueda cargarlo en el Arduino"*. Everything below
is firmware and docs. **V5.5 only** — V5 is untouched and still builds; the two
firmwares were byte-identical until today and have now deliberately diverged.

**FREE PLAY** — the piano with the game removed, and the fifth item on the wheel.

- The seven lemons become **do re mi fa sol la si** (C5 D5 E5 F5 G5 A5 B5): a
  fifth row in `keys[]`, so the existing `(level-1)*KEY_COUNT` offset addresses
  it with no new indexing. Deliberately not one of the level rows — those are
  puzzle alphabets (level 3 carries a C♯, level 4 skips B) and someone sitting
  down at a piano expects the notes they were taught at school.
- **The same lemon may be played over and over.** The game's `lastSoundedKey`
  lock — which exists because flaky fruit contact used to machine-gun both the
  buzzer and the guesses — is exactly backwards for an instrument, so free play
  takes a short path out of the press handler before it. `handleGuess()` returns
  immediately in free play as well, belt and braces: nothing is ever scored,
  nothing is ever wrong.
- The LED bar changes job: a **pitch meter** while a note sounds ((key+1)·10/7,
  so seven keys use all ten LEDs), and **only its two ends lit** when idle — a
  shape the game's left-filling bar cannot produce.
- It is **not a level**. The win path advances `level` against `LEVEL_COUNT`, so
  the cycle stays 1→2→3→4→1 and never lands here. It can only be chosen.

**THE MODE WHEEL** — the game-select switch V5 removed, back as a gesture.

- **Hold − for 3 s** to open. From 1 s the bar becomes a charge meter and a chirp
  climbs 3300→4700 Hz with it, so the gesture announces itself before it fires;
  release early and a bump says "cancelled".
- **+ / − turn it**, five items, **wrapping both ways**. Each stop previews the
  opening of its own theme (capped at 8 notes) and shows itself: **level n = n
  LEDs blinking**, free play = **one LED running**. Blinking is a question,
  steady is a score, motion is neither. A preview is aborted the instant the
  wheel turns again, so browsing runs at the speed of the hand.
- **Both buttons at once accepts**, in either order with any overlap.
- **Long-press either button, or wait 20 s, to leave** — the game keeps its level
  and its progress bar. The wheel opens on the mode being played, so opening and
  immediately accepting is a no-op.
- Three new non-Mario cues (`sfxMenuOpen`/`Close`/`Accept`) — open rises, close
  is the same three notes falling. Documented in `docs/MARIO-SOUNDS.md`.

**The overlaps, which is where this kind of thing normally goes wrong.** Three
gestures now share two buttons. The decision layer was lifted out of `main.cpp`
into **`firmware/include/ui_gestures.h`** — plain C++, no Arduino — and the four
collisions are named and resolved at the top of that file:

1. *− is both the knob and the menu key.* The sensitivity ramp is **capped at
   1 s**; past that the button is arming the menu. And if the hold becomes a
   menu-open, the margin is **restored to its value when the button went down** —
   reaching for the menu must not quietly desensitise the keyboard on the way in.
2. *Accept vs navigate.* In the menu, navigation fires **on release**, so the
   first of two buttons cannot step the wheel before the second lands. No
   coincidence window is needed at all.
3. *Accept vs smart adjust.* Different states; holding − for 3 s never fires
   smart adjust and holding both never opens the menu.
4. **The one that nearly shipped:** press +, then − on top of it, then release +.
   With "when − went down" as the clock, that release opened the menu on the
   spot — no meter, no warning, a two-finger fidget turning into a mode change.
   The clock is now *when − became the only button down*. Found by writing the
   state machine's own doc comment; it has its own test case.

**Verification** — the board is unplugged, so none of this was tested on it:

- `pio run` green on **all five envs** (a new `emulation-freeplay` env joins
  them): 537 B RAM (26.2 %), 15 450 B flash (50.3 %), up from 487 B / 12 142 B.
- **`firmware/test/run.sh` — 97 + 56 checks, 0 failed.** Two host binaries, plain
  `g++`, no Arduino and no Docker: `ui_gestures_test` drives the button state
  machine through every overlapping timeline (including the 7 ms loop rate the
  AVR really runs at, and contact bounce), and `piano_sim_test` compiles **the
  real `src/main.cpp`** against a fake board (`test/arduino/Arduino.h`) and plays
  it — note mapping, five repeats of one lemon, the wheel reaching every mode and
  wrapping, cancel changing nothing, accept starting clean, the margin restore,
  and winning never landing on free play.
- **Mutation-checked**, because a check that cannot fail proves nothing: breaking
  the free-play scale, deleting the margin restore, and moving the arming line
  each turn the suite red, on the assertion that names them.
- `emulation/piano-mode.yaml` written for free play (`-DSTART_IN_FREE_PLAY`,
  since the browser has no pins left for the two buttons) — **parses and
  compile-checks, but has never been run**: the Velxio harness is not installed
  on this machine. The mode wheel itself is **not emulatable here at all**, by
  the same pin exhaustion; that is why the host tests exist.

**Docs**: new printable instruction sheet `docs/USER-GUIDE.md` and its Spanish
translation `docs/GUIA-DE-USO.es.md` (the repo is English; what gets printed is
read by people who speak Spanish). V5.5's README grows the full gesture map and
an honest verification table; the root README's "how it plays" section was
**stale** — it still described the A7 game-select switch and the D7 restart
button, both gone since 2026-07-28 — and has been rewritten.

## 2026-09-06 — PCB v0.7.1: "Created with ♥ by Multitec." maker's mark (cosmetic)

- **Silk-only, PATCH bump** (v0.7.0 → v0.7.1, per the repo's version rule). No
  footprint, pad, net, hole or outline change: the placements, netlist,
  schematic and every physical gate are the v0.7.0 board unchanged — only
  F.SilkS grew (ADR-038).
- A large **"Created with ♥ by Multitec."** fills the ~39 × 16 mm free
  rectangle the USB-west flip left in the top-left / west block (below the
  C1/C3 caps, above D2/L1, left of the socket, across the left anchor the user
  said to use). Two left-justified lines at 3.5 mm height, 0.40 mm stroke:
  `Created with ♥` / `by Multitec.`.
- **The heart is a filled silk polygon, not a character.** KiCad 9's stroke
  font has no U+2665 glyph — a literal "♥" renders as a tofu box (verified by
  plotting F.Silkscreen with kicad-cli 9.0.9) — so it is drawn as a `gr_poly`
  from the classic heart parametric, scaled to the text height, y negated so
  the point sits at the bottom (KiCad's +Y is down).
- The **left anchor divider** is broken into two segments around the text band
  (y 113.5..124.0) so the line does not cross the letters; the right divider
  stays full.
- **Verification**: cloud `/drc` 0 errors / 0 warnings / 0 unconnected; ERC
  0/0; verify_placement 74 OK, verify_holes (+vision) PASS, geometry_gate
  30/30 — all identical to v0.7.0 because the board is; plus a numeric silk
  check (heart present, both lines on F.SilkS, zero silk over any pad). Release
  `pcb/releases/v0.7.1/lemon-piano-v0.7.1-fab.zip`; renders + 3D + INDEX.md
  regenerated.

## 2026-09-06 — PCB v0.7.0: Nano turned back to USB-WEST for enclosure cable access (LEDs north, keys south)

- **User request** (annotated screenshot of the v0.6.0 render): flip the
  Arduino so the mini-USB points the other way, away from the SENS buttons, so
  the cable can be plugged into the PC **with the Nano seated** once the
  enclosure exists; D2 and L1 moved to leave room for the cable; and, because
  the flip changes which pins face which edge, the LEDs go to the top and the
  key connector to the bottom.
- **What changed on the board** (`pcb/lemon-piano.yaml`, `pcb/tools/build_board.py`,
  `pcb/tools/geometry_gate.py`):
  - `U1`/`U2` trade places (ADR-035): U1 analog = SOUTH row, pin 1 D13 west
    (rot 90); U2 digital = NORTH row, pin 1 TX1 east (rot 270). D12/D13 flank
    the USB at x=132.22. Pin legends, refs and the B.SilkS title moved with it.
  - **LED bar → NORTH edge**, centred, **LED1 at the EAST** (D3 170.7 … D12
    129.3, rot 270 so anodes point south). **Keys header → SOUTH edge**,
    centred, **KEY1 at the WEST** (`KEYS 1 2 3 4 5 6 7 G`). Both follow the pin
    order for a non-crossing fan (ADR-036) — the mock-up had pasted the v0.6.0
    blocks unchanged; honouring that literally would have meant a 45-crossing
    via crossbar under the digital row. **Consequence: the VU meter fills
    right→left with the USB on the left.** Reversing it is a YAML change plus
    a re-route.
  - **USB-cable corridor reinstated** (x < 130.4, y 113..127 part-free on
    F.Cu — the ADR-024 band; supersedes ADR-030). `geometry_gate` checks it
    against real courtyard boxes. The v0.5.0–v0.6.0 "lift the Nano to flash
    it" cost is gone.
  - **Filter folded around the corridor** (ADR-037): C1 ‖ C3 stay adjacent on
    the north row; D2 → (107.0, 129.2) rot 180, J1 → D1 at y=136.0, L1 in its
    own column at (120.0, 134.5). Four parts do not fit one 27 mm row and L1
    cannot stack over D1 in the 13 mm strip, hence the column. `/VRAW` and
    `/+5V` now run ≈ 30 mm north–south side by side (accepted, same reasoning
    as ADR-031).
  - Both geometric-0805 groups inverted their pad numbers again (the ADR-029
    trap): builder assertions moved to KEY pad y=125.4 / cathode pad y=101.97,
    `ground-truth/components.yaml` re-derived from the built board.
- **Verification**: cloud `/drc` **0 errors / 0 warnings / 0 unconnected**;
  ERC 0/0; `verify_placement` 74 OK; `verify_holes` geometric + vision PASS
  (max LOO 0.022 mm); `geometry_gate` 30/30 incl. the new corridor check; an
  independent logical pass over the routed `.kicad_pcb` (pin→net map, both
  fans monotonic, zero pads in the corridor, copper on all 34 nets, legend
  order); all eight renders inspected (overlay photo lands USB-west, every
  part has a 3D body); `build_board` byte-identical across two runs. First
  pipeline run stopped at `verify_placement` exactly as AGENT_PROMPT step 2
  predicts (0805 pad inversion); no board change was needed to fix it.
- **Release**: `pcb/releases/v0.7.0/lemon-piano-v0.7.0-fab.zip` (14 files),
  produced by `/fab` on the very board the gates passed on (not a `--fab`
  re-route, so the release matches the committed `.kicad_pcb`). 3D models
  `pcb/3d/lemon-piano-v0.7.0.{glb,step}` committed. Renders under
  `pcb/renders/v0.7.0-*`, `renders/INDEX.md` regenerated.
- **Docs**: ADR-035/036/037 in `pcb/docs/DECISIONS.md`; `NETLIST.md` board
  frame + pin map (USB-east map kept as history); `DESIGN_STATE.md`;
  `pcb/README.md` (assembly notes: cable corridor, G pin now east, VU
  direction); `AGENT_PROMPT.md` board facts; `overlays/modules.yaml` and
  `ground-truth/holes.yaml` comments/version.
- **Toolchain note**: the local `eda-pcb-designer:latest` Docker image was
  absent on this machine and was rebuilt from the sibling repo (`docker build`,
  ≈5 GB) — no toolkit code changed.

## 2026-09-06 — V5.5: add the amplified speaker that was missing from the diagram

- **`build_v5_5()`** in `tools/wiring_diagrams.py` — the V5.5 wiring diagram was
  re-rendered (same file, `versions/v5.5-power-filter/images/wiring-v5.5.png`,
  **not** a new version) to include the **LM386 amplifier + 4 Ω 3 W speaker**
  that the schematic had left out. 64 nets, DRC 0 violations. The audio stage is
  wired exactly as in the V6 proposal: `D13 → 10 kΩ / 1 kΩ divider (≈ ÷11) →
  1 µF DC block → LM386 IN → 4 Ω speaker`, with the on-board piezo still in
  parallel on D13.
- **The amp is fed from the *unfiltered* 5 V (`vin`, before the TVS/Schottky)**,
  never the filtered rail: an LM386 into 4 Ω pulls hundreds of mA at audio rate,
  and that current crossing the CLC pi would modulate AVcc — the ADC reference
  the 3–4-count (15–20 mV) touch margin is measured against. Accordingly the
  `+5 V` rail now **stops short** of the amp (`v5_x1=2850` on `_board`) instead
  of spanning the canvas, and the canvas widened to 4200×2080 to hold the audio
  block on the right.
- `versions/v5.5-power-filter/README.md` — hardware-delta section, title and the
  verification net count (58 → 64) updated so the doc matches its own diagram.
- **Known doc debt, deliberately left for a `replantear` pass:** the V6 proposal
  still lists the LM386 + speaker as *its* delta vs V5.5, and V5.5's
  `HARDWARE.md` / `CLAUDE.md` / `versions/README.md` still describe V5.5 as
  "V5 + filter, buzzer unchanged". Reconciling the V5.5↔V6 boundary (e.g. V6 =
  battery-only) was explicitly out of scope for this change.

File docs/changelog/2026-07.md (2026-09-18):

# Changelog archive: 2026-07

Entries moved here verbatim from `CHANGELOG.md` by `qpc-changelog-archive`.
Nothing on this page has been reworded; `--verify` checks that against a
SHA-256 taken before the split. Newest first, as in the original.

---

## 2026-07-31 (pcb/) — rotatable 3D models in the pipeline

- The pipeline now emits a **rotatable 3D model** of the board on every run,
  via the new `POST /export3d` endpoint in eda-pcb-designer 0.4.0:
  `pcb/3d/lemon-piano-<ver>.glb` (browsers / `f3d`) and `.step` (CAD). The
  cloud does it because the service image ships the `kicad-packages3d` body
  library that the slim local Docker image deliberately omits — a local export
  would silently drop every component body.
- `pcb/3d/*.glb` and `*.step` are **committed** (2026-07-31), so cloning the
  repo is enough to look at the board — no KiCad, no Docker, no pipeline run.
  Cost, stated plainly: ~16 MB of binaries per version, permanent in git
  history. Only `pcb/3d/models/` stays untracked (fetched third-party KiCad
  body files, re-downloadable in seconds). They do not preview on github.com:
  GitHub renders only `.stl` inline and only up to 10 MB, and this board's STL
  is 34 MB — measured, not assumed.
- `pcb/tools/export_3d.sh` does the same offline, fetching just the ~15 bodies
  this board needs (~1.4 MB, cached). Its only fidelity gap: the orange LED
  body does not exist upstream, so D9/D10 come out red locally and orange from
  the cloud.
- README gains a "Look at the board in 3D" section: <https://3dviewer.net>
  (drag-and-drop, renders in-browser, nothing installed), `sudo apt install
  f3d`, and the KiCad-9 PPA route — noting that Ubuntu's own repos carry only
  KiCad 7, which cannot open this v9 board.
- Not a release gate: if `/export3d` fails the pipeline warns and carries on,
  because a viewing aid must never block electrically-verified outputs.
- **`.vscode/extensions.json`** recommends `thingraph.cad-viewer`, so VS Code
  offers to install it on first open and the `.glb`/`.step` open in a rotatable
  tab on double-click. Chosen over the 100×-more-popular `cesium.gltf-vscode`
  ("glTF Tools") because that one registers no viewer for `.glb` — it is a
  format validator/converter, so you would have to import to `.gltf` first.
  Verified from the extension manifests, not the marketplace descriptions
  (CAD Viewer's page contradicts itself on STEP; its bundled
  `occt-import-js.wasm` settles it).

## 2026-07-31 (pcb/) — v0.6.0: J5, aux speaker output in parallel with the buzzer

- **New 2-pin header J5 (`SPK`)** on the same two nodes as the buzzer — pad 1
  on `/BUZZER` (the D13 drive line), pad 2 on `/GND` — placed immediately west
  of BUZ1 (5.18 mm courtyard gap). Same pattern as the SENS external-button
  headers: nothing is switched or cut, the on-board buzzer keeps working and
  whatever is plugged into J5 sees exactly the same signal.
- **Load limit, documented on the board's README and in ADR-034.** D13 drives
  a *passive piezo* directly ("no series resistor needed",
  `versions/v0-buzzer/HARDWARE.md`), which is a high-impedance load. A bare
  4–8 Ω voice coil at 5 V would ask ~600 mA against the ATmega328P's 40 mA
  absolute maximum per pin and would damage the pin. J5 therefore suits
  another piezo or an **amplified** speaker module; a raw speaker needs an
  amplifier. No driver stage was added to the PCB — the `versions/` tree
  defines a directly-driven passive buzzer, and inventing parts the sources
  do not specify is against the project's rules.
- Fixed a pre-existing documentation error spotted while editing NETLIST.md:
  the U1/U2 rows in the component table had their descriptions swapped (U1 is
  the *analog* column, U2 the *digital* one — the pad→net tables and the
  ground truth were always right).
- `geometry_gate` gains a check that J5 stays adjacent to the buzzer it
  parallels. verify_placement now covers 74 pad↔net↔function pairs.

## 2026-07-30 (pcb/) — v0.5.1: D1's missing 3D body (Kathode/Cathode filename split)

Cosmetic-only fix, user-reported ("¿por qué D1 no está renderizado?").

- **D1 had no 3D body in any realistic render** — bare pads and silk only,
  while D2 beside it rendered fine. Cause: KiCad 9's
  `D_DO-15_P5.08mm_Vertical_KathodeUp` footprint references a STEP of the
  same name, but kicad-packages3D ships that body spelled the English way,
  `..._Vertical_CathodeUp.step`. The footprint kept the legacy German-ish
  "**K**athode"; the 3D library moved to "**C**athode". `kicad-cli pcb
  render` skips models it cannot resolve **silently** — no warning, no DRC
  item, no build error — so it went unnoticed from v0.3.0 (first release with
  3D bodies) through v0.5.0. D2 is fine because its footprint and model names
  agree (`..._AnodeUp`).
- Fixed by pointing D1 at the file that exists, reusing the per-footprint
  model override already there for the coloured LEDs: `LED_MODELS` is folded
  into a general `MODEL_OVERRIDES` table, and the override loop now raises if
  a target footprint has no `(model ...)` block, so a future library change
  fails loudly instead of silently reverting to no body.
- **No effect on fabrication.** 3D models play no part in gerbers, drill,
  BOM, position files, netlist or DRC, so v0.5.0's fab package was never
  wrong — only its renders were incomplete. PATCH bump per the version rule.
- Audited all 44 model paths the board references against upstream
  kicad-packages3D while in there. Three more are absent upstream but resolve
  on the render host and render correctly, so no action:  L1's Fastron choke
  and the two `LED_D3.0mm_Orange.step` bodies (service-shipped, ADR-021).
  D1 was the only broken reference. ADR-033.

## 2026-07-30 (pcb/) — v0.5.0: Nano flipped (USB east), keys north, LEDs south, filter refactored

Second pass on the 120 × 40 mm board, to the user's follow-up spec. Circuit
unchanged again — this is all orientation and placement.

- **The Nano is flipped 180°: mini-USB now faces EAST** (ADR-029). This is
  the load-bearing change, and it is what "keys up, LEDs down" *requires*:
  the module's analog and digital columns sit on opposite long edges, so the
  only way to swap which board edge they face is to rotate the module. `U1`
  (analog) becomes the NORTH row with pin 1 (D13) at the east; `U2`
  (digital) becomes the SOUTH row with pin 1 (TX1) at the west.
- **Keys header on the NORTH edge**, still centred (pin centre exactly
  x=150), with pin 1 = KEY1 at the EAST because A0..A6 now descend
  west→east. Silk reads `KEYS G 7 6 5 4 3 2 1`, and the GND clip moved to
  the west end of the header.
- **LED bar on the SOUTH edge, centred on x=150**, ascending west→east
  (LED1 west under D2, LED10 east under D11) — the mirror of the old order.
- **Both 0805 resistor groups inverted their pad numbers.** The builder nets
  them geometrically, so the pull-ups (now south of a north analog row) and
  the LED resistors (now north of a south bar) both swapped which pad
  carries which net. `ground-truth/components.yaml` was re-derived from the
  built board, and two new builder assertions pin the KEY pad at y=114.6 and
  the LED cathode pad at y=138.03 so this cannot drift silently.
- **USB-cable keepout dropped** (ADR-030) at the user's explicit request.
  Trade-off, stated plainly: the USB shell now reaches x≈173.3 with SW1's
  courtyard starting at 173.48, so **flashing means lifting the Nano out of
  its socket**. That is the direct cost of keys-north + LEDs-south.
- **Filter section refactored** into a compact 3-row west block (ADR-031)
  now that the corridor no longer punches a hole through it: **C1 ‖ C3
  adjacent** on the north row as asked, D2 → L1 on the middle row with their
  pads 5.5 mm apart, J1 → D1 on the south row. Both bulk caps are now ~13 mm
  from the choke instead of C3's old 30 mm trip across the board.
- The flip also shortened two long v0.4.0 runs for free: `/BUZZER` from
  ~58 mm to ~20 mm and `/SENS_PLUS` from ~43 mm to ~8 mm, because D13 and
  D12 moved to the east end next to the buzzer and the SENS+ button.
- **post_route bugfix** (ADR-032): `repair_split_nets` laid its bridge tracks
  *after* the GND zone was filled, so the fill never made room for them —
  the first v0.5.0 run reported two `clearance 0.2 mm; actual 0.0000 mm`
  errors on the +5 V pull-up bus. It now returns a bridge count and the
  caller refills when it is non-zero. This was latent since v0.2.0; v0.4.0
  only escaped it because its bridges happened to land off the fill.
- Title block moved to the SE quadrant (the north edge belongs to the keys
  header now). `geometry_gate` grew to 24 checks: flip orientation, keys
  north + KEY1-east, LED bar south + centred + west→east order, and C1/C3
  adjacency.

## 2026-07-30 (pcb/) — v0.4.0: 120 × 40 mm remake, centred Nano, external-button headers

Complete floor-plan remake on a bigger board, to the user's distribution
spec. Same V5.5 circuit — no value, pin or part invented; only the board
interface grew.

- **120 × 40 mm frame** (was 100 × 30), KiCad frame x 90–210 / y 100–140.
  Anchor dividers at x=100/200; the four M2 holes move to the corners at
  5 mm insets (95/205 × 105/135), still mirror-symmetric about both axes.
- **Nano socket centred on the board** (pin field x 132.22–167.78, rows
  y 112.38/127.62), mini-USB still facing WEST. Centring it turned the USB
  corridor from a 14 mm sliver into a 42 mm strip, so the corridor is now
  defined as the band a cable actually needs — x < 130.4, y 113–127 — kept
  completely part-free and checked against real courtyard boxes.
- **Whole 5 V filter in the west block, folded around that corridor**:
  VIN section on the south strip (J1 → D1 → D2), VRAW/+5 V on the north
  strip (C1 → L1), output reservoir C3 at the south-strip east end. Three
  Ø8 mm radial parts do not fit in one 27 mm strip, which forced the split.
  D2 is placed at rot=180 so the chain reads west→east with no doubling
  back (first use of that rotation here; the pad assertions lock it).
- **5 V entry is now a 2-pin 2.54 mm header** (J1), replacing the Phoenix
  screw terminal — the user asked for "2 pines". Same nets, same polarity.
- **A parallel 2-pin header per SENS button** (J3 ∥ SW1 on /SENS_PLUS,
  J4 ∥ SW2 on /SENS_MINUS), so an external panel button can be plugged in
  without cutting a trace. Each sits directly east of its button.
- **Lemon-key header centred** on the south edge (pin centre exactly
  x=150); **SENS button pair centred** on the y=120 mid-line; **LED bar**
  centred over the D2–D11 pin span so the fan legs stay short at both ends.
- **Buzzer in the NE corner** — the only place its 12.56 mm courtyard fits
  once the button column and external headers claim their x-lanes.
- Title block moved into the USB corridor (the south edge belongs to the
  keys header now). `geometry_gate` rewritten: 23 checks including the new
  centring and corridor rules.
- **Green on the first pipeline run**: DRC 0 errors / 0 warnings /
  0 unconnected, ERC 0/0, verify_placement + verify_holes (vision ran,
  max LOO 0.0222 mm) + geometry_gate ALL PASS. Fab zip:
  `pcb/releases/v0.4.0/`. ADR-024..028.
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

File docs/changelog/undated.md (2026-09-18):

# Changelog archive: undated

Entries moved here verbatim from `CHANGELOG.md` by `qpc-changelog-archive`.
Nothing on this page has been reworded; `--verify` checks that against a
SHA-256 taken before the split. Newest first, as in the original.

---

## theme, VU-meter colours in the emulator

Two owner-requested LED/timing changes:

- **Calibration now fills all ten LEDs, not seven.** Only seven keys exist, so
  the old one-LED-per-key loop never lit LEDs 8-10. `lit = (key_index+1) ×
  LED_COUNT / KEY_COUNT` spreads the seven measurement steps proportionally
  across all ten (1,2,4,5,7,8,10 — uneven but always ends at ten), and a new
  `CAL_STEP_PAUSE_MS` (150 ms) pause per key — after its coin, not touching
  `CAL_SAMPLES` so measurement quality is unchanged — makes the count-up read
  as deliberate instead of a blur. Calibration now takes ~1.05 s longer.
- **The win theme now progressively fills the bar instead of flashing it.**
  `playSong()` gained two optional parameters, `ledTotal`/`ledOffset`: when
  `ledTotal > 0` the bar accumulates LEDs (0 to LED_COUNT, staying lit note to
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

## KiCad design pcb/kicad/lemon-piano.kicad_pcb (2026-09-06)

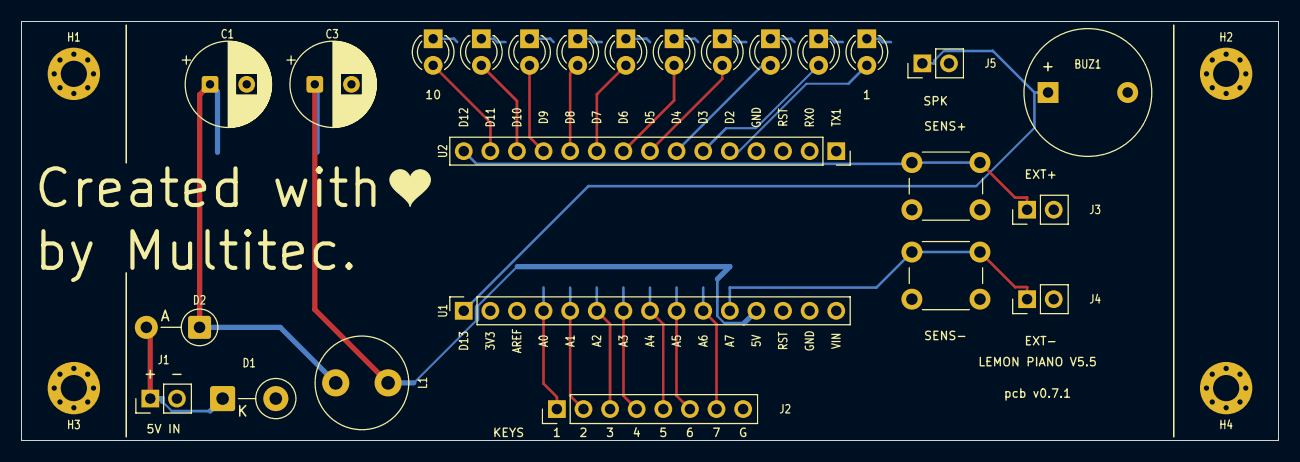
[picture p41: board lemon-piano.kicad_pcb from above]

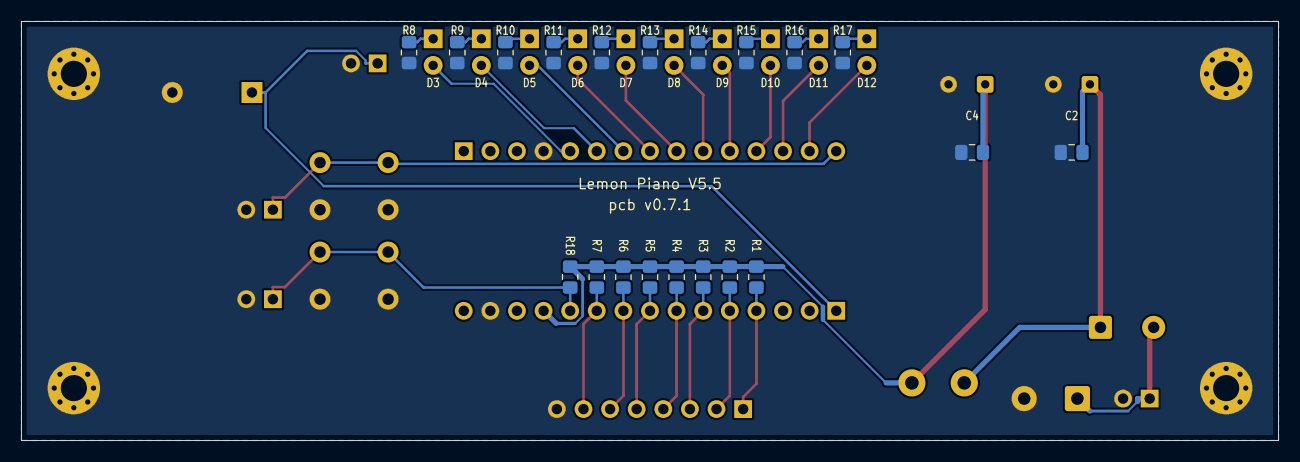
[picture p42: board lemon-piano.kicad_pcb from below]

Board: 2 copper layers, 120.0 x 40.0 mm, 49 parts (20 on the bottom side), 34 nets.

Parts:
BUZ1: passive_buzzer; Buzzer_12x9.5RM7.6
C1, C3: 470uF/16V; CP_Radial_D8.0mm_P3.50mm
C2, C4: 100nF; C_0805_2012Metric_Pad1.18x1.45mm_HandSolder
D1: P6KE6.8A; D_DO-15_P5.08mm_Vertical_KathodeUp
D2: 1N5817; D_DO-41_SOD81_P5.08mm_Vertical_AnodeUp
D3, D4, D5: GREEN; LED_D3.0mm
D6, D7, D8: YELLOW; LED_D3.0mm
D9, D10: ORANGE; LED_D3.0mm
D11, D12: RED; LED_D3.0mm
H1, H2, H3, H4: M2; MountingHole_2.5mm_Pad_Via
J1: 5V_IN; PinHeader_1x02_P2.54mm_Vertical
J2: LEMON_KEYS; PinHeader_1x08_P2.54mm_Vertical
J3: SENS+_EXT; PinHeader_1x02_P2.54mm_Vertical
J4: SENS-_EXT; PinHeader_1x02_P2.54mm_Vertical
J5: SPK_OUT; PinHeader_1x02_P2.54mm_Vertical
L1: 100uH; L_Radial_D8.7mm_P5.00mm_Fastron_07HCP
R1, R2, R3, R4, R5, R6, R7, R8, R9, R10, R11, R12, R13, R14, R15, R16, R17: 220; R_0805_2012Metric_Pad1.20x1.40mm_HandSolder
R18: 10k; R_0805_2012Metric_Pad1.20x1.40mm_HandSolder
SW1: SENS+; SW_PUSH_6mm
SW2: SENS-; SW_PUSH_6mm
U1: Nano_socket_A; PinSocket_1x15_P2.54mm_Vertical
U2: Nano_socket_B; PinSocket_1x15_P2.54mm_Vertical

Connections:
/+5V: C3.1, C4.1, L1.2, R1.2, R2.2, R3.2, R4.2, R5.2, R6.2, R7.2, R18.2, U1.12
/BUZZER: BUZ1.1, J5.1, U1.1
/GND: BUZ1.2, C1.2, C2.2, C3.2, C4.2, D1.2, H1.1, H2.1, H3.1, H4.1, J1.2, J2.8, J3.2, J4.2, J5.2, R8.1, R9.1, R10.1, R11.1, R12.1, R13.1, R14.1, R15.1, R16.1, R17.1, SW1.2, SW2.2, U1.14, U2.4
/KEY1: J2.1, R1.1, U1.4
/KEY2: J2.2, R2.1, U1.5
/KEY3: J2.3, R3.1, U1.6
/KEY4: J2.4, R4.1, U1.7
/KEY5: J2.5, R5.1, U1.8
/KEY6: J2.6, R6.1, U1.9
/KEY7: J2.7, R7.1, U1.10
/LED1: D3.2, U2.5
/LED1_K: D3.1, R8.2
/LED2: D4.2, U2.6
/LED2_K: D4.1, R9.2
/LED3: D5.2, U2.7
/LED3_K: D5.1, R10.2
/LED4: D6.2, U2.8
/LED4_K: D6.1, R11.2
/LED5: D7.2, U2.9
/LED5_K: D7.1, R12.2
/LED6: D8.2, U2.10
/LED6_K: D8.1, R13.2
/LED7: D9.2, U2.11
/LED7_K: D9.1, R14.2
/LED8: D10.2, U2.12
/LED8_K: D10.1, R15.2
/LED9: D11.2, U2.13
/LED9_K: D11.1, R16.2
/LED10: D12.2, U2.14
/LED10_K: D12.1, R17.2
/SENS_MINUS: J4.1, R18.1, SW2.1, U1.11
/SENS_PLUS: J3.1, SW1.1, U2.15
/VIN: D1.1, D2.2, J1.1
/VRAW: C1.1, C2.1, D2.1, L1.1

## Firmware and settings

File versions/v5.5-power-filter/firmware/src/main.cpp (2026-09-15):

/* LEMON PIANO V5.5 — filtered supply, four-level game, and a mode wheel
   Author : Yupipi93 (Sergio Conejero), 2019 · V5 rework 2026-07-14
   Board rebuilt 2026-07-28: GND-clip keyboard, two sensitivity buttons, no
   restart and no game-select switch.
   2026-09-09: FREE PLAY + the MODE WHEEL (see "THE MODE WHEEL" below).
   2026-09-15: free play OPENS WITH A SWEEP and then leaves the bar DARK, and
   TWO LEMONS AT ONCE sound as two notes (see "TWO LEMONS AT ONCE" below).

   CODE 1 (Mario Main Theme):  6,5,6,7,2,5,2,1,3,4
   CODE 2 (Mario Underworld) :  3,6,1,4,2,5,3,6,1,4

   Seven lemons are touch keys on A0..A6. Reproduce the secret 10-note melody. A
   row of TEN green LEDs is the progress bar: each correct note lights the next
   LED; a wrong note blanks the row and the sequence restarts. Light all ten and
   the theme plays, then the game AUTO-ADVANCES to the other one.

   THE KEYBOARD IS THE 2019 ONE AGAIN (2026-07-28). Every analog pin is pulled UP
   to +5 V through 220 Ohm and rests near 1023; the player holds a GND clip, so
   touching a lemon drags that pin DOWN. This replaced the floating +5 V-clip
   keyboard because floating pins could not be read at all: measured on the bench,
   one touch pushed ALL SEVEN channels to the rail, the highest and second-highest
   channel differed by a median of 5 counts, and the idle level wandered ~170
   counts on a ~25 s cycle. A 220 Ohm pull-up gives every pin a hard reference:
   idle 1022-1023, rock steady, and a touch dips it a few counts.

   Sensitivity is a MARGIN from each key's own resting level, not an absolute
   reading, and it is on two buttons so it can be tuned with a hand on the fruit:
     - D7 -> more sensitive (smaller margin)
     - A7 -> less sensitive (bigger margin)
     - both held 1 s WHILE TOUCHING a lemon -> smart adjust: the firmware learns
       the best margin from that real touch.
   At boot it auto-calibrates: it measures every key's baseline AND its idle
   noise, then derives the margin from the noise. The LED bar shows what it is
   doing, and every state change has its own sound.

   Gone in this rebuild: GAME SELECT (A7 is a button now) and RESTART (D7 is a
   button now). The game starts at 1 and auto-advances on every win, so both
   themes are reachable; recalibration is the smart-adjust gesture or a reset.
   The previous V5 board is in git history and CHANGELOG.md.

   THE MODE WHEEL (2026-09-09) — the game-select switch comes back, as a
   gesture. HOLD "−" FOR THREE SECONDS and the piano opens a wheel of five
   modes: the four levels, and FREE PLAY. "+" and "−" turn it (it wraps both
   ways), each stop previews itself in sound and light, and BOTH BUTTONS AT
   ONCE accepts. A long press on either button, or twenty seconds of silence,
   leaves it having changed nothing.

   FREE PLAY is the fifth item and is NOT a level: it cannot be reached by
   winning, only chosen here. The seven lemons become do-re-mi-fa-sol-la-si
   (C5..B5), there is no code to find, no wrong note, and — unlike the game —
   THE SAME LEMON MAY BE PLAYED OVER AND OVER, which is the whole point of an
   instrument and exactly what the game's repeat filter forbids.

   TWO LEMONS AT ONCE (2026-09-15) — in FREE PLAY only, a second lemon held
   together with the first is detected and both notes sound. One buzzer cannot
   hold two frequencies, so the chord is played the way every mono chip has
   played one since 1983: the two notes swap the buzzer every CHORD_SWAP_MS,
   fast enough that the ear fuses them into an interval. What is hard here is
   not the sound but the DECISION — the channels are coupled, so one finger
   already drags its neighbours down, and a false chord (one finger warbling
   like two) is far worse than a missed one. chordPartnerFor() is where that
   judgement lives and it is deliberately hard to please.

   Three gestures now share two buttons, so the decision layer was lifted out
   into include/ui_gestures.h — plain C++ with no Arduino in it, driven through
   every overlapping timeline by test/ui_gestures_test.cpp on the host. Read
   that header for the full gesture map and the four collisions it resolves;
   this file only turns its events into sound and light.

   Kept: edge-triggered input, one key at a time (strongest channel wins),
   sustained notes, PROGMEM melodies, the victory light show, and the compile-time
   Velxio emulation shim (see emulation/README.md).

   Pin map (rewired 2026-07-28 for buildability — one ascending run for the bar):
     A0..A6  keys 1..7      (220 Ohm pull-up each; player holds GND)
     D2..D11 LEDs 1..10     (LED n on pin n+1 — nothing to look up)
     D12     SENS + button  (to GND, internal pull-up)
     D13     buzzer         (the on-board LED blinks with the audio)
     A7      SENS - button  (to GND + external 10 kOhm pull-up)

   Requires an Arduino Nano (or Mini): A6 is a key and A7 is a button, and the
   classic Uno exposes neither.
*/

#include <Arduino.h>
#include "notes.h"
#include "mario_sfx.h"   // every non-key sound + the level 3/4 themes
#ifndef VELXIO_EMULATION
#include "ui_gestures.h" // the two buttons, as one host-tested state machine
#endif

//################################
//###########  PINS ##############
//################################
#ifdef VELXIO_EMULATION
#define BUZZER 11  // MUST be D11: Velxio ends a note only on a Timer2 duty->0
                   // event and noTone() leaves OCR2A set, so the note-off is an
                   // explicit `OCR2A = 0` — and OCR2A is Timer2/OC2A = D11. On any
                   // other pin the first note beeps forever (CHANGELOG 2026-07-13).
#else
// Pin map chosen so the board is easy to WIRE and easy to FOLLOW: the ten LEDs are
// one unbroken ascending run, LED n on pin n+1 (LED 1 = D2 ... LED 10 = D11), then
// the two odd men out take the last two digital pins.
#define BUZZER 13        // last pin; the Nano's on-board LED blinks along with the
                         // audio, which is harmless (and a free "sound" indicator)
#define SENS_UP 12       // button to GND (internal pull-up): MORE sensitive
#define SENS_DOWN A7     // button to GND + external 10k pull-up: LESS sensitive.
                         // A7 is analog-in only and has no internal pull-up, hence
                         // the external one; read with analogRead() < 512.
                         //
                         // Why the button is NOT on D13: on many Nanos the on-board
                         // LED hangs off D13 through ~1 kOhm, which fights a ~30 kOhm
                         // internal pull-up and can read as "permanently pressed".
                         // A buzzer does not care about that load, so D13 is its pin
                         // and the button gets D12.
#endif

const uint8_t KEY_COUNT = 7;    // A0..A6
const uint8_t LED_COUNT = 10;   // one green LED per note of the sequence

// The ten green progress LEDs, LED[0] = first note ... LED[9] = tenth note.
#ifdef VELXIO_EMULATION
// The browser has no pins for the sensitivity buttons (see the shim note below),
// so D7/D8 are free for LEDs here; key 7 is on D12 and the buzzer on D11.
const uint8_t LED_PINS[LED_COUNT] = {2, 3, 4, 5, 6, 7, 8, 9, 10, 13};
#else
// Hardware: one contiguous run, LED n -> pin n+1. Wire the bar left to right and
// the pin numbers just count up with it — no gaps to remember.
const uint8_t LED_PINS[LED_COUNT] = {2, 3, 4, 5, 6, 7, 8, 9, 10, 11};
#endif

// ── Velxio emulation input shim (define VELXIO_EMULATION to enable) ─────────
// Good news since the keyboard went back to pull-ups: the browser's pushbutton +
// pull-up IS this polarity (idle ~1023, pressed ~0), so the sensing needs no shim
// at all any more. What still differs:
//   - key 7 moves to D12: avr8js exposes A0..A5 for analog injection, no A6/A7,
//   - buzzer on D11 (see above),
//   - NO sensitivity buttons: ten LEDs + buzzer + key 7 already use all twelve
//     digital lines. The buttons and the smart-adjust gesture are verified on the
//     V2.5 rig instead (../../v2.5-threshold-buttons/), which is the same front
//     end with the bar removed. Boot auto-calibration still runs here.
#ifdef VELXIO_EMULATION
const uint8_t KEY_PINS[KEY_COUNT] = {A0, A1, A2, A3, A4, A5, 12};
#endif

//################################
//#########  CONSTANTS ###########
//################################
const int SEQUENCE_LENGTH = 10;   // notes to guess correctly to win (== LED_COUNT)

// ── Sensitivity ─────────────────────────────────────────────────────────────
// A key counts as touched when its reading has dropped TOUCH_MARGIN counts below
// that key's own resting level. Measured on this rig (2026-07-27): baseline 1022,
// a fruit touch dips to 1018 — a 3-4 count signal, because ~1 MOhm of skin against
// a 220 Ohm pull-up is a lopsided divider. That is where the 2019 sketch's magic
// `<= 1019` came from, and why the knob works in SINGLE counts down here.
int  touchMargin = 4;             // the knob, in ADC counts (auto-set at boot)
const int MARGIN_MIN = 1;
const int MARGIN_MAX = 600;
const int MARGIN_STEP_FINE = 1;      // step at or below MARGIN_COARSE_ABOVE
const int MARGIN_STEP_COARSE = 5;    // step above it
const int MARGIN_COARSE_ABOVE = 20;
const int TOUCH_HYSTERESIS = 2;   // a key is released only when it comes back this
                                  // far ABOVE its threshold (Schmitt trigger), so a
                                  // reading on the line cannot chop up the note.
                                  // Small, because the whole signal is ~4 counts.

// ── Auto-calibration ────────────────────────────────────────────────────────
// The margin is derived from the MEASURED noise: a quiet rig gets a tight margin,
// a noisy one a wide margin, with no dial to turn. Floor 4 = the working point
// measured on the real board.
const uint8_t CAL_SAMPLES = 24;               // ~200 ms for all seven keys
const int NOISE_FACTOR = 2;                   // auto margin = 2 x worst noise
const int AUTO_MARGIN_MIN = 4;                // ...never tighter than this
const unsigned long CAL_STEP_PAUSE_MS = 150;  // extra pause per key, after its
                                  // coin, purely so the progressive 10-LED
                                  // fill reads as a deliberate count-up rather
                                  // than a blur (2026-07-29). Doesn't touch
                                  // CAL_SAMPLES, so measurement quality is
                                  // unaffected — this is display pacing only.
const unsigned long BASELINE_EVERY_MS = 100;  // idle-drift tracking interval
const int BASELINE_DIVISOR = 8;               // baseline += (reading-baseline)/8
const unsigned long STUCK_MS = 5000;          // stuck-key re-baseline timeout

// ── Smart adjust (both buttons 1 s while touching a lemon) ──────────────────
const unsigned long RECAL_HOLD_MS = 1000;     // hold both this long to trigger it
const unsigned long LEARN_MS = 600;           // total sampling window
const uint8_t LEARN_BURSTS = 4;               // bursts, with a blip + LED between

// ── Buttons ─────────────────────────────────────────────────────────────────
const unsigned long BUTTON_DEBOUNCE_MS = 40;
// The sensitivity ramp is GONE (2026-09-13). Both buttons carry a hold gesture
// now, so a hold must be a mode change and nothing else: one tap, one step.
// Timings live in include/ui_gestures.h, which is what the host test compiles.

// ── Sound ───────────────────────────────────────────────────────────────────
const int NOTE_DURATION = 70;     // minimum key tone length; a held key sustains
const int WRONG_TONE_GAP_MS = 60; // silence between the played note and the
                                  // mistake cue, so the two never blur together
const unsigned long SUSTAIN_CAP_MS = 2000;  // how long the wrong tone waits for a
                                  // held key before sounding anyway (a stuck key
                                  // must not freeze the game)
// A RELEASE HAS TO BE CONFIRMED (2026-09-13). A finger resting on fruit is not
// a clean contact: through 1 MOhm the reading wanders, and a single scan that
// crosses back over the threshold used to end the note — and the next scan,
// finding the finger still there, started a NEW one. Held fruit machine-gunned
// itself, which is what Sergio reported: "si el usuario mantiene la fruta, solo
// tiene que sonar una vez".
//
// So the note survives any dropout shorter than this, and only silence that
// LASTS counts as letting go. It has to stay well under a deliberate re-tap
// (about 150 ms hand-to-hand at speed) or fast playing would lose notes.
const unsigned long RELEASE_CONFIRM_MS = 90;
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
void loop() {
#ifndef VELXIO_EMULATION
  serviceButtons();      // sensitivity knob, smart adjust, and the mode wheel

  // While the wheel is turning the LEMONS ARE DEAD. A preview melody and a
  // played note share one buzzer, and a piano that answers the fruit while it
  // is asking you a question is a piano nobody can read. Baselines keep
  // tracking, so a long browse does not leave the keyboard mis-calibrated.
  if (gestures.inMenu()) {
    serviceMenu();
    trackBaselines();
    return;
  }
#endif
  trackBaselines();      // follow the idle drift while keys are untouched

  // The bar belongs to the sensitivity meter for a moment after a button press;
  // restore whatever the current mode shows when idle once that moment passes.
  if (ledMeterUntil && (long) (ledMeterUntil - millis()) <= 0) {
    ledMeterUntil = 0;
    restoreIdleDisplay();
  }

  const int keyboardOffset = (level - 1) * KEY_COUNT;

//################################
//########  READ INPUT ###########
//################################
  // ONE key at a time. While a key is down nothing else can interrupt it — the
  // channels are coupled, so a single finger lifts several of them over their
  // thresholds and any "first index wins" scan would flip between them.
  if (activeKey >= 0) {
#ifdef DEBUG_TOUCH
    dumpDips();          // four times a second, what every channel is doing
#endif
    // TWO LEMONS SOUNDING: the chord answers for both of them, including which
    // one was let go. It cannot be decided here, because keyStillDown() is an
    // absolute threshold and a lifted finger does not cross one while the other
    // finger is still shadowing its channel — see serviceChord().
    if (chordKey >= 0) { serviceChord(); return; }

    if (keyStillDown(activeKey)) {
      releaseSeenAt = 0;   // whatever that was, it was not letting go
      serviceChord();      // free play only: a SECOND lemon may join this note
      return;              // still held: the note is sounding, nothing to decide
    }
    // It read clear — but ONE scan is not a release (see RELEASE_CONFIRM_MS).
    // Hold the note and the key while the silence proves itself; a finger that
    // is still on the fruit comes back within a scan or two and nothing happened.
    if (releaseSeenAt == 0) releaseSeenAt = millis();
    if ((millis() - releaseSeenAt) < RELEASE_CONFIRM_MS) return;
    releaseSeenAt = 0;

    // RELEASE — let the note reach its minimum length (so a quick tap is still a
    // note), then go silent. The next loop is free to accept a new key.
    long remaining = (long) (keyToneMinEndsAt - millis());
    if (remaining > 0) delay(remaining);
    stopKeyTone();
    activeKey = -1;
    // The bar goes back to whatever this mode shows when no finger is on it:
    // the progress count in the game, darkness in free play. That one line also
    // ends the repeat cue, which is lit for exactly as long as the lemon is.
    repeatBarOn = false;
    if (!ledMeterUntil) restoreIdleDisplay();
    return;
  }

  releaseSeenAt = 0;                  // nothing is held; the clock starts fresh
  int justPressed = strongestKey();   // the clearest touch this scan, or -1
  if (justPressed >= 0) {
    pressedNote = keys[justPressed + keyboardOffset];
    activeKey = justPressed;

    // ── FIVE TAPS ON ONE LEMON: "play me that tune again" ──────────────────
    // Counted before anything sounds or scores, so the fifth press is the
    // request rather than a note. Game only — see THEME_REPEAT_PRESSES for why
    // free play must never count repeats.
    if (!freePlay()) {
      const unsigned long now = millis();
      if (justPressed == repeatRunKey && (now - repeatRunAt) <= THEME_REPEAT_GAP_MS) {
        repeatRunCount++;
      } else {
        repeatRunKey = justPressed;   // a different lemon, or too long a pause
        repeatRunCount = 1;
      }
      repeatRunAt = now;
      if (repeatRunCount >= THEME_REPEAT_PRESSES) {
        playThemeReminder();
        return;
      }
    }

    // ── FREE PLAY: no lock, no guess, no penalty ───────────────────────────
    // Everything below this block exists to stop flaky fruit contact from
    // machine-gunning the GAME. An instrument wants the opposite: the same
    // lemon, again and again, as fast as you like. So free play takes the
    // short road — sound the note, show the pitch, and stop.
    if (freePlay()) {
      startKeyTone(pressedNote);
      ledMeterUntil = 0;             // the note owns the bar now, not the meter
      playKeyWave(justPressed);      // a wave breaking outward from that lemon,
                                     // and then darkness: the wave IS the display
      if (serialEnabled) {
        Serial.print(F("~ key ")); Serial.print(justPressed + 1);
        Serial.print(F("  ")); Serial.print(pressedNote); Serial.println(F(" Hz"));
      }
      return;
    }

    // A KEY ALWAYS SOUNDS (2026-09-13). This is a piano before it is a game, so
    // the note under the finger is never withheld — not even when the game has
    // nothing to do with it. A repeat used to stay silent and then scold, with
    // the sfxKeyStuck rattle; Sergio asked for both of those to go, because
    // pressing the same lemon twice is not a mistake, it is just not a move.
    startKeyTone(pressedNote);

#ifdef DEBUG_TOUCH
    Serial.print(F("press key ")); Serial.print(justPressed + 1);
    Serial.print(F("  readings:"));
    for (uint8_t i = 0; i < KEY_COUNT; i++) {
      Serial.print(' ');
      Serial.print(keyTouched(i) ? '*' : ' ');
#ifndef VELXIO_EMULATION
      Serial.print(analogRead(i));
#endif
    }
    Serial.println();
#endif

    // ...but the GAME only sees the FIRST press of a key. A repeat still sounds;
    // it simply does not score, does not advance and — this is the part that
    // changed — does not COST anything either. It says so in light, not in noise.
    if (justPressed != lastCountedKey) {
      lastCountedKey = justPressed;
      handleGuess();
    } else {
      showRepeatHold();
      if (serialEnabled) {
        Serial.print(F("    key ")); Serial.print(justPressed + 1);
        Serial.println(F(" again - sounds, scores nothing (play a different lemon)"));
      }
    }
  }
}


//################################
//#########  GAME LOGIC ##########
//################################
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

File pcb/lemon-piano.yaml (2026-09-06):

# Lemon Piano V5.5 Board — pcb-designer config
#
# Canonical configuration for the Lemon Piano V5.5 PCB (breadboard →
# fabricable board, same circuit as versions/v5.5-power-filter).
# The board lives in THIS repo under pcb/; the pcb-designer toolkit is the
# sibling repo ../eda-pcb-designer (consumed like eda-wirewright is by
# tools/wiring_diagrams.py). Netlist ground truth: pcb/docs/NETLIST.md.
# Placement rationale: pcb/docs/DECISIONS.md.
#
# Board frame: 120 × 40 mm (ADR-024), MT1 coordinate style
# (x 90..210, y 100..140; centre 150,120).
#
# v0.7.0 floor plan (user spec 2026-09-06 — supersedes the v0.5.0 plan):
#   - Nano socket CENTERED on the board (pin field 132.22..167.78 about
#     x=150, rows ±7.62 about y=120) and rotated 180° back so the
#     **mini-USB faces WEST** (ADR-035, supersedes ADR-029): the cable must
#     leave the enclosure on the left, away from the SENS buttons, with the
#     module SEATED — no more lifting the Nano to flash it. The flip puts
#     the DIGITAL column on the NORTH row and the ANALOG column on the SOUTH
#     row. Row maps per the real Nano (ADR-015: D12/D13 at the USB end).
#   - Lemon-key header on the SOUTH edge, CENTERED (J2 pins 141.11..158.89,
#     centre exactly x=150). Pin 1 = KEY1 at the WEST so KEY1..KEY7 sit
#     under A0..A6 (which now ASCEND west→east) with no crossings (ADR-036).
#   - LED bar on the NORTH edge, CENTERED on x=150. D2..D11 now DESCEND
#     west→east along the north row, so the bar runs LED1 EAST → LED10 WEST
#     for a non-crossing fan (ADR-036; same rule that produced v0.2.0-v0.4.0).
#   - USB-cable corridor REINSTATED on the west side (ADR-035, supersedes
#     ADR-030): x < 130.4, y 113..127 is part-free on F.Cu. It is exactly the
#     band ADR-024 defined and geometry_gate checks it against real courtyards.
#   - Power-entry filter folded around that corridor (ADR-037): C1 ‖ C3 stay
#     ADJACENT on the north row (ADR-031); D2 and L1 move OUT of the old
#     middle row into the south strip with J1 → D1, so the choke and the
#     Schottky no longer sit where the plug goes.
#   - 5 V input is a 2-pin 2.54 mm header (J1, ADR-025), not a screw block.
#   - SENS± buttons in the EAST block, the PAIR centred on y=120, each with
#     a parallel 2-pin external-button header (J3/J4, ADR-026) — unchanged.
#   - Buzzer in the NE corner (ADR-027) with J5 SPK beside it (ADR-034) —
#     unchanged; D13 is at the west end again so /BUZZER is long (accepted
#     in ADR-027 for exactly this orientation).
# ----------------------------------------------------------------------------

project:
  name: lemon-piano
  full_name: "Lemon Piano V5.5 Board"
  version: v0.7.1
  vendor: "Lemon Piano"
  kicad_project_dir: pcb/kicad
  kicad_pcb_file: lemon-piano.kicad_pcb
  kicad_sch_file: lemon-piano.kicad_sch
  validation_output_dir: pcb/validation
  renders_output_dir: pcb/renders
  tools_dir: pcb/tools
  releases_output_dir: pcb/releases

# ----------------------------------------------------------------------------
# Board outline + anchor dividers. Anchor zones (x<100, x>200) hold only the
# M2 holes; every other footprint stays between the dividers.
# ----------------------------------------------------------------------------
geometry:
  pcb:
    x0:  90.0
    y0: 100.0
    x1: 210.0
    y1: 140.0
  anchors:
    left_x:  100.0
    right_x: 200.0
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

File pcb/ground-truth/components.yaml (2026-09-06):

# GROUND TRUTH — physical pinout of every Lemon Piano V5.5 part.
#
# Source of truth for the anti-mirror / anti-pin-swap gate
# (pcb_designer.verify): the .kicad_pcb is compared against THIS file.
# Derived from pcb/docs/NETLIST.md, which itself is
# extracted from arduino-lemon-piano (v5.5 HARDWARE.md + the DRC-validated
# build_v5_5() wirewright contract). Net names as they appear in the
# .kicad_pcb (leading '/').

components:

  # ────────────────────────────────────────────────────────────────────
  # Arduino Nano (ATmega328P) — TWO 1x15 sockets. PHYSICAL truth
  # (v0.2.0 / ADR-015, verified on the official 2008 Nano V2.2 photo and
  # clone boards): viewed from top with the mini-USB UP, the LEFT column
  # top→bottom is D13,3V3,AREF,A0..A7,5V,RST,GND,VIN and the RIGHT
  # column top→bottom is D12,D11..D2,GND,RST,RX0,TX1 — i.e. D12/D13 at
  # the USB end, TX1/VIN at the ICSP end.
  # v0.7.0 (ADR-035): the Nano mounts on TOP with USB facing WEST (−X),
  # turned 180° back from v0.5.0/v0.6.0. U1 = SOUTH row (pin1 west = D13,
  # the analog column), U2 = NORTH row (pin1 east = TX1, the digital
  # column). That is what puts the LED bar north and the keys header south.
  # The chirality triad below is rotation-invariant, so it is unchanged.
  # ────────────────────────────────────────────────────────────────────
  NANO:
    refs: [U1, U2]
    mount_side: top
    source: "Official Arduino Nano V2.2/V3 board: USB end flanked by D12 (TX1 column) and D13 (VIN column); commons.wikimedia.org File:ArduinoNanoTop.jpg + File:Arduino Nano.jpg"
    pins:
      "U1.1":  {func: D13,  net: /BUZZER}
      "U1.2":  {func: 3V3,  net: null}
      "U1.3":  {func: AREF, net: null}
      "U1.4":  {func: A0,   net: /KEY1}
      "U1.5":  {func: A1,   net: /KEY2}
      "U1.6":  {func: A2,   net: /KEY3}
      "U1.7":  {func: A3,   net: /KEY4}
      "U1.8":  {func: A4,   net: /KEY5}
      "U1.9":  {func: A5,   net: /KEY6}
      "U1.10": {func: A6,   net: /KEY7}
      "U1.11": {func: A7,   net: /SENS_MINUS}
      "U1.12": {func: 5V,   net: /+5V}
      "U1.13": {func: RST,  net: null}
      "U1.14": {func: GND,  net: /GND}
      "U1.15": {func: VIN,  net: null}   # rail feeds the 5V pin, not VIN
      "U2.1":  {func: TX1,  net: null}
      "U2.2":  {func: RX0,  net: null}
      "U2.3":  {func: RST,  net: null}
      "U2.4":  {func: GND,  net: /GND}
      "U2.5":  {func: D2,   net: /LED1}
      "U2.6":  {func: D3,   net: /LED2}
      "U2.7":  {func: D4,   net: /LED3}
      "U2.8":  {func: D5,   net: /LED4}
      "U2.9":  {func: D6,   net: /LED5}
      "U2.10": {func: D7,   net: /LED6}
      "U2.11": {func: D8,   net: /LED7}
      "U2.12": {func: D9,   net: /LED8}
      "U2.13": {func: D10,  net: /LED9}
      "U2.14": {func: D11,  net: /LED10}
      "U2.15": {func: D12,  net: /SENS_PLUS}
    chirality_triad:
      # canonical (+Y up, USB up): D13/VIN column at x=-1, D12/TX1 column
      # at x=+1; USB-end pins y=+7, ICSP-end pins y=-7.
      - {at: "U1.1",  func: D13, xy: [-1,  7]}
      - {at: "U1.15", func: VIN, xy: [-1, -7]}
      - {at: "U2.15", func: D12, xy: [ 1,  7]}

  # ────────────────────────────────────────────────────────────────────
  # Service-edge connectors
  # ────────────────────────────────────────────────────────────────────
  KEYS_HEADER:
    refs: [J2]
    mount_side: top
    source: "docs/NETLIST.md — v0.7.0: KEY1 at the WEST under A0, KEY7 east, then the GND clip (ADR-036)"
    pins:
      "J2.1": {func: KEY1, net: /KEY1}
      "J2.2": {func: KEY2, net: /KEY2}
      "J2.3": {func: KEY3, net: /KEY3}
      "J2.4": {func: KEY4, net: /KEY4}
      "J2.5": {func: KEY5, net: /KEY5}
      "J2.6": {func: KEY6, net: /KEY6}
      "J2.7": {func: KEY7, net: /KEY7}
      "J2.8": {func: GND_CLIP, net: /GND}

  POWER_IN:
    refs: [J1]
    mount_side: top
    source: "v5.5 HARDWARE.md — 5 V in (+) and GND; + = pad 1 (west). v0.4.0: 2-pin 2.54 mm header (ADR-025)"
    pins:
      "J1.1": {func: "5V_IN+", net: /VIN}
      "J1.2": {func: "GND",    net: /GND}

  # External-button headers, one wired in parallel with each SENS button
  # (v0.4.0 user spec, ADR-026): pad 1 = the signal the button pulls low,
  # pad 2 = GND. Shorting the two pins is electrically identical to
  # pressing the on-board tact switch.
  SENS_EXT_HEADERS:
    refs: [J3, J4]
    mount_side: top
    source: "user spec 2026-07-30 — a parallel 2-pin header per SENS button"
    pins:
      "J3.1": {func: pin, net: /SENS_PLUS}
      "J3.2": {func: gnd, net: /GND}
      "J4.1": {func: pin, net: /SENS_MINUS}
      "J4.2": {func: gnd, net: /GND}

  # Auxiliary speaker output, wired in PARALLEL with the buzzer (v0.6.0,
  # ADR-034): pad 1 = the D13 drive line, pad 2 = GND. Same two nodes as
  # BUZ1, so whatever is plugged in sees exactly what the buzzer sees.
  SPK_OUT:
    refs: [J5]
    mount_side: top
    source: "user spec 2026-07-31 — 2-pin aux output for an external speaker"
    pins:
      "J5.1": {func: "+", net: /BUZZER}
      "J5.2": {func: "-", net: /GND}

  # ────────────────────────────────────────────────────────────────────
  # Power-entry filter (v5.5 HARDWARE.md filter table)
  # ────────────────────────────────────────────────────────────────────
  TVS_P6KE:
    refs: [D1]
    mount_side: top
    source: "P6KE6.8A unidirectional: cathode(K)=pad1 to +, anode=pad2 to GND"
    pins:
      "D1.1": {func: K, net: /VIN}
      "D1.2": {func: A, net: /GND}

  SCHOTTKY_1N5817:
    refs: [D2]
    mount_side: top
    source: "series 1N5817: anode from VIN, cathode into the filter (VRAW)"
    pins:
      "D2.1": {func: K, net: /VRAW}
      "D2.2": {func: A, net: /VIN}

  CAP_IN_BULK:
    refs: [C1]
    mount_side: top
    source: "470uF input reservoir; pad1=+ (KiCad CP_Radial convention)"
    pins:
      "C1.1": {func: "+", net: /VRAW}
      "C1.2": {func: "-", net: /GND}

  CAP_IN_HF:
    refs: [C2]
    mount_side: bottom
    source: "100nF input ceramic (unpolarised)"
    pins:
      "C2.1": {func: a, net: /VRAW}
      "C2.2": {func: b, net: /GND}

  CHOKE:
    refs: [L1]
    mount_side: top
    source: "100uH >=1A drum choke, series element of the pi"
    pins:
      "L1.1": {func: a, net: /VRAW}
      "L1.2": {func: b, net: /+5V}

  CAP_OUT_BULK:
    refs: [C3]
    mount_side: top
    source: "470uF output reservoir at the rail; pad1=+"
    pins:
      "C3.1": {func: "+", net: /+5V}
      "C3.2": {func: "-", net: /GND}

  CAP_OUT_HF:
    refs: [C4]
    mount_side: bottom
    source: "100nF output ceramic (unpolarised)"
    pins:
      "C4.1": {func: a, net: /+5V}
      "C4.2": {func: b, net: /GND}
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

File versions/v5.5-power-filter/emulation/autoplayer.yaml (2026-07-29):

name: lemon-piano-v5-autoplayer
description: >
  Interactive-only (multi-board specs run in `--mode interactive` in this
  harness — the CLI's verify assertions only ever watch one board per run).
  Two boards: `piano` is the real V5 game (identical circuit to
  lemon-piano.yaml), and `player` is a small companion Arduino Uno that acts as
  a "virtual finger": type a level number (1-4) into PLAYER'S OWN serial
  monitor tab to arm it (an LED shows which), then type `p` and it fires that
  level's 10-note code onto the SAME key nodes your own lemon clicks use —
  piano can't tell the difference between a player-board pulse and a real
  touch. Your 7 lemons stay fully clickable throughout for manual free play /
  deliberately wrong notes; the autoplayer only ever pulls a key node low the
  way a press would.
  The autoplayer has no idea what level `piano` actually thinks it's on — it
  can only offer levels 1-4 on request. Watch piano's own serial log ("Level
  N") or match the win/auto-advance you just heard, and type the right level
  number before typing `p`.
  v5 (2026-07-29), after five rounds of testing this live (Playwright driving
  the real editor headlessly throughout — every fix below was confirmed
  working, not just plausible): PLAY/LEVEL SELECT are serial commands, not
  pushbuttons — traced to a hard limitation of this Velxio version:
  `DynamicComponent.tsx` binds EVERY interactive part's click handler to a
  single global `useSimulatorStore().simulator` field, not a per-board one,
  so a pushbutton wired to the second board's pin calls `setPinState` on the
  FIRST board's CPU instead of its own. No spec-level wiring fix exists for
  that. Serial I/O doesn't have the problem
  (`serialWriteToBoard(boardId, text)` / each board's own Serial Monitor tab
  is properly per-board), hence typing instead of clicking.
  The 7 "finger" wires go through a series resistor, not a bare direct wire
  — the last bug found: a finger pin driven straight to piano's pin was a
  hard short (in the digital fast-path both AVR boards use) that always won
  against a real lemon click on the same node, so manual play went dead the
  moment the finger wiring was fixed to actually reach piano. Toggling the
  finger pin to high-Z `INPUT` while idle (so it wouldn't fight a real click)
  broke the OTHER direction instead — this simulator doesn't re-evaluate a
  pin's cross-board connection when its mode changes at runtime, so nothing
  ever reached piano again, autoplay included, even with a 500 ms hold. A
  220Ω resistor in series lets both coexist: piano's own pull-up, a real
  button's near-zero contact resistance, and the finger's driven HIGH/LOW all
  settle into an ordinary voltage divider, and a real press's near-zero
  resistance wins over the finger's 220Ω whenever both could matter.
  Two more fixes, still true, from earlier rounds: board ids must start with
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

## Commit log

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2026-07-12 restructure: translate to English + PlatformIO workspace + full docs
    - firmware/: Piano_Limones_v4 as PlatformIO project (src/main.cpp +
    include/notes.h), 1:1 behavior, envs nanoatmega328/nanoatmega328new/uno,
    all building green (RAM 38%, flash 21%)
    - Reconstruct corrupted 'Duracion' line (stray keystrokes) as NOTE_DURATION=50
    - archive/banana-piano-original/: frozen 2019 lineage, comments and
    identifiers translated (banana-piano, keyboard-test, game-prototype)
    - docs/: deduced schematic + pin map + touch-sensing physics (HARDWARE.md),
    Fritzing + breadboard images moved from the old folders
    - README with game rules, secret codes, hardware list and quick start;
    TODO.md 14-item fix r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
    [keyboard-schematic.fzz]
2026-07-13 fix: apply firmware fixes TODO #1-#12 (correctness, gameplay, RAM)
    Behavior is now fixed & improved rather than a 1:1 translation. All three
    envs build green; static RAM 778 B -> 309 B (38% -> 15%), flash 7.3 KB (24%).
    Correctness:
    - clear pressedNote on victory (no instant false-fail after a win) (#1)
    - pumpOff() defined boot state instead of analogWrite(pin, HIGH) (#2)
    - selectGame() resets fails/currentStep/dead -> clean post-death restart (#3)
    - drop bogus pinMode(0..7, INPUT) UART clobber; single log() helper (#4)
    - buzz() guards frequency <= 0 (#5); delete dead 'if (game = 1)' block (#6)
    Gameplay:
    - LED feedback timed with millis() (#7)
    - edge-triggered input via keyHeld[]: held fing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
    [main.cpp]
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2026-07-14 v5: ten-LED progress bar, auto-advancing games; freeze v4
    Archive the complete V4 (firmware + Velxio emulation) into
    archive/lemon-piano-v4/ and rework the active firmware/ + emulation/ into V5.
    Firmware (V5):
    - Remove relays / water pump / red LED / fail-counter / death tune.
    - Ten green LEDs as a progress bar on D2,D3,D4,D5,D6,D9,D10,D11,D12,D13: each
    correct note lights the next LED; a wrong note blanks all ten + a low tone;
    ten lit = win.
    - Auto-advance: winning a theme flips to the other game (1->2->1...), so both
    games cycle from one starting point.
    - Game-select moved D4 -> A7 (analog-in) to free the 10th LED pin; V5 needs a
    Nano/Mini (A6+A7), so the uno env is dropped.
    - Kee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
    [lemon-piano.yaml, main.cpp]
2026-07-14 v5: victory light show + noise-adaptive touch calibration
    - playSong() flashes the whole ten-LED bar to the beat of the winning
    theme: lit while each note sounds, dark in the gaps and rests. Shared
    game logic (new allLedsOn() helper); verified headlessly — LED 10
    (win-only) toggles 61 times across the Mario victory tail.
    - Ghost-press fix: TOUCH_MARGIN is no longer a fixed constant. calibrate()
    samples each key 64 times over ~128ms (6+ mains cycles), measures mean
    baseline + peak noise, and sets threshold = baseline +
    max(40, 3x noise), capped at 900 with a serial warning for pathological
    keys. Quiet supplies get more sensitive, noisy chargers stop ghosting.
    - calibrate() mov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
    [lemon-piano.yaml, main.cpp]
2026-07-26 V4 touch upgrade + wiring diagrams via the wirewright engine
    Firmware (archive/lemon-piano-v4, owner-authorised in-place edit):
    - noise-adaptive touch calibration ported from V5 (replaces fixed TOUCH_MARGIN),
    re-run on boot and every RESTART
    - manual MARGIN +/- buttons on D10/D11 (hardware only) to tune touch live
    - game unchanged (pump, red/green LED, death tune, both codes); all pio envs +
    Velxio emulation verify green; regenerated the V4 emulation .vlx
    Wiring diagrams:
    - diagrams now generated by the reusable wirewright engine (auto-router + DRC:
    no wires cross components, overlap, or leave pins unconnected). tools/schematic
    was extracted to its own repo (../eda-wirewright); tool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
    [main.cpp]
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2026-07-27 feat(v5): free play until the sequence starts; wrong tone waits for the note
    Playing V5 on hardware showed the game fighting the instrument: every stray
    touch buzzed, and the low "wrong" tone cut off the note that caused it.
    - Free play while the bar is empty (currentStep == 0): keys just sound their
    note, no WRONG and no penalty. The puzzle starts when the player hits the
    code's first note (LED 1); a miss then blanks the bar and drops back to
    free play.
    - The wrong tone no longer interrupts the key note. keyTone() records
    keyToneEndsAt and the miss path waits it out (new waitKeyToneEnd()) plus a
    WRONG_TONE_GAP_MS 60 ms silence, so you hear WHICH note was wrong, then the
    verdict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
    [main.cpp]
2026-07-27 feat(v5): sustain the note while a key is held; count each key only once
    Lemons make flaky contacts, and the game was reading that flakiness as
    gameplay: a held touch stopped sounding after 70 ms, and every re-press or
    contact flicker was a fresh guess that could fail the round on its own.
    - keyTone() -> startKeyTone()/stopKeyTone(): tone() with no duration, so the
    note runs until the lemon is released, with NOTE_DURATION as a floor for
    quick taps. New activeKey tracks what is sounding. Measured: 600 ms hold ->
    584 ms tone, 80 ms tap -> 84 ms, 250 ms hold -> 250 ms.
    - New lastCountedKey: only the FIRST press of a key reaches handleGuess().
    Holding it or tapping it again sounds but n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
    [main.cpp]
2026-07-27 fix(v5): one key at a time (strongest wins + hysteresis); document the ADC evidence
    Hardware testing showed OK 1/10 followed by WRONG in the SAME millisecond, seven
    times over. The repeat filter blocks the same key, so that can only be two
    different channels being counted: one finger read as two keys.
    Firmware (passes all three emulation specs; unverified on hardware, see below):
    - strongestKey() replaces "first index above threshold" — the channel with the
    largest margin over its own threshold wins, so a real touch beats coupled
    ghosts instead of racing them.
    - While a key is down, every other channel is ignored until release. keyHeld[]
    removed; activeKey is now the single source o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
    [main.cpp]
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2026-07-29 feat(v5): interactive autoplayer board + always push to main
    Adds emulation/autoplayer.yaml (+ .vlx): a second Arduino Uno sharing the V5
    canvas with a LEVEL SELECT and PLAY button, wired onto the piano's own key
    nodes so a human can auto-play any level's code on demand while the real
    lemons stay clickable for manual free play. Multi-board specs only run in
    --mode interactive in this harness; validated by compiling both sketches
    standalone (arduino-cli) and confirming the .vlx generates.
    Also codifies in CLAUDE.md: commit and push to origin/main after every
    modification in this repo, per the owner's standing instruction.
    [autoplayer.yaml]
2026-07-29 fix(v5): autoplayer sound/button bugs found in first live test
    Fixes two real bugs the owner hit clicking the autoplayer board live:
    - finger output pins fought manual lemon presses on the same node
    (idle HIGH-driving output vs. a real touch to GND) -> no sound;
    now high-Z while idle, only drives LOW to "press".
    - PLAY/LEVEL SELECT used INPUT_PULLUP, which avr8js doesn't simulate
    -> both read permanently LOW (armed level 2 at boot, dead after);
    fixed with real external pull-ups + a boot guard.
    Regenerated autoplayer.vlx and lemon-piano.vlx against the also-fixed
    harness wire-coloring bug (net-aware now, was per-wire-position).
    [autoplayer.yaml]
2026-07-29 fix(v5): autoplayer works now — verified live via headless Playwright
    Three real root causes, found by actually driving the browser (import
    .vlx, click Run, dispatch button events, read Serial Monitor tabs)
    instead of guessing from source:
    1. Board ids must start with a recognized kind string. isBoardComponent()
    checks hardcoded kind-prefixes, not whatever id a spec assigns -
    custom ids ("piano"/"player") silently broke every pushbutton's own
    pin-trace, piano's 7 keys included. Reverted to default arduino-nano
    / arduino-uno ids.
    2. Interconnect.ts only bridges wires where both endpoints are literal
    board components - the finger wires landed on a resistor's node,
    invisibl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
    [autoplayer.yaml]
2026-07-29 fix(v5): manual lemon clicks work again alongside autoplay
    Autoplay working (previous commit) surfaced a new regression: manual
    lemon clicks did nothing. Traced live (window.__spiceDebug node
    voltages) to a real electrical short - the finger pin, driven OUTPUT
    HIGH even while idle, sits on the exact same node as the button and
    always won in the digital fast-path both AVR boards use, so a real
    press could never pull the node down.
    Tried high-Z INPUT while idle instead (so it wouldn't fight a click) -
    manual clicks came back but auto-play went dead in the other
    direction, even with a 500ms hold: this simulator doesn't re-evaluate
    a pin's cross-board connection when its mode changes at runtime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
    [autoplayer.yaml]
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2026-07-29 fix(v5): Mario death rattle for mistakes, fix win sound order
    - wrongTone() now plays sfxMistake (short 2-note Death excerpt) instead of a
    plain low C2 beep.
    - handleGuess() win sequence reordered: the level's own theme plays out in
    full first, then the flagpole fanfare, then (on level 4) the ending melody
    — previously the fanfare cut in ahead of the theme.
    - Docs updated to match; regenerated lemon-piano.vlx from a green verify run.
    [main.cpp]
2026-07-29 feat(v5): level-start announce, full Underwater/Starman themes, real ending
    - New playLevelIntro() plays the opening notes of the level's own theme once
    at boot and on every level transition, so the player knows which of the
    four levels they landed on before touching a lemon.
    - Underwater and Starman are now full PROGMEM themes played via playSong(),
    same treatment as Overworld/Underworld, with their own victory-tail cuts —
    replacing the old short playSfx() excerpts.
    - Replaced the generic "ending" jingle with a reconstruction of SMB1's
    castle-clear fanfare (no verbatim transcription could be sourced; built to
    match the cited "Mario Cadence" description instead).
    - Recomputed a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
    [lemon-piano.yaml, main.cpp]
2026-07-29 feat(v5): stuck-key cue, Castle replaces Underwater, ending loops until reset
    - New sfxKeyStuck plays when a locked key is pressed again after a 500ms
    cooldown (KEY_LOCK_COOLDOWN_MS) — previously silent forever, no feedback.
    - Level 3's theme swapped from Underwater (too hard to recognise) to Castle,
    SMB1's driving fortress theme. No letter-note tab exists for it, so it's a
    built reconstruction matching the piece's documented key/tempo/character,
    tagged accordingly. Key notes and secret code unchanged.
    - The game-complete piece (sfxEnding) extended to three phrases and now loops
    via playEndingLoop() until the player holds both sensitivity buttons for
    1s (RECAL_HOLD_MS) — whic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
    [autoplayer.yaml, main.cpp]
2026-07-29 fix(v5): ending loop now actually loops in the emulator
    playEndingLoop() played sfxEnding once and reset in VELXIO_EMULATION builds
    (no free pins there for the reset-gesture buttons), which from the outside
    looked exactly like a bug: an ending meant to keep celebrating instead played
    once and quietly reset. Now it loops forever there too; "reset" in the
    browser means stopping/re-running the simulation, same as pulling power on
    real hardware.
    [main.cpp]
2026-07-29 feat(v5): faster autoplayer, Castle closes the game, more recognisable Castle theme
    - emulation/autoplayer.yaml's Uno pressKey() timing cut from 250/300ms to
    160/200ms per note (~35% faster). Not re-verified live at the same 9/9
    rigor as before; compile-checked standalone via arduino-cli, monitor for
    misfires and pull back toward 250/300 if it ever flakes.
    - Level 3/4 themes swapped: Castle now closes the game at level 4, Starman
    moved to level 3. Only the switch statements in playVictory()/
    playLevelIntro() changed; each level's own key notes and secret code
    stayed put through both this and the earlier Underwater->Castle swap.
    - Castle theme redesigned: a player found the first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
    [autoplayer.yaml, main.cpp]
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2026-07-30 fix(pcb): v0.2.0 — real Nano orientation (erratum ADR-015) + full render suite
    The photo-overlay verification caught v0.1.0's socket maps being
    180°-rotated (TX1/VIN are at the ICSP end on real Nanos, D12/D13 at the
    mini-USB end — verified on the official 2008 V2.2 board photo and
    clones). v0.1.0 only worked inserted USB-east, where the buzzer blocks
    the plug; its release folder is renamed v0.1.0-ERRATUM-do-not-fab.
    v0.2.0 keeps the mechanics (USB corridor west) and fixes the maps:
    keys header SOUTH (1..7 G under A0-A6), LED bar NORTH ascending
    east→west, pull-ups with their pins; ground truth, schematic, netlist
    and every gate re-derived — DRC 0/0/0, ERC 0/0, verify_placement/
    hol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
    [lemon-piano.kicad_pcb, lemon-piano.kicad_sch]
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2026-07-30 feat(pcb): v0.3.0 — 4 anchor holes, VU-meter LED colors, render fixes
    - Two M2 anchors per short edge (x=95/185, y=105/125); hole-VISION
    verification enabled on transparent-bg renders (LL §22), LOO <=0.04 mm.
    - LED1..10 = 3 green / 3 yellow / 2 orange / 2 red with per-LED colored
    3D bodies in the realistic renders (orange model shipped by the
    service). BOM values follow the colors.
    - Realistic-bottom now shows all back-side parts (cloud /place no longer
    strips models from natively flipped footprints — toolkit fix e1320f5).
    - Brighter Nano overlay photo (File:Arduino nano.jpg, CC BY-SA 4.0),
    recalibrated at 57.95 px/mm.
    - post_route: split-net repair proven in anger (+5V chain)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
    [lemon-piano.kicad_pcb, lemon-piano.kicad_sch]
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2026-07-30 feat(pcb): v0.5.0 — flip the Nano (USB east), keys north, LEDs south, filter refactored
    Second pass on the 120x40 board, to the user's follow-up spec. The V5.5
    circuit is unchanged; this is all orientation and placement.
    - The Nano is FLIPPED 180 deg: mini-USB now faces EAST (ADR-029). This is
    the load-bearing change and it is what "keys up, LEDs down" REQUIRES: the
    module's analog and digital columns sit on opposite long edges, so the
    only way to change which board edge they face is to rotate the module.
    U1 (analog) becomes the NORTH row with pin 1 (D13) east; U2 (digital)
    becomes the SOUTH row with pin 1 (TX1) west.
    - Keys header on the NORTH edge, still centred (pin centre ex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
    [lemon-piano.kicad_pcb, lemon-piano.kicad_sch]
2026-07-30 fix(pcb): v0.5.1 — restore D1's 3D body (Kathode/Cathode filename split)
    User-reported: D1 had no body in any realistic render, just bare pads and
    silk, while D2 right beside it rendered fine.
    Cause: KiCad 9's Diode_THT:D_DO-15_P5.08mm_Vertical_KathodeUp footprint
    references a STEP of the same name, but kicad-packages3D ships that body
    spelled the English way, D_DO-15_P5.08mm_Vertical_CathodeUp.step. The
    footprint kept the legacy German-ish "Kathode"; the 3D library moved to
    "Cathode", so the path resolved to nothing. kicad-cli pcb render skips
    models it cannot resolve SILENTLY - no warning, no DRC item, no build error
    - which is why it survived unnoticed from v0.3.0 (first release with 3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
    [lemon-piano.kicad_pcb, lemon-piano.kicad_sch]
2026-07-31 feat(pcb): v0.6.0 — J5, 2-pin aux speaker output in parallel with the buzzer
    User request: two pins for an external speaker.
    - New 2-pin header J5 (silk "SPK") on the SAME two nodes as the buzzer:
    pad 1 on /BUZZER (the D13 drive line), pad 2 on /GND. Placed immediately
    west of BUZ1 with a 5.18 mm courtyard gap, same pattern as the SENS
    external-button headers (ADR-026). Nothing is switched or cut - the
    on-board buzzer keeps sounding and whatever is plugged into J5 sees
    exactly the same signal.
    - LOAD LIMIT, documented in ADR-034 and the README assembly notes. The
    buzzer is a PASSIVE piezo driven straight off the pin ("no series
    resistor needed", versions/v0-buzzer/HARDWARE.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
    [lemon-piano.kicad_pcb, lemon-piano.kicad_sch]
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2026-08-05 feat(v6): bench instruments + T0-T7 protocol to qualify the power source
    The cell is on the IP5356 and a KWS-X1 is on hand, but there is no PCB yet —
    which is the right order, because every open risk lives in the module, not the
    board. Two Nano-based PlatformIO instruments (both compile green) and a
    protocol with pass/fail criteria.
    psu-probe: the Nano IS the voltmeter, there being no DMM in the parts bin. AVcc
    via the ATmega's internal 1.1 V bandgap (the same node the piano's ADC uses as
    its reference, so it is the number that matters, and it needs no parts), the
    cell on A1 (1S tops out at 4.2 V < AVcc, so direct, no divider), and an EEPROM
    boot counter that distinguishes a source that H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
    [main.cpp]
2026-08-05 Revert "feat(v6): bench instruments + T0-T7 protocol to qualify the power source"
    This reverts commit fa34a851b71cbbf56526ca195c7d96f17590bad4.
    [main.cpp]
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2026-09-06 feat(pcb): v0.7.0 — Nano turned back to USB-WEST for enclosure cable access
    The user wants the mini-USB to leave the board on the left, away from the
    SENS buttons, so the cable can be plugged in with the Nano seated once the
    enclosure exists (annotated screenshot of the v0.6.0 render). Since the
    Nano's pinout is fixed (ADR-015), USB-west means digital column north /
    analog column south, so the LED bar moves to the north edge and the keys
    header to the south edge in the same change.
    Board (ADR-035/036/037):
    - U1 analog = SOUTH row, pin 1 D13 west (rot 90); U2 digital = NORTH row,
    pin 1 TX1 east (rot 270). D12/D13 flank the USB at x=132.22.
    - LED bar north, centred, LED1 at the EAST (foll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
    [lemon-piano-v0.7.0.step, lemon-piano.kicad_pcb, lemon-piano.kicad_sch]
2026-09-06 feat(pcb): v0.7.1 — "Created with ♥ by Multitec." maker's mark on the top-left silk
    Cosmetic silk-only change, so a PATCH bump per the repo's version rule. No
    footprint, pad, net, hole or outline change: the placements, netlist, holes,
    schematic and all three physical gates are the v0.7.0 board unchanged — only
    F.SilkS grew (ADR-038).
    A large "Created with ♥ by Multitec." fills the ~39 x 40... x 16 mm free
    rectangle the USB-west flip left in the top-left / west block (below the
    C1/C3 caps, above D2/L1, left of the socket, spanning the left anchor the
    user said to use). Two left-justified lines at 3.5 mm height, 0.40 mm stroke:
    "Created with ♥" / "by Multitec.".
    The heart is a FIL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
    [lemon-piano-v0.7.1.step, lemon-piano.kicad_pcb, lemon-piano.kicad_sch]
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2026-09-09 model-design: v4 of the enclosure (PCB raised to the lid) and of the fruit arc
    Sergio spotted the flaw with the printed box in his hands: the Nano window and
    the LED slot in the lid were looking at 22 mm of air, because the PCB sits at
    the bottom. So the board goes up.
    - Standoffs 4 -> 9 mm: the PCB's top face moves from z 7.6 to z 12.6. The
    ceiling is the Dupont on the pin strips (16.5), not the Nano, which now ends
    1.6 mm below the visible face and can be swapped through its window. The
    LEDs get soldered 11.6 mm raised; the 15 mm filter capacitor clears by 2.
    - The two panel buttons leave the lid for the front wall, in a column, + above
    and - below, hole 6.3 = 5.0 thread + 0.8 com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
    [base.stl, centro.stl, este.stl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]
2026-09-09 model-design: v5 of the enclosure -- the lid becomes a mask and the box drops 6.2 mm
    Sergio's second pass: holes with plenty of clearance for the two capacitors,
    the choke, the diodes and the key connector, plus holes for the internal tact
    switches, so the PCB can sit as close to the lid as possible and the components
    show.
    Once the tall parts have holes, the ceiling is set by what has NO hole: the M2
    screw head on the standoffs. Standoffs 9 -> 17.3 mm put the board's top face at
    z 20.9, 2.5 mm under the lid; the box goes 29.6 -> 23.4 (26.6 assembled, from
    32.8). Six openings over the board, the two capacitors sharing one as he asked.
    The mini-USB channel is gone -- the Nano's connector now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
    [base.stl, tapa.stl]
2026-09-09 model-design: v5 of the fruit arc -- the puzzle joint finally locks
    Sergio, with the v4 arc assembled: the pieces slide in and out along the arc,
    so they would need glue. The neck size was never the problem: the two RELIEF
    HOLES sat on the joint line and opened the female's mouth to 7.70 mm against a
    7.10 mm head, so the head walked straight out. The old check passed it because
    it compared a formula and never looked at the relief holes.
    New profile is a keyhole: straight 4.4 mm neck plus a O8.4 head pushed 5.2 mm
    past the joint line. Mouth 4.70 against head 8.10, so pulling it apart would
    need 3.40 mm of deformation -- it only assembles by lowering one piece onto the
    other. Relief holes dro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
    [centro.stl, este.stl, oeste.stl]
2026-09-09 feat(v5.5): free play and the mode wheel, on the two buttons that were there
    FREE PLAY is the piano with the game taken out: the seven lemons become
    do re mi fa sol la si (C5..B5), nothing is scored, nothing is wrong, and the
    same lemon may be played over and over — the game's repeat filter is exactly
    backwards for an instrument. The LED bar becomes a pitch meter while a note
    sounds and shows only its two ends when idle, a shape the game's left-filling
    bar cannot produce. It is not a level: winning never advances into it.
    THE MODE WHEEL brings back the game-select switch V5 removed, as a gesture.
    Hold − for 3 s (with a charge meter and a climbing chirp from 1 s, so it
    announces itself b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
    [Arduino.h, main.cpp, piano_sim_test.cpp]
2026-09-10 model-design: v6 of the enclosure -- three fixes found with the parts in the box
    All three share one lesson: a component modelled as a plain brick hides its real
    features.
    - LED slot 5.0 -> 5.5. They rubbed because of v5 itself: with the board raised
    the LEDs are no longer soldered proud, so the slot became the socket the LED
    head enters rather than a peephole.
    - The volume trimmer is not on the module centreline. Measured from Sergio's
    photo, scaled by the 14.4 mm between the cradle rails: 3.0 mm west. The
    access becomes a 10.0 x 6.4 slot shifted west -- a slot because a handheld
    photo is easily 0.5 mm out and the screwdriver must still reach.
    - The amp's screw terminal fouled th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
    [base.stl, tapa.stl]
2026-09-12 review(pcb): v0.7.1 is silent because 220 ohm buys 4 counts, not because of the copper
    The assembled board boots and plays nothing. Re-derived the connectivity from
    the .kicad_pcb independently of the design tooling: 34/34 nets are one copper
    island each, no splits, no shorts, no non-GND copper inside the pour, Nano rows
    correct pin for pin. KiCad DRC agreed already -- and that is the point: DRC
    checks copper against the netlist, never the netlist against the intent.
    The whole touch signal is 4 ADC counts out of 1023. A 220 ohm pull-up only fires
    if hand -> body -> fruit -> clip stays under 56 kohm; dry skin is 100 kohm-1 Mohm
    per contact. One extra count of noise puts max(4, 2 x noise) abo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
    [main.cpp]
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

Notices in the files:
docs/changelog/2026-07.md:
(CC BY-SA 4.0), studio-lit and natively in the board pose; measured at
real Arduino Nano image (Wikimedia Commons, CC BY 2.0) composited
